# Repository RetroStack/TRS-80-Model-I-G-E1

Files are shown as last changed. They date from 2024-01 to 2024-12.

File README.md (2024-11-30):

# TRS-80 Model 1 (Rev G) Replica - E1

This project is a faithful reimplementation of the mainboard of the iconic TRS-80 Model 1 (Revision G) computer. My own revision, the E1, is designed to replicate the original system's functionality by using a PCB design 1-to-1 to the original, including components, interfaces, and even traces. The entire project is available under the MIT license.

E1 Replica

## Project Details

### Latest Files

In the "Latest" folder, you'll find the most up-to-date design files, including:

- Gerber files suitable for popular online PCB manufacturers like [PCBWay](/Latest/TRS80_Model_I_G_E1_Gerber_PCBWay.zip) and [JLCPCB](/Latest/TRS80_Model_I_G_E1_Gerber_JLCPCB.zip). Most manufacturers should be fine with either.
- A Bill of Materials (BOM) in both [CSV](/Latest/TRS80_Model_I_G_E1_BOM.csv) and [PDF](/Latest/TRS80_Model_I_G_E1_BOM.pdf) formats. (Also, see the list below.)
- Layers exported in PDF and SVG formats.
- The [full schematics](/Latest/TRS80_Model_I_G_E1_Schematics.pdf) of the E1 replica which is 1:1 to the original G board.
- A simple [Assembly Guide](/Latest/TRS80_Model_I_G_E1_AssemblyGuide.pdf) in PDF format.

### Implementation

E1 has been implemented using KiCAD 7. The KiCAD project files are included in this repository.

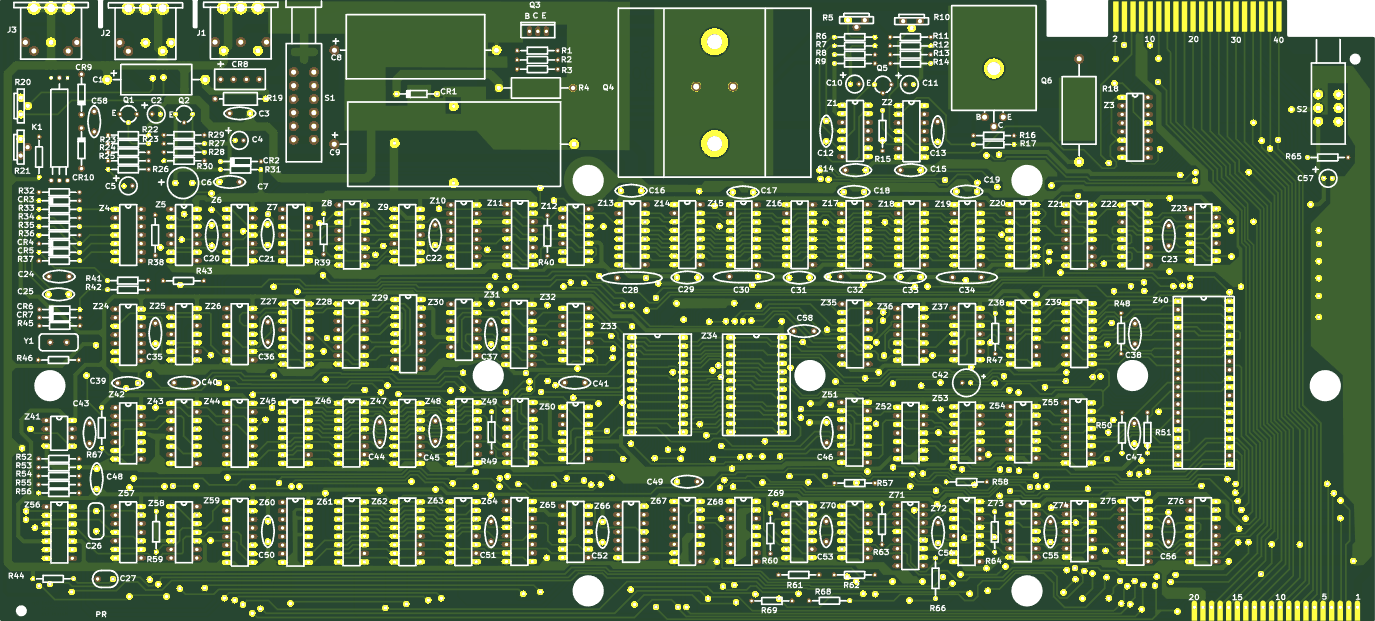
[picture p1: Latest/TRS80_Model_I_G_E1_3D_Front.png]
E1 Replica Front

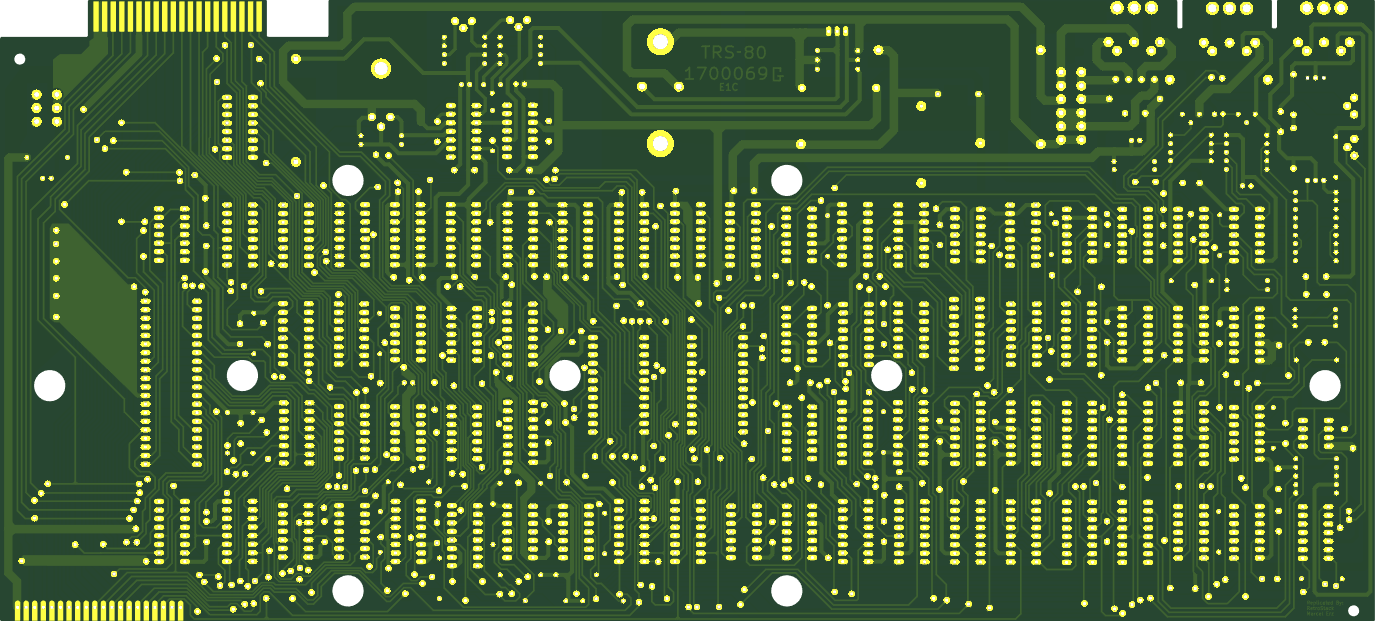
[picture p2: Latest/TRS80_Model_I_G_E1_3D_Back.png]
E1 Replica Back


### Assembly Instructions

For each step, check if there is a connection between pad 1, 8, 9, 16 on Z18 (all four corners of the dynamic RAM IC). That IC needs all 3 voltages with ground. If any of them are shorted, then you know what you did most recently. Finding the cause of the short should then be relatively easy.

1. (optional) Install sockets for all ICs. You probably want to skip Z3 and Z71, if you want to use DIP switches instead.
2. Install all diodes. These diodes are hard to read and if you accidentally mix them up, you might end up with incorrect voltages on the rails. Also, make sure to orient them correctly. There should be a black band on one side of the glass diode. Match this with the "thicker" side of the diode on the PCB. Installing first the shorter components will make sure you still can flip the board around and solder things easily.
3. Install all resistors. Resistors do not have an orientation. Skip the potentiometers for now. When installing the C*R67 (yes, there is a "C*"), this is an unmarked resistor between relay and the R21 potentiometer. This should be a 220 ohm 0.5W resistor (a bit larger than the others). There is another R67 which is next to Z42, which is a 4.7k Ohm resistor 0.25W (same size as most of the others).
4. Install all disc-like capacitors. Do not install the electrolytic capacitors yet! All other capacitors are rather small and orientation isn't important. The C58 next to the relay stays empty. Do not install it there. Instead, there is another (!!!) C58 next to the ROMs in the middle of the PCB.
5. Install all transistors, including the ones with the heatsinks. The TIP29 should go into Q3 (metal side away from board towards the Q3 label) while the TIP32C should go into Q6 (lay flat with heatsink; bend legs wit needle-nose pliers to fit). Don't forget to add thermal paste between heatsink and transistors. Make sure to add the screws and nuts and that it fits tightly as the screws themself connect traces. Not having them properly installed will result in a non-functioning system. The smaller black transistors have one flat side. These should all face towards the bottom of the board towards all the ICs (the middle leg needs to be bend slightly out to fit).
6. Install the crystal (no orientation), relay (match orientation on PCB; three legs towards the bottom), full-bridge rectifier (CR8; match "+" marking on component with PCB marking), all DIN connectors, both switches, keyboard connector (if bend, bend it upwards - towards the CPU to fit in the case), and potentiometers (only goes in one way). You can also install the DIP switches, if you go with that (numbers on the left side and "ON" label on the right).
7. Install all electrolytic capacitors. Make sure the orientation is correct! Modern capacitors mark the "-" side. On the PCB, the positive side is marked. All electrolytic capacitors on the PCB are oriented the same way EXCEPT C42 (!!!). Incorrect orientation may result in a small explosion (loud and smokey, but probably not dangerous).
8. Only install Z1 & Z2 to calibrate the power supply. Don't install any of the other ICs yet!!!
9. Get Multimeter ready in voltage mode. Connect power, turn on S1. If something starts to smell burned, turn S1 off and disconnect power.
10. Check voltage between pad 1 (-5V) and pad 16 (GND) on Z18. It should be around -5.1V to -5.2V. Since this is clamped with a zener diode, this should be pretty accurate. There is nothing that needs to be calibrated here. If the voltage goes beyond -5.3V, check R19 (may be really hot! careful!). If R19 is hot to the touch, your power supply is probably broken. (I've seen this on one power supply while another one didn't have that problem.)
11. Check voltage between pad 8 (+12V) and pad 16 (GND) on Z18. It should be around +12.0V. If it isn't, change the R10 potentiometer. If it is +/-0.5V off, then this is fine. But, try to get it as close to the desired voltage as possible.
12. (You need to calibrate +12V first before going to this next step!!!) Check voltage between pad 9 (+5V) and pad 16 (GND) on Z18. It should be around +5.0V. If it isn't, change the R5 potentiometer. If it is +/-0.5V off, then this is fine. But, also here, try to get it close to the desired voltage.
13. Re-check all the voltages after calibration, just to be sure.
14. Turn off S1 and disconnect power. Do this for each of the following steps. After each change, re-check the voltages at Z18 to find shorts quickly.
15. Start inserting the ICs. Focus on the 74LSxx ICs first. They are cheap and are easily recoverable in case there is a short somewhere and you start frying ICs. May be do 2-4 chips at a time and re-check the voltages at Z18. Do this systematically from left to right and top to bottom, so you know which you inserted most recently. If one of the voltages changes significantly at Z18 (+/- 2V and more), then you probably have a short with the most recent ICs. Do not insert the CPU, ROMs, character generator, and RAMs (static (2102) and dynamic ones (4116)) for now. They are expensive to replace if they fry.
16. Insert the 74Cxx ICs. These ICs are also cheap, but they are very sensitive. If all voltages are good, then they are good to install.
17. Connect to a monitor. Use a CRT, if possible, as video calibration is easier. LCD works too, but the reaction time is slow and requires a longer wait time after each change.
18. After turning on monitor and S1, you should see white blocks on a black background. If you don't see it, try changing R20 (vertical sync) and R21 (horizontal sync). If all fails, try to center both potentiometer. This usually results in a non-optimal picture, but a picture non-the-less. You can then calibrate.
19. (Don't forget to turn off system!) Insert the static video RAM (2102). These ICs only require +5V.
20. Now you need to configure the memory addresses and the memory configuration. With DIP switches, configure as follows:

- (memory location configuration) Z3: Switch 1 to the left, while all others are to the right. This is the configuration for 12k ROM and 16k RAM.
- (memory type configuration) Z71: Switch 1, 3, 5 to the right while all others are to the left. This is the configuration for 16k RAM modules.

21. Insert the dynamic RAM (4116). These ICs require all three voltages.
22. Insert CPU. Not much should have changed from the video calibration up until now. The next step will change that.
23. Insert character generator. Instead of white blocks, you should see (random) characters. The system doesn't clear the video memory yet since no ROM is installed.
24. Install ROM. This should be a Level II v1.3. If you don't have this, you probably need additional circuity to make these work. You can also burn the [diag ROM](https://github.com/misterblack1/trs80-diagnosticrom/blob/main/trs80m13diag.bin) on a 2k ROM to test the system. The diag ROM should work for all revisions of the TRS-80 Model 1.
25. At this point, you should see a prompt showing "Memory Size?" that keeps blinking (if it is the normal system ROM). The reason for the blinking is that the keyboard is not yet connected and the system recognizes keypresses. Install the keyboard with the IDC cable (if you installed a header).
26. Now, you should be able to use the system. Try to hold the left SHIFT key and press the right arrow key and the text size should increase, switching the video modes. (It is OK when some characters are skipped. That is normal.) The CLEAR key should reset it to the original video mode and clear the screen.
27. Try running a "Hello World!" program: 10 PRINT "Hello World!" (Return) 20 GOTO 10 (Return) RUN (Return). You can stop with the BREAK key.

### Ordering Instructions

When ordering the board from a PCB manufacturer, you can select the following to get a more faithful version of the board:

```
Dimension: 407mm x 184mm
Layers: 2
Base Material: FR-4 TG 135-140 (and up)
PCB Thickness: 1.6mm
PCB Color: Green
Silkscreen Color: White
Via Covering: Untented
Surface Finish: Lead Free HASL
Outer Copper Weight: 1oz
Gold Fingers / Card Edge: yes (chamfer: 30 degrees)
Castellated Holes: no
```

Additionally, supply the following comment for the manufacturer:

> Card edge is only on the upper right. The bottom right is just a connector and does not need to be chamfered.
>
> There are some missing pads on the top layer. That is correct. Please leave them as-is.

This addresses recurring questions from some of the interesting designs that were used on the original board which was replicated. See the ["Curiosities"](/Curiosities.md) page.

### Bill of Materials (BOM)

Below is a list of materials needed to assemble a complete system. Please note that the links and prices (scroll to the right to see them; as of January 22, 2024) will not be updated in the future and should only be used as a reference for locating the correct items.

Note: Links and alternatives are provided to assist you in finding the necessary components. I cannot guarantee the complete accuracy or reliability of all these links and alternatives. Please check it for yourself!

| Reference | Qty | Description | Source Comment | Source Cost USD | Source Total Cost USD | Source |
| --- | --- | --- | --- | --- | --- | --- |
| C1 | 1 | 220uF 16V polarized capacitor | | 1.48 | 1.48 | [Mouser](https://www.mouser.com/ProductDetail/598-227TTA050M) |
| C2, C4, C5, C10, C11, C57 | 6 | 10uF 16V polarized capacitor | | 0.29 | 1.74 | [Mouser](https://www.mouser.com/ProductDetail/598-106RMR050M) |
| C3, C7, C14, C15 | 4 | 0.01uF 24V (103) capacitor | | 0.23 | 0.92 | [Mouser](https://www.mouser.com/ProductDetail/594-D103Z25Z5VF63L6R) |
| C6 | 1 | 100uF 16V polarized capacitor | | 0.37 | 0.37 | [Mouser](https://www.mouser.com/ProductDetail/647-UVZ1J101MPD) |
| C8 | 1 | 2200uF 35V polarized capacitor | | 5.31 | 5.31 | [Mouser](https://www.mouser.com/ProductDetail/598-228TTA063M) |
| C9 | 1 | 10000uF 16V polarized capacitor | | 7.87 | 7.87 | [Mouser](https://www.mouser.com/ProductDetail/598-109TTA025M) |
| C12, C13 | 2 | 470pF (471) capacitor | | 0.23 | 0.46 | [Mouser](https://www.mouser.com/ProductDetail/594-D471K20Y5PH6UJ5R) |
| C16, C17, C18, C19, C22, C23, C28, C29, C30, C31, C32, C33, C34, C35, C36, C37, C38, C39, C40, C41, C44, C45, C46, C47, C48, C49, C50, C51, C52, C53, C54, C55, C56, C58 | 34  | 0.1uF 25V (104) capacitor | | 0.17 | 5.78 | [Mouser](https://www.mouser.com/ProductDetail/594-K104K10X7RF53L2) |
| C20 | 1 | 330pF (331) capacitor | | 0.3 | 0.3 | [Mouser](https://www.mouser.com/ProductDetail/594-F331K29Y5RP6UK5R) |
| C21 | 1 | 750pF (750) capacitor | | 0.37 | 0.37 | [Mouser](https://www.mouser.com/ProductDetail/80-C322C751K3G5TA) |
| C24, C25 | 2 | 220pF (221) capacitor | | 0.23 | 0.46 | [Mouser](https://www.mouser.com/ProductDetail/594-D221K20Y5PF63J5R) |
| C26 | 1 | 0.047uF (47nF) capacitor | | 1.9 | 1.9 | [Mouser](https://www.mouser.com/ProductDetail/594-222236755473) |
| C27 | 1 | 0.022uF (22nF) capacitor | | 1.34 | 1.34 | [Mouser](https://www.mouser.com/ProductDetail/594-2222-366-45223) |
| C42 | 1 | 22uF 16V polarized capacitor | | 0.1 | 0.1 | [Mouser](https://www.mouser.com/ProductDetail/710-860010372002) |
| C43 | 1 | 47pF (47) capacitor | | 0.4 | 0.4 | [Mouser](https://www.mouser.com/ProductDetail/594-S470K25SL0N63L6R) |
| CR1 | 1 | 1N4735 Zener diode | | 0.25 | 0.25 | [Mouser](https://www.mouser.com/ProductDetail/512-1N4735A) |
| CR2 | 1 | 1N5231 Zener diode | | 0.15 | 0.15 | [Mouser](https://www.mouser.com/ProductDetail/512-1N5231B) |
| CR3, CR4, CR5, CR6, CR7 | 5 | 1N4148 | Diode | 0.1 | 0.5 | [Mouser](https://www.mouser.com/ProductDetail/512-1N4148) |
| CR8 | 1 | MDA202 Diode bridge, +ve/AC/AC/-ve | Replacement | 0.61 | 0.61 | [Mouser](https://www.mouser.com/ProductDetail/621-KBP210G) |
| CR9, CR10 | 2 | 1N982 Schottky diode | Replacement, Lower (39V instead of 75V) | 0.26 | 0.52 | [Mouser](https://www.mouser.com/ProductDetail/78-1N4754A-TAP) |
| J1, J2, J3 | 3 | 5-pin DIN connector (5-pin DIN-5 stereo) | For metal connector only. The plastic plugs don't fit in it. | 0.386 | 1.158 | [AliExpress](https://www.aliexpress.us/item/2255801077942335.html) |
| J100 | 1 | 01x20 Generic connector, single row, 01x20 | | 0.5 | 0.5 | [Mouser](https://www.mouser.com/ProductDetail/649-1012937992002BLF) |
| K1 | 1 | Relay SPST, Normally Open | Slightly smaller than original | 14.84 | 14.84 | [DigiKey](https://www.digikey.com/en/products/detail/sensata-cynergy3/S2-05P/4425813) |
| Q1 | 1 | 2N3904 0.2A Ic, 40V Vce, Small Signal NPN Transistor, TO-92 | | 0.35 | 0.35 | [Mouser](https://www.mouser.com/ProductDetail/512-2N3904BU) |
| Q2, Q5 | 2 | 2N3906 -0.2A Ic, -40V Vce, Small Signal PNP Transistor, TO-92 | | 0.28 | 0.56 | [Mouser](https://www.mouser.com/ProductDetail/512-2N3906BU) |
| Q3 | 1 | TIP29A (BCE) NPN transistor | | 1.01 | 1.01 | [Mouser](https://www.mouser.com/ProductDetail/863-TIP29AG) |
| Q4 | 1 | 2N6594 (BEC) PNP transistor | Replacement (Other: RS2040, MJ2955G) | 4.73 | 4.73 | [Mouser](https://www.mouser.com/ProductDetail/863-MJ2955G) |
| Q6 | 1 | MJE34 (BCE) PNP transistor | Replacement | 0.67 | 0.67 | [Mouser](https://www.mouser.com/ProductDetail/511-TIP32C) |
| - | 1 | Q4 Heatsink | | 1.01 | 1.01 | [Mouser](https://www.mouser.com/ProductDetail/532-506007B00) |
| - | 1 | Q6 Heatsink | Smaller than original | 0.3 | 0.3 | [Mouser](https://www.mouser.com/ProductDetail/532-507302B00) |
| R1 | 1 | 68 Resistor 0.25W | | 0.1 | 0.1 | [Mouser](https://www.mouser.com/ProductDetail/603-CFR-25JB-52-68R) |
| R2 | 1 | 2.7k Resistor 0.25W | | 0.1 | 0.1 | [Mouser](https://www.mouser.com/ProductDetail/603-CFR-25JR-522K7) |
| R3 | 1 | 750 Resistor 0.25W | | 0.1 | 0.1 | [Mouser](https://www.mouser.com/ProductDetail/603-CFR-25JB-52-750R) |
| R4 | 1 | 0.33 Resistor 2W | | 0.45 | 0.45 | [Mouser](https://www.mouser.com/ProductDetail/603-CFR2WSJT-73-0R33) |
| R5, R10 | 2 | 1k Potentiometer | | 0.57 | 1.14 | [Mouser](https://www.mouser.com/ProductDetail/531-PT10H-1K-S) |
| R6, R7, R16, R53 | 4 | 1.2k Resistor 0.25W | | 0.1 | 0.4 | [Mouser](https://www.mouser.com/ProductDetail/603-CFR-25JB-52-1K2) |
| R8 | 1 | 100k Resistor 0.25W | | 0.1 | 0.1 | [Mouser](https://www.mouser.com/ProductDetail/603-CFR-25JB-52-100K) |
| R9, R11, R12 | 3 | 3.3k Resistor 0.25W | | 0.1 | 0.3 | [Mouser](https://www.mouser.com/ProductDetail/603-CFR-25JB-52-3K3) |
| R13 | 1 | 2.2k Resistor 0.25W | | 0.1 | 0.1 | [Mouser](https://www.mouser.com/ProductDetail/603-CFR-25JT-52-2K2) |
| R14 | 1 | 12k Resistor 0.25W | | 0.1 | 0.1 | [Mouser](https://www.mouser.com/ProductDetail/603-CFR-25JB-52-12K) |
| R15 | 1 | 1.5k Resistor 0.25W | | 0.1 | 0.1 | [Mouser](https://www.mouser.com/ProductDetail/603-CFR-25JT-52-1K5) |
| R17 | 1 | 2k Resistor 0.25W | | 0.1 | 0.1 | [Mouser](https://www.mouser.com/ProductDetail/603-CFR-25JB-52-2K) |
| R18 | 1 | 5.6 Resistor 3W | | 0.57 | 0.57 | [Mouser](https://www.mouser.com/ProductDetail/279-EP3WSS5R6J) |
| R19, C_R67 | 2 | 220 Resistor 0.5W | | 0.1 | 0.1 | [Mouser](https://www.mouser.com/ProductDetail/603-CFR-50JB-52-220R) |
| R20, R21 | 2 | 100k Potentiometer | | 0.57 | 1.14 | [Mouser](https://www.mouser.com/ProductDetail/531-PT10H-100K-S) |
| R22 | 1 | 75 Resistor 0.25W | | 0.1 | 0.1 | [Mouser](https://www.mouser.com/ProductDetail/603-CFR-25JB-52-75R) |
| R23 | 1 | 120 Resistor 0.25W | | 0.1 | 0.1 | [Mouser](https://www.mouser.com/ProductDetail/603-CFR-25JB-52-120R) |
| R24 | 1 | 680k Resistor 0.25W | | 0.1 | 0.1 | [Mouser](https://www.mouser.com/ProductDetail/603-CFR-25JB-52-680K) |
| R25 | 1 | 1.6M Resistor 0.25W | | 0.1 | 0.1 | [Mouser](https://www.mouser.com/ProductDetail/603-CFR-25JB-52-1M6) |
| R26, R42 | 2 | 1M Resistor 0.25W | | 0.1 | 0.2 | [Mouser](https://www.mouser.com/ProductDetail/603-CFR-25JT-52-1M) |
| R27, R64 | 2 | 330 Resistor 0.25W | | 0.1 | 0.2 | [Mouser](https://www.mouser.com/ProductDetail/603-CFR-25JB-52-330R) |
| R28 | 1 | 270 Resistor 0.25W | | 0.1 | 0.1 | [Mouser](https://www.mouser.com/ProductDetail/603-CFR-25JB-52-270R) |
| R29 | 1 | 1.8k Resistor 0.25W | | 0.1 | 0.1 | [Mouser](https://www.mouser.com/ProductDetail/603-CFR-25JB-52-1K8) |
| R30 | 1 | 47 Resistor 0.25W | | 0.1 | 0.1 | [Mouser](https://www.mouser.com/ProductDetail/603-CFR-25JB-52-47R) |
| R31 | 1 | 10 Resistor 0.25W | | 0.1 | 0.1 | [Mouser](https://www.mouser.com/ProductDetail/603-CFR-25JT-52-10R) |
| R32, R43, R44, R47, R65 | 5 | 10k Resistor 0.25W | | 0.1 | 0.5 | [Mouser](https://www.mouser.com/ProductDetail/603-CFR-25JB-52-10K) |
| R33, R36 | 2 | 360k Resistor 0.25W | | 0.1 | 0.2 | [Mouser](https://www.mouser.com/ProductDetail/603-CFR-25JB-52-360K) |
| R34, R35, R38, R41, R45 | 5 | 470k Resistor 0.25W | | 0.1 | 0.5 | [Mouser](https://www.mouser.com/ProductDetail/603-CFR-25JB-52-470K) |
| R37 | 1 | 560k Resistor 0.25W | | 0.1 | 0.1 | [Mouser](https://www.mouser.com/ProductDetail/603-CFR-25JB-52-560K) |
| R39, R40, R48, R49, R50, R51, R57, R58, R59, R60, R61, R62, R63, R66, R67, R68, R69 | 17  | 4.7k Resistor 0.25W | | 0.1 | 1.7 | [Mouser](https://www.mouser.com/ProductDetail/603-CFR-25JB-52-4K7) |
| R46, R52 | 2 | 910 Resistor 0.25W | | 0.1 | 0.2 | [Mouser](https://www.mouser.com/ProductDetail/603-CFR-25JB-52-910R) |
| R54, R55 | 2 | 7.5k Resistor 0.25W | | 0.1 | 0.2 | [Mouser](https://www.mouser.com/ProductDetail/603-CFR-25JB-52-7K5) |
| R56 | 1 | 220k Resistor 0.25W | | 0.1 | 0.1 | [Mouser](https://www.mouser.com/ProductDetail/603-CFR-25JB-52-220K) |
| S1 | 1 | Power 4PST | No Cap | 4.34 | 4.34 | [DigiKey](https://www.digikey.com/en/products/detail/c-k/F4UEE/417520) |
| S2 | 1 | Reset DPST | Red Cap | 1.815 | 1.815 | [AliExpress](https://www.aliexpress.us/item/3256804467086494.html) |
| Y1 | 1 | 10.6445 MHz Two pin crystal | Only 10.6MHz | 0.73 | 0.73 | [Mouser](https://www.mouser.com/ProductDetail/449-LFXTAL028537BULK) |
| Z1, Z2 | 2 | LM723C Linear Regulator (adjustable) | | 1.04 | 2.08 | [Mouser](https://www.mouser.com/ProductDetail/595-UA723CN) |
| Z3, Z71 | 2 | 8-Bit DIP Switch | Replacement | 2.07 | 4.14 | [Mouser](https://www.mouser.com/ProductDetail/710-418117270908) |
| Z4 | 1 | LM3900 Quad operational amplifier | | 0.6 | 0.6 | [Mouser](https://www.mouser.com/ProductDetail/595-LM3900NE4) |
| Z5 | 1 | 74C00 quad 2-input NAND gate | 74HC00 works in a pinch, but suboptimal video. | ~2.50 | ~2.50 | eBay/Jameco |
| Z6, Z57 | 2 | 74C04 Hex Inverter | 74HC00 works in a pinch, but suboptimal video. | 2.49 | 4.98 | [Jameco](https://www.jameco.com/webapp/wcs/stores/servlet/ProductDisplay?productId=44231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) |
| Z7, Z69, Z70 | 3 | 74LS74 Dual D Flip-flop, Set & Reset | | 0.49 | 1.47 | [Mouser](https://www.mouser.com/ProductDetail/595-SN74LS74AN) |
| Z8 | 1 | 74LS153 Dual Multiplexer 4 to 1 | | 1.13 | 1.13 | [Mouser](https://www.mouser.com/ProductDetail/595-SN74LS153N) |
| Z9, Z42, Z52 | 3 | 74LS04 Hex Inverter | | 0.67 | 2.01 | [Mouser](https://www.mouser.com/ProductDetail/595-SN74LS04N) |
| Z10, Z11 | 2 | 74LS166 Shift Register 8-bit, parallel load | | 1.24 | 2.48 | [Mouser](https://www.mouser.com/ProductDetail/595-SN74LS166AN) |
| Z12, Z32, Z50, Z65 | 4 | 74LS93 Divide by 2 & 8 counter | | 3.04 | 12.16 | [Mouser](https://www.mouser.com/ProductDetail/595-SN74LS93N) |
| Z13, Z14, Z15, Z16, Z17, Z18, Z19, Z20 | 8 | 4116 16kBit x 1 Bit Dynamic RAM | | 3.95 | 31.6 | [Jameco](https://www.jameco.com/z/4116-15-Major-Brands-IC-4116-15-DRAM-16-384-Bit-16Kx1-150ns-5V_41339.html) |
| Z21 | 1 | 74LS156 Dual 2 to 4 lines Decoder/Demultiplexer, Open Collector | | 0.75 | 0.75 | [Mouser](https://www.mouser.com/ProductDetail/595-SN74LS156N) |
| Z22, Z38, Z39, Z44, Z55, Z60, Z67, Z68, Z72, Z75, Z76 | 11  | 74LS367 Hex buffer 3-State outputs | | 1.44 | 15.84 | [Mouser](https://www.mouser.com/ProductDetail/595-SN74LS367AN) |
| Z23, Z25, Z36, Z73 | 4 | 74LS32 Quad 2-input OR | | 0.56 | 2.24 | [Mouser](https://www.mouser.com/ProductDetail/595-SN74LS32N) |
| Z24, Z53 | 2 | 74LS132 Quad 2-input NAND Schmitt trigger | | 1.03 | 2.06 | [Mouser](https://www.mouser.com/ProductDetail/595-SN74LS132N) |
| Z26 | 1 | 74LS20 Dual 4-input NAND | | 1.28 | 1.28 | [Mouser](https://www.mouser.com/ProductDetail/595-SN74LS20N) |
| Z27, Z59 | 2 | 74LS175 4-bit D Flip-Flop, reset | | 1.02 | 2.04 | [Mouser](https://www.mouser.com/ProductDetail/595-SN74LS175N) |
| Z28 | 1 | 74LS174 Hex D-type Flip-Flop, reset | | 1.12 | 1.12 | [Mouser](https://www.mouser.com/ProductDetail/595-SN74LS174N) |
| Z29 | 1 | MCM6670 128 x 7 x 5 Character Generator | Adapter needed | | 0 | [GitHub](https://github.com/RetroStack/MCM776x_CharGen_Adapter) |
| Z30, Z37 | 2 | 74LS02 quad 2-input NOR gate | | 0.55 | 1.1 | [Mouser](https://www.mouser.com/ProductDetail/595-SN74LS02N) |
| Z31, Z35, Z43, Z49, Z51, Z64 | 6 | 74LS157 Quad 2 to 1 line Multiplexer | | 0.88 | 5.28 | [Mouser](https://www.mouser.com/ProductDetail/595-SN74LS157N) |
| Z33 | 1 | 2364 (20-pin Low) 2364 64kBit (8kb x 8) PROM | Adapter needed | | 0 | - |
| Z34 | 1 | 2332 (20- & 21-pin Low) 2332 32kBit (4kb x 8) PROM | Adapter needed | | 0 | - |
| Z40 | 1 | Z80 CPU | | 9.62 | 9.62 | [Mouser](https://www.mouser.com/ProductDetail/692-Z84C0010PEG) |
| Z41 | 1 | 75452 Dual-Peripheral Drivers for High-Current, High-Speed Switching | | 0.9 | 0.9 | [Mouser](https://www.mouser.com/ProductDetail/595-SN75452BP) |
| Z45, Z46, Z47, Z48, Z61, Z62, Z63 | 7 | 2102 1K Static RAM (SRAM) | 7th IC needed for lowercase mod | 2.95 | 20.65 | [Jameco](https://www.jameco.com/z/MM2102AN-4-National-Semiconductor-IC-MM2102AN-4-NMOS-SRAM-1024-Bit-1024x1-250ns-DIP-16_2287991.html) |
| Z54 | 1 | 74LS30 8-input NAND | | 1.18 | 1.18 | [Mouser](https://www.mouser.com/ProductDetail/595-SN74LS30N) |
| Z56, Z58 | 2 | 74LS92 Divide by 12 counter | | 3.27 | 6.54 | [Mouser](https://www.mouser.com/ProductDetail/595-SN74LS92N) |
| Z66 | 1 | 74LS11 Triple 3-input AND | | 0.91 | 0.91 | [Mouser](https://www.mouser.com/ProductDetail/595-SN74LS11N) |
| Z74 | 1 | 74LS00 quad 2-input NAND gate | | 0.57 | 0.57 | [Mouser](https://www.mouser.com/ProductDetail/595-SN74LS00N) |
| | 1 | DIP-8 Socket | Optional | 0.49 | 0.49 | [Jameco](https://www.jameco.com/z/6100-8-R-Jameco-ValuePro-IC-Socket-8-Pin-Machine-Tooled-Low-Profile-0-3-Inch-Wide_51626.html) |
| | 30  | DIP-14 Socket | Optional | 0.75 | 22.5 | [Jameco](https://www.jameco.com/z/14MTLP-Jameco-ValuePro-Socket-IC-14-Pin-Machine-Tooled-Low-Profile-0-3-Inch-Wide_37197.html) |
| | 39  | DIP-16 Socket | Optional | 0.85 | 33.15 | [Jameco](https://www.jameco.com/z/16MTLP-Jameco-ValuePro-Socket-IC-16-Pin-Machine-Tooled-Low-Profile-0-3-Inch-Wide_37402.html) |
| | 1 | DIP-18 Socket | Optional | 0.99 | 0.99 | [Jameco](https://www.jameco.com/z/18MTLP-Jameco-ValuePro-18-Pin-Machine-Tooled-Low-Profile-IC-Socket-0-3-Inch-Wide_65585.html) |
| | 2 | DIP-24 Socket | Optional | 1.49 | 2.98 | [Jameco](https://www.jameco.com/z/24MTLP-6-Jameco-ValuePro-24-Pin-Machine-Tooled-Low-Profile-IC-Socket-0-6-Inch-Wide_39351.html) |
| | 1 | DIP-40 Socket | Optional | 1.69 | 1.69 | [Jameco](https://www.jameco.com/z/40MTLP-Jameco-ValuePro-40-Pin-Machine-Tooled-Low-Profile-IC-Socket-0-6-Inch-Wide_41136.html) |

### RetroStack Libraries

To work with this KiCAD project, you'll need the RetroStack libraries for KiCAD. Please [follow this link](https://www.github.com/RetroStack/KiCAD-Libraries) to access and install these libraries.

## Main TRS-80 Model 1 Repository

For additional resources related to the TRS-80 Model 1, be sure to check out the [central page for the TRS-80 Model 1](https://www.github.com/RetroStack/TRS-80-Model-I) on [RetroStack](https://www.github.com/RetroStack).

## Support this Project

RetroStack is passionate about exploring and preserving the legacy of older computer systems. My work involves creating detailed documentation and videos to share the knowledge. I am also dedicated to reviving these classic systems by reimplementing them and offering replacement parts at no cost. If you're keen on supporting this unique project, I invite you to visit my [Patreon page](https://www.patreon.com/RetroStack). Your support would be immensely valuable and greatly appreciated!

## License

This project is licensed under the MIT License - see the [LICENSE](LICENSE) file for details.

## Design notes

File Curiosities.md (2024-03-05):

# TRS-80 Model 1 (Rev G) - Curiosities

The original board had multiple errors and strange implementations, often caused by the limited capabilities of the manufacturing process, but also to save money. The following sections discuss some of the stranger features on the original PCB board, which were replicated when possible.

## Additional Capacitor

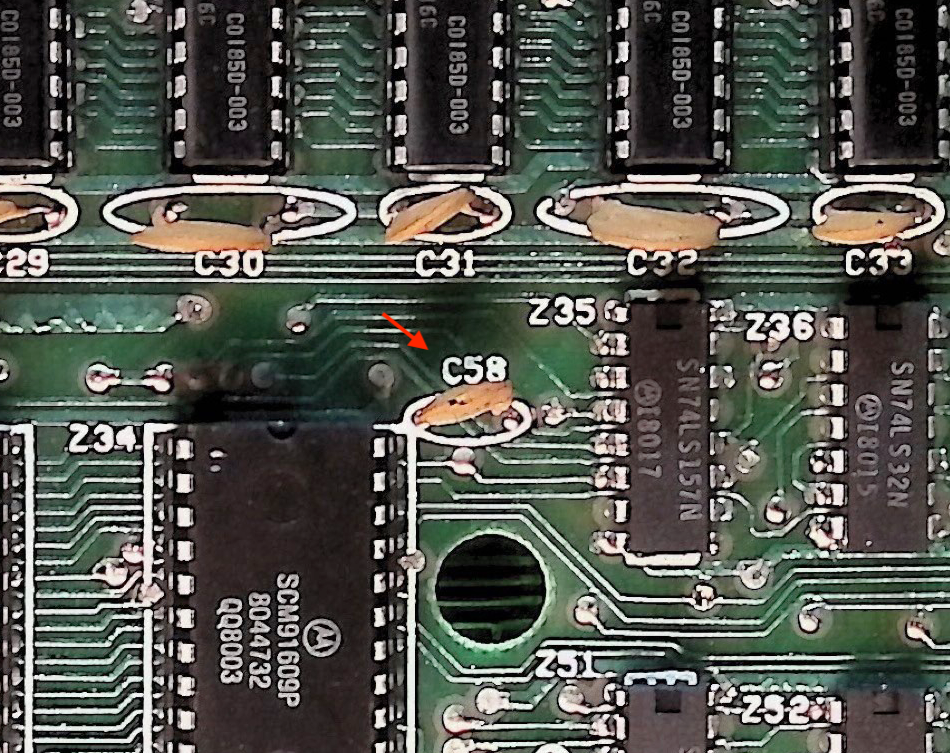
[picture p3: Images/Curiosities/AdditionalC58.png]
Additional Capacitor


Capacitor C58, located next to the ROMs, was never documented in the technical reference manual. My guess is that it was added later.

## Missing Capacitor

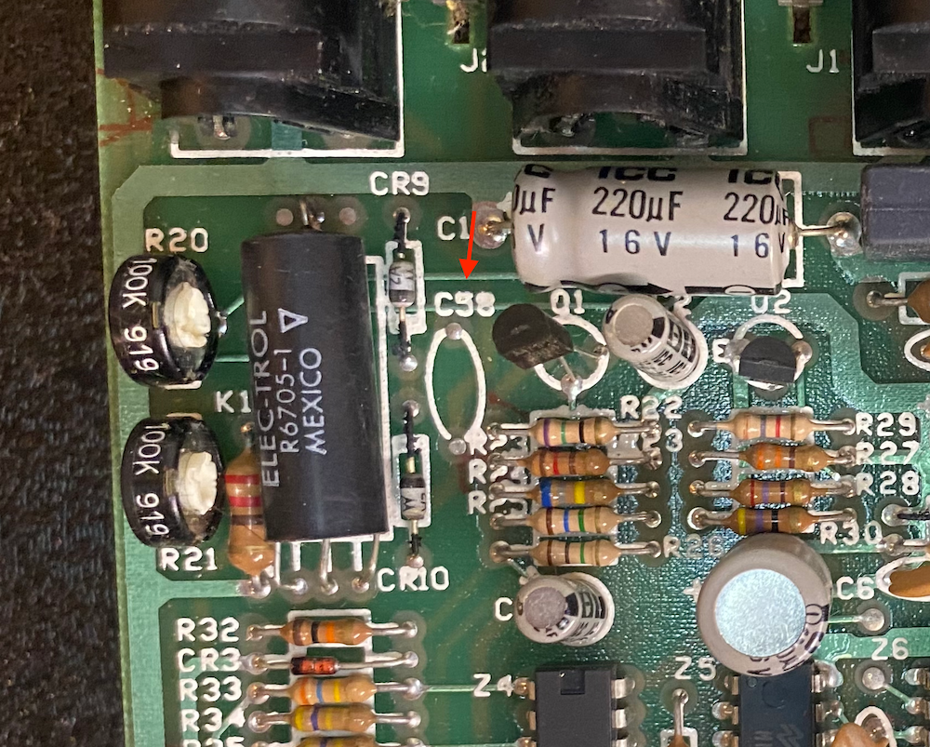
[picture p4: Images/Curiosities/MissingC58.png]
Missing Capacitor

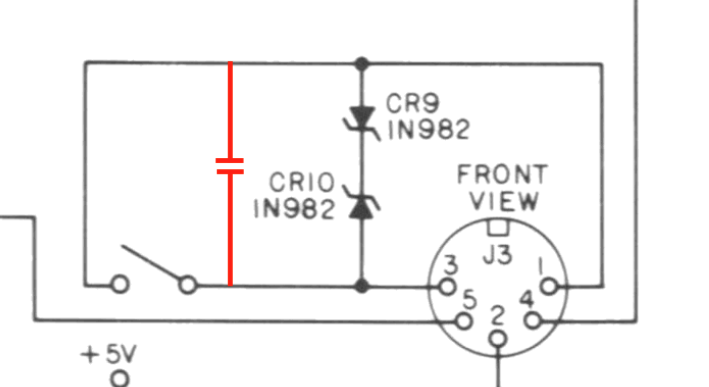
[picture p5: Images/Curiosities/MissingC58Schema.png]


There is, however, a capacitor missing on the board. This capacitor is also called C58 (yes, there are two of them) and is located right next to the relay. It is missing on all the boards I've seen, but I have added it to the schematics and included a note that it is missing on the PCB. This capacitor is actually part of the Cassette Remote control circuit and seems out of place there.

## Wrong Resistor

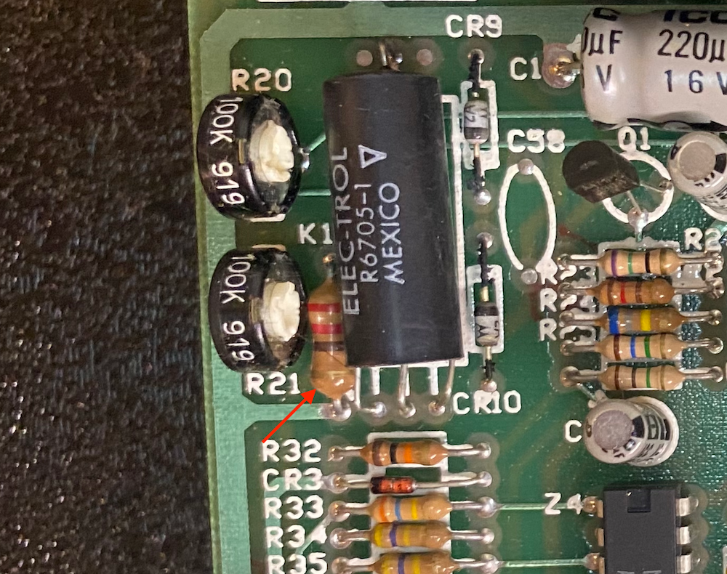
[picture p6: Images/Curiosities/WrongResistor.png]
Wrong Resistor

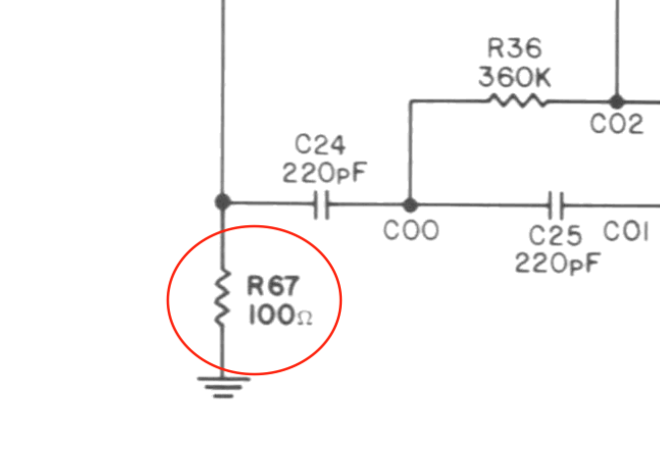
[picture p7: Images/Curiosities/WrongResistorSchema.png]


Next to the two potentiometers for the H- and V-Sync, there is supposed to be a 100 Ohm 0.25 Watt resistor, according to the technical documentation. However, on all the boards I have seen, there is actually a 220 Ohm 0.5 Watt resistor instead.

## Undocumented 8k RAM support

The board actually supports two different kinds of 8k ICs for the dynamic RAM. This is not documented in the technical reference manual or the user documentation. See Page 7 of the [new schematics](/Latest/TRS80_Model_I_G_E1_Schematics.pdf).

## Missing Pads (On the Top)

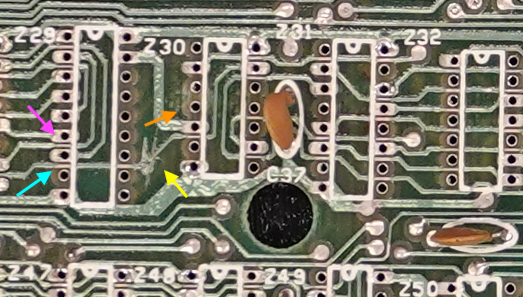
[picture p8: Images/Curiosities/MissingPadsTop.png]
Missing Pads on Original

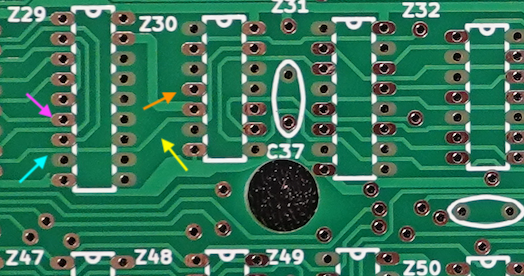
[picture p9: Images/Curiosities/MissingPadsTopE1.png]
Missing Pads on Replica


I’ve replicated the "missing pads" on the top of the board as they were on the original board. The pads are only connected at the bottom, so it's fine for them to be missing on the top.

But why was it done this way? At the time, the solder masks weren’t as precise and couldn't adequately cover the traces between pads (see purple/magenta and blue arrow). Bridging those pads and traces during soldering was (and still is) a common issue on these older boards (especially the traces or purple/magenta arrow). That isn’t the case with modern boards, but I still replicated this for the pads only (not the traces in between) to stay closer to the original without the risk of accidental bridging. I guess it's a good compromise.

Completely unconnected pins usually lacked pads on the top as well, but KiCAD doesn’t have an option for that, unfortunately. So, I kept them as they are (see orange arrow), meaning they have pads on both the top and bottom.

The yellow arrow is unrelated to this topic, but you can see the cut trace of the original board which is needed for the lower-case mod.

## Missing Pads (On the Bottom)

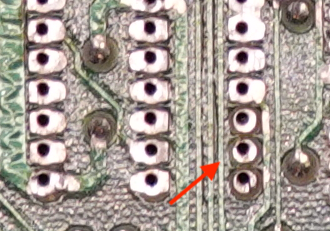
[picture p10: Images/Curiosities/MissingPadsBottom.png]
Missing Pads on Original

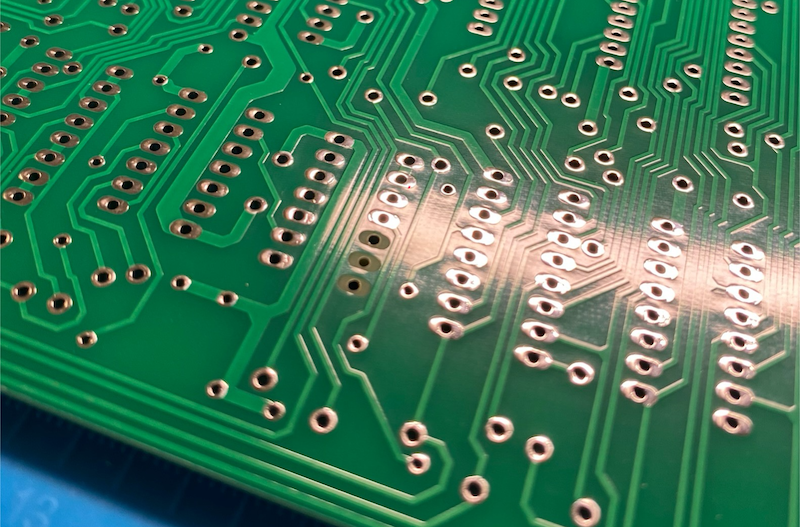
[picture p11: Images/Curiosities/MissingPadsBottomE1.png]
Missing Pads on Replica


I replicated three missing pads on the bottom of the board at Z69. While accurate to the original, it was a pain to solder the sockets to the pads while they rested on top of the board. I don’t use wave soldering as they did in the original, so that was just annoying. In the newest version of the board, I placed these pads back to make them easily solderable.

## Unused Vias

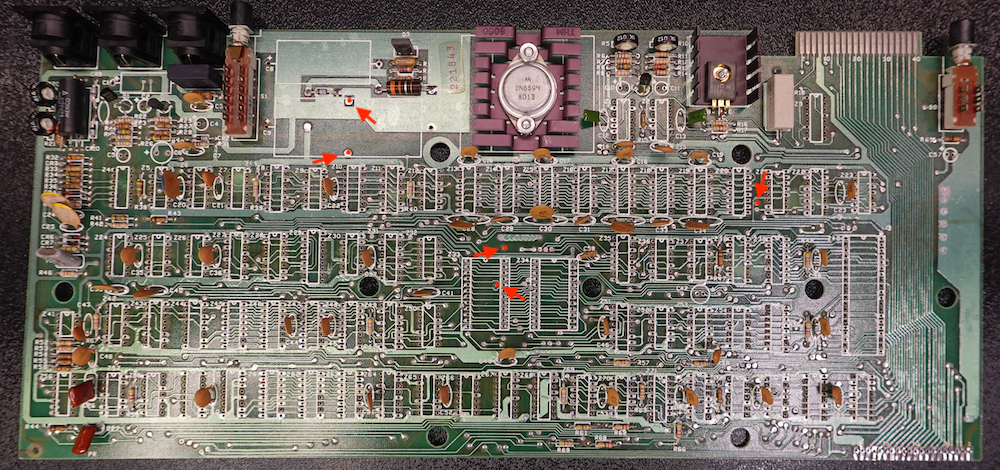
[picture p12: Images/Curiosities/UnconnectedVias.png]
Unconnected Vias


There are a bunch of unused vias on the board. I am not entirely sure why that is.

## Small Holes

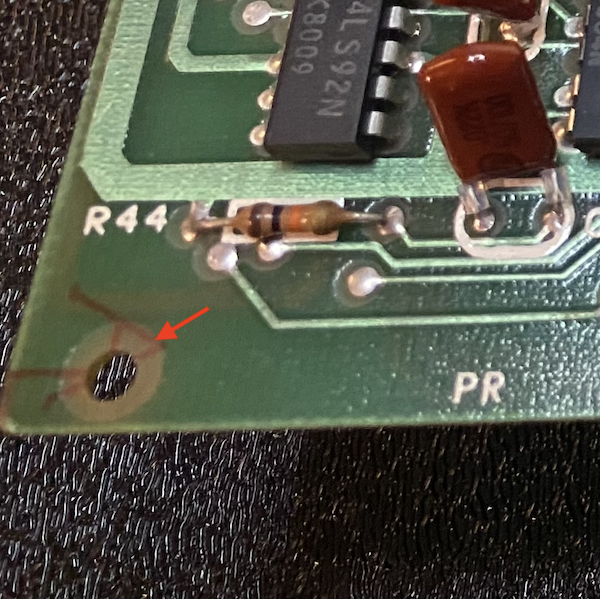
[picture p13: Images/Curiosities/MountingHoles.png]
Mounting Holes


At the edges of the board, you can see two rather small holes. These were used during the manufacturing process to keep the board in a known position, enabling the machines to create and assemble the board.

## Bumpy Traces and Zones

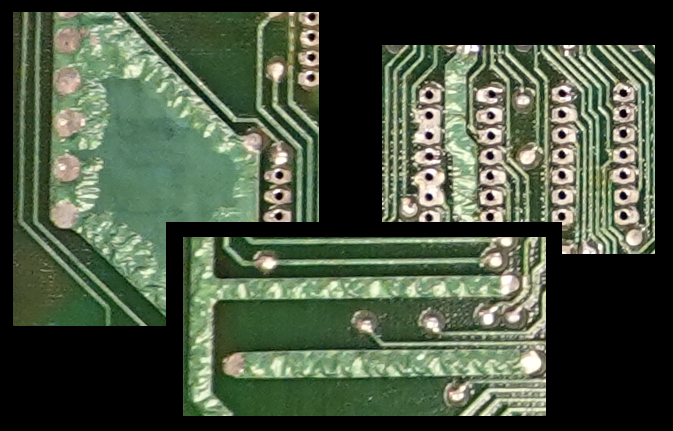
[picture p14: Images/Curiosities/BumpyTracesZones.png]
Bumpy Traces and Zones


If you ever wonder what these "bumpy" traces and fill zones are, they are not dissolving or anything of that nature. This is how they are supposed to be. The boards were assembled in this way. The traces and zones were tinned, then solder mask was applied, covering nearly everything. When the board was wave soldered with the components in place, these tinned traces melted again due to the heat and solidified shortly after. The tension of the solder mask kept them in somewhat random shapes and caused these bumps. You can actually see this if you put your soldering iron to a pad close to these bumps; you will see that the tin beneath the solder mask liquifies and can even be sucked out by a desoldering iron or pump.

Since the method of tinning has changed (using HASL nowadays) and I don't wave solder, this isn't happening anymore, and it is difficult and probably costly to replicate.

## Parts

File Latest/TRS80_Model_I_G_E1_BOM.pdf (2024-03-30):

### TRS80_Model_I_G_E1_BOM

SOURCE PCB REFERENCE | QTY | VALUE | COMPONENT NAME | COMPONENT DESCRIPTION | COMMENT
C1 | 1 | 220uF 16V | C_Polarized | Polarized capacitor
C2, C4, C5, C10, C11, C57 | 6 | 10uF 16V | C_Polarized | Polarized capacitor | C57 is located at the reset switch
C6 | 1 | 100uF 16V | C_Polarized | Polarized capacitor
C8 | 1 | 2200uF 35V | C_Polarized | Polarized capacitor
C9 | 1 | 10000uF 16V | C_Polarized | Polarized capacitor
C42 | 1 | 22uF 16V | C_Polarized | Polarized capacitor
C12, C13 | 2 | 470pF | C (471) | Unpolarized capacitor
C3, C7, C14, C15 | 4 | 0.01uF 24V | C (103) | Unpolarized capacitor
C16, C17, C18, C19, C22, C23, C28, C29, C30, C31, C32, C33, C34, C35, C36, C37, C38, C39, C40, C41, C44, C45, C46, C47, C48, C49, C50, C51, C52, C53, C54, C55, C56, C58 | 34 | 0.1uF 25V | C (104) | Unpolarized capacitor | C58 is located to the right of ROM B C58 next to the relay stays empty (!!!)
C20 | 1 | 330pF | C (331) | Unpolarized capacitor
C21 | 1 | 750pF | C (750) | Unpolarized capacitor
C24, C25 | 2 | 220pF | C (221) | Unpolarized capacitor
C43 | 1 | 47pF | C (47) | Unpolarized capacitor | C43 is located to the right of Z41
C26 | 1 | 0.047uF | C (47nF) | Unpolarized capacitor
C27 | 1 | 0.022uF | C (22nF) | Unpolarized capacitor
CR1 | 1 | 1N4735 | D_Zener | Zener diode
CR2 | 1 | 1N5231 | D_Zener | Zener diode
CR3, CR4, CR5, CR6, CR7 | 5 | 1N4148 | D | Diode
CR9, CR10 | 2 | 1N982 | D_Schottky | Schottky diode | Replacement can be lower than 75V
CR8 | 1 | MDA202 | D_Bridge_+AA- | Diode bridge, +ve/AC/AC/-ve | Replacement KBP210
J1, J2, J3 | 3 | Front View | DIN-5_180degree | 5-pin DIN connector (5-pin DIN-5 stereo)
J100 | 1 | Connector | Conn_01x20 | Generic connector, single row, 01x20
K1 | 1 | Relay_SPST-NO | TRS80_Model_I_Relay_NO | Relay SPST, Normally Open, EN50005 | Slightly smaller than original
Q1 | 1 | 2N3904 | 2N3904 | 0.2A Ic, 40V Vce, Small Signal NPN Transistor, TO-92
Q2, Q5 | 2 | 2N3906 | 2N3906 | -0.2A Ic, -40V Vce, Small Signal PNP Transistor, TO-92
Q3 | 1 | TIP29A | Q_NPN_BCE | NPN transistor, base/collector/emitter
Q4 | 1 | 2N6594 | Q_PNP_BEC | PNP transistor, base/emitter/collector | Replacement RS2040, MJ2955G
Q6 | 1 | MJE34 | Q_PNP_BCE | PNP transistor, base/collector/emitter | Replacement TIP32C
- | 1 | | | Q4 Heatsink
- | 1 | | | Q6 Heatsink | Smaller than original
R1 | 1 | 68 | | Resistor 0.25W (blue, grey, black, gold)
R2 | 1 | 2.7k | | Resistor 0.25W (red, violet, red, gold)
R3 | 1 | 750 | | Resistor 0.25W (violet, green, brown, gold)
R4 | 1 | 0.33 | | Resistor 2W (orange, orange, silver, gold)
R6, R7, R16, R53 | 4 | 1.2k | | Resistor 0.25W (brown, red, red, gold)
R8 | 1 | 100k | | Resistor 0.25W (brown, black, yellow, gold)
R9, R11, R12 | 3 | 3.3k | | Resistor 0.25W (orange, orange, red, gold)
R13 | 1 | 2.2k | | Resistor 0.25W (red, red, red, gold)
R14 | 1 | 12k | | Resistor 0.25W (brown, red, orange, gold)
R15 | 1 | 1.5k | | Resistor 0.25W (brown, green, red, gold)
R17 | 1 | 2k | | Resistor 0.25W (red, black, red, gold)
R18 | 1 | 5.6 | | Resistor 3W (green, blue, gold, gold)
R19, C_R67 | 2 | 220 | | Resistor 0.5W (red, red, brown, gold) | C_R67 is located to the left of K1
R22 | 1 | 75 | | Resistor 0.25W (violet, green, black, gold)
R23 | 1 | 120 | | Resistor 0.25W (brown, red, brown, gold)
R24 | 1 | 680k | | Resistor 0.25W (blue, grey, yellow, gold)
R25 | 1 | 1.6M | | Resistor 0.25W (brown, blue, green, gold)
R26, R42 | 2 | 1M | | Resistor 0.25W (brown, black, green, gold)
R27, R64 | 2 | 330 | | Resistor 0.25W (orange, orange, brown, gold)
R28 | 1 | 270 | | Resistor 0.25W (red, violet, brown, gold)
R29 | 1 | 1.8k | | Resistor 0.25W (brown, grey, red, gold)
R30 | 1 | 47 | | Resistor 0.25W (yellow, violet, black, gold)
R31 | 1 | 10 | | Resistor 0.25W (brown, black, black, gold)
R32, R43, R44, R47, R65 | 5 | 10k | | Resistor 0.25W (brown, black, orange, gold) | R44 is located in the bottom left corner R65 is located at the reset switch
R33, R36 | 2 | 360k | | Resistor 0.25W (orange, blue, yellow, gold)

1

R34, R35, R38, R41, R45 | 5 | 470k | | Resistor 0.25W (yellow, violet, yellow, gold)
R37 | 1 | 560k | | Resistor 0.25W (green, blue, yellow, gold)
R39, R40, R48, R49, R50, R51, R57, R58, R59, R60, R61, R62, R63, R66, R67, R68, R69 | 17 | 4.7k | | Resistor 0.25W (yellow, violet, red, gold) | R67 is located to the left of Z42
R46, R52 | 2 | 910 | | Resistor 0.25W (white, brown, brown, gold)
R54, R55 | 2 | 7.5k | | Resistor 0.25W (violet, blue, red, gold)
R56 | 1 | 220k | | Resistor 0.25W (red, red, yellow, gold)
R5, R10 | 2 | 1k | R_Potentiometer | Potentiometer
R20, R21 | 2 | 100k | R_Potentiometer | Potentiometer
S1 | 1 | Power | SW_4PST
S2 | 1 | Reset | SW_DPST
Y1 | 1 | 10.6445 MHz | Crystal | Two pin crystal | 10.6MHz replacement
Z1, Z2 | 2 | LM723C | LM723C_1 | Linear Regulator (adjustable)
Z3, Z71 | 2 | Jumper | TRS80ModelIX71 | 8-Bit DIP Switch | Replacement
Z4 | 1 | LM3900 | LM3900 | Quad operational amplifier
Z5 | 1 | 74C00 | 74LS00 | quad 2-input NAND gate
Z6, Z57 | 2 | 74C04 | 74LS04 | Hex Inverter
Z7, Z69, Z70 | 3 | 74LS74 | 74LS74 | Dual D Flip-flop, Set & Reset
Z8 | 1 | 74LS153 | 74LS153 | Dual Multiplexer 4 to 1
Z9, Z42, Z52 | 3 | 74LS04 | 74LS04 | Hex Inverter
Z10, Z11 | 2 | 74LS166 | 74LS166 | Shift Register 8-bit, parallel load
Z12, Z32, Z50, Z65 | 4 | 74LS93 | 74LS93 | Divide by 2 & 8 counter
Z13, Z14, Z15, Z16, Z17, Z18, Z19, Z20 | 8 | MK4116 | 4116 | 16kBit x 1 Bit Dynamic RAM
Z21 | 1 | 74LS156 | 74LS156 | Dual 2 to 4 lines Decoder/Demultiplexer, Open Collector
Z22, Z38, Z39, Z44, Z55, Z60, Z67, Z68, Z72, Z75, Z76 | 11 | 74LS367 | 74LS367_Split | Hex buffer 3-State outputs
Z23, Z25, Z36, Z73 | 4 | 74LS32 | 74LS32 | Quad 2-input OR
Z24, Z53 | 2 | 74LS132 | 74LS132 | Quad 2-input NAND Schmitt trigger
Z26 | 1 | 74LS20 | 74LS20 | Dual 4-input NAND
Z27, Z59 | 2 | 74LS175 | 74LS175 | 4-bit D Flip-Flop, reset
Z28 | 1 | 74LS174 | 74LS174 | Hex D-type Flip-Flop, reset
Z29 | 1 | MCM6670 | MCM6670P | 128 x 7 x 5 Character Generator | Adapter needed
Z30, Z37 | 2 | 74LS02 | 74LS02 | quad 2-input NOR gate
Z31, Z35, Z43, Z49, Z51, Z64 | 6 | 74LS157 | 74LS157 | Quad 2 to 1 line Multiplexer
Z33 | 1 | 2364_20L | 2364_20L | 2364 64kBit (8kb x 8) PROM | Adapter needed
Z34 | 1 | 2332_20L_21L | 2332_20L_21L | 2332 32kBit (4kb x 8) PROM | Adapter needed
Z40 | 1 | Z80CPU | Z80 | Z80 CPU
Z41 | 1 | 75452 | 75452 | Dual-Peripheral Drivers for High-Current, High-Speed Switching
Z45, Z46, Z47, Z48, Z61, Z62, Z63 | 7 | 2102 | 2102_1 | 1K Static RAM (SRAM) | Add another one for lower-case mod
Z54 | 1 | 74LS30 | 74LS30 | 8-input NAND
Z56, Z58 | 2 | 74LS92 | 74LS92 | Divide by 12 counter
Z66 | 1 | 74LS11 | 74LS11 | Triple 3-input AND
Z74 | 1 | 74LS00 | 74LS00 | quad 2-input NAND gate
Machined DIP Socket 8 pin | 1 | DIP-8 | DIP-8 | DIP-8 Socket | Optional
Machined DIP Socket 14 pin | 30 | DIP-14 | DIP-14 | DIP-14 Socket | Optional
Machined DIP Socket 16 pin | 39 | DIP-16 | DIP-16 | DIP-16 Socket | Optional
Machined DIP Socket 18 pin | 1 | DIP-18 | DIP-18 | DIP-18 Socket | Optional
Machined DIP Socket 24 pin | 2 | DIP-24 | DIP-24 | DIP-24 Socket | Optional
Machined DIP Socket 40 pin | 1 | DIP-40 | DIP-40 | DIP-40 Socket | Optional

2

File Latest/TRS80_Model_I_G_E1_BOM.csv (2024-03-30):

SOURCE PCB REFERENCE | QTY | VALUE | COMPONENT NAME | COMPONENT DESCRIPTION | COMMENT | EACH | TOTAL | SOURCE | SOURCE LINK
C1 | 1 | 220uF 16V | C_Polarized | Polarized capacitor |  | $1.48 | $1.48 | Mouser | https://www.mouser.com/ProductDetail/598-227TTA050M
C2, C4, C5, C10, C11, C57 | 6 | 10uF 16V | C_Polarized | Polarized capacitor | C57 is located at the reset switch | $0.29 | $1.74 | Mouser | https://www.mouser.com/ProductDetail/598-106RMR050M
C6 | 1 | 100uF 16V | C_Polarized | Polarized capacitor |  | $0.37 | $0.37 | Mouser | https://www.mouser.com/ProductDetail/647-UVZ1J101MPD
C8 | 1 | 2200uF 35V | C_Polarized | Polarized capacitor |  | $5.31 | $5.31 | Mouser | https://www.mouser.com/ProductDetail/598-228TTA063M
C9 | 1 | 10000uF 16V | C_Polarized | Polarized capacitor |  | $7.87 | $7.87 | Mouser | https://www.mouser.com/ProductDetail/598-109TTA025M
C42 | 1 | 22uF 16V | C_Polarized | Polarized capacitor |  | $0.10 | $0.10 | Mouser | https://www.mouser.com/ProductDetail/710-860010372002
C12, C13 | 2 | 470pF | C (471) | Unpolarized capacitor |  | $0.23 | $0.46 | Mouser | https://www.mouser.com/ProductDetail/594-D471K20Y5PH6UJ5R
C3, C7, C14, C15 | 4 | 0.01uF 24V | C (103) | Unpolarized capacitor |  | $0.23 | $0.92 | Mouser | https://www.mouser.com/ProductDetail/594-D103Z25Z5VF63L6R
C16, C17, C18, C19, C22, C23, C28, C29, C30, C31, C32, C33, C34, C35, C36, C37, C38, C39, C40, C41, C44, C45, C46, C47, C48, C49, C50, C51, C52, C53, C54, C55, C56, C58 | 34 | 0.1uF 25V | C (104) | Unpolarized capacitor | C58 is located to the right of ROM B C58 next to the relay stays empty (!!!) | $0.17 | $5.78 | Mouser | https://www.mouser.com/ProductDetail/594-K104K10X7RF53L2
C20 | 1 | 330pF | C (331) | Unpolarized capacitor |  | $0.30 | $0.30 | Mouser | https://www.mouser.com/ProductDetail/594-F331K29Y5RP6UK5R
C21 | 1 | 750pF | C (750) | Unpolarized capacitor |  | $0.37 | $0.37 | Mouser | https://www.mouser.com/ProductDetail/80-C322C751K3G5TA
C24, C25 | 2 | 220pF | C (221) | Unpolarized capacitor |  | $0.23 | $0.46 | Mouser | https://www.mouser.com/ProductDetail/594-D221K20Y5PF63J5R
C43 | 1 | 47pF | C (47) | Unpolarized capacitor | C43 is located to the right of Z41 | $0.40 | $0.40 | Mouser | https://www.mouser.com/ProductDetail/594-S470K25SL0N63L6R
C26 | 1 | 0.047uF | C (47nF) | Unpolarized capacitor |  | $1.90 | $1.90 | Mouser | https://www.mouser.com/ProductDetail/594-222236755473
C27 | 1 | 0.022uF | C (22nF) | Unpolarized capacitor |  | $1.34 | $1.34 | Mouser | https://www.mouser.com/ProductDetail/594-2222-366-45223
CR1 | 1 | 1N4735 | D_Zener | Zener diode |  | $0.25 | $0.25 | Mouser | https://www.mouser.com/ProductDetail/512-1N4735A
CR2 | 1 | 1N5231 | D_Zener | Zener diode |  | $0.15 | $0.15 | Mouser | https://www.mouser.com/ProductDetail/512-1N5231B
CR3, CR4, CR5, CR6, CR7 | 5 | 1N4148 | D | Diode |  | $0.10 | $0.50 | Mouser | https://www.mouser.com/ProductDetail/512-1N4148
CR9, CR10 | 2 | 1N982 | D_Schottky | Schottky diode | Replacement can be lower than 75V | $0.26 | $0.52 | Mouser | https://www.mouser.com/ProductDetail/78-1N4754A-TAP
CR8 | 1 | MDA202 | D_Bridge_+AA- | Diode bridge, +ve/AC/AC/-ve | Replacement KBP210 | $0.61 | $0.61 | Mouser | https://www.mouser.com/ProductDetail/621-KBP210G
J1, J2, J3 | 3 | Front View | DIN-5_180degree | 5-pin DIN connector (5-pin DIN-5 stereo) |  | $0.39 | $1.16 | AliExpress | https://www.aliexpress.us/item/2255801077942335.html
J100 | 1 | Connector | Conn_01x20 | Generic connector, single row, 01x20 |  | $0.50 | $0.50 | Mouser | https://www.mouser.com/ProductDetail/649-1012937992002BLF
K1 | 1 | Relay_SPST-NO | TRS80_Model_I_Relay_NO | Relay SPST, Normally Open, EN50005 | Slightly smaller than original | $14.84 | $14.84 | DigiKey | https://www.digikey.com/en/products/detail/sensata-cynergy3/S2-05P/4425813
Q1 | 1 | 2N3904 | 2N3904 | 0.2A Ic, 40V Vce, Small Signal NPN Transistor, TO-92 |  | $0.35 | $0.35 | Mouser | https://www.mouser.com/ProductDetail/512-2N3904BU
Q2, Q5 | 2 | 2N3906 | 2N3906 | -0.2A Ic, -40V Vce, Small Signal PNP Transistor, TO-92 |  | $0.28 | $0.56 | Mouser | https://www.mouser.com/ProductDetail/512-2N3906BU
Q3 | 1 | TIP29A | Q_NPN_BCE | NPN transistor, base/collector/emitter |  | $1.01 | $1.01 | Mouser | https://www.mouser.com/ProductDetail/863-TIP29AG
Q4 | 1 | 2N6594 | Q_PNP_BEC | PNP transistor, base/emitter/collector | Replacement RS2040, MJ2955G | $4.75 | $4.75 | Mouser | https://www.mouser.com/ProductDetail/863-MJ2955G
Q6 | 1 | MJE34 | Q_PNP_BCE | PNP transistor, base/collector/emitter | Replacement TIP32C | $0.67 | $0.67 | Mouser | https://www.mouser.com/ProductDetail/511-TIP32C
- | 1 |  |  | Q4 Heatsink |  | $1.01 | $1.01 | Mouser | https://www.mouser.com/ProductDetail/532-506007B00
- | 1 |  |  | Q6 Heatsink | Smaller than original | $0.30 | $0.30 | Mouser | https://www.mouser.com/ProductDetail/532-507302B00
R1 | 1 | 68 |  | Resistor 0.25W (blue, grey, black, gold) |  | $0.10 | $0.10 | Mouser | https://www.mouser.com/ProductDetail/603-CFR-25JB-52-68R
R2 | 1 | 2.7k |  | Resistor 0.25W (red, violet, red, gold) |  | $0.10 | $0.10 | Mouser | https://www.mouser.com/ProductDetail/603-CFR-25JR-522K7
R3 | 1 | 750 |  | Resistor 0.25W (violet, green, brown, gold) |  | $0.10 | $0.10 | Mouser | https://www.mouser.com/ProductDetail/603-CFR-25JB-52-750R
R4 | 1 | 0.33 |  | Resistor 2W (orange, orange, silver, gold) |  | $0.45 | $0.45 | Mouser | https://www.mouser.com/ProductDetail/603-CFR2WSJT-73-0R33
R6, R7, R16, R53 | 4 | 1.2k |  | Resistor 0.25W (brown, red, red, gold) |  | $0.10 | $0.40 | Mouser | https://www.mouser.com/ProductDetail/603-CFR-25JB-52-1K2
R8 | 1 | 100k |  | Resistor 0.25W (brown, black, yellow, gold) |  | $0.10 | $0.10 | Mouser | https://www.mouser.com/ProductDetail/603-CFR-25JB-52-100K
R9, R11, R12 | 3 | 3.3k |  | Resistor 0.25W (orange, orange, red, gold) |  | $0.10 | $0.30 | Mouser | https://www.mouser.com/ProductDetail/603-CFR-25JB-52-3K3
R13 | 1 | 2.2k |  | Resistor 0.25W (red, red, red, gold) |  | $0.10 | $0.10 | Mouser | https://www.mouser.com/ProductDetail/603-CFR-25JT-52-2K2
R14 | 1 | 12k |  | Resistor 0.25W (brown, red, orange, gold) |  | $0.10 | $0.10 | Mouser | https://www.mouser.com/ProductDetail/603-CFR-25JB-52-12K
R15 | 1 | 1.5k |  | Resistor 0.25W (brown, green, red, gold) |  | $0.10 | $0.10 | Mouser | https://www.mouser.com/ProductDetail/603-CFR-25JT-52-1K5
R17 | 1 | 2k |  | Resistor 0.25W (red, black, red, gold) |  | $0.10 | $0.10 | Mouser | https://www.mouser.com/ProductDetail/603-CFR-25JB-52-2K
R18 | 1 | 5.6 |  | Resistor 3W (green, blue, gold, gold) |  | $0.57 | $0.57 | Mouser | https://www.mouser.com/ProductDetail/279-EP3WSS5R6J
R19, C_R67 | 2 | 220 |  | Resistor 0.5W (red, red, brown, gold) | C_R67 is located to the left of K1 | $0.10 | $0.20 | Mouser | https://www.mouser.com/ProductDetail/603-CFR-50JB-52-220R
R22 | 1 | 75 |  | Resistor 0.25W (violet, green, black, gold) |  | $0.10 | $0.10 | Mouser | https://www.mouser.com/ProductDetail/603-CFR-25JB-52-75R
R23 | 1 | 120 |  | Resistor 0.25W (brown, red, brown, gold) |  | $0.10 | $0.10 | Mouser | https://www.mouser.com/ProductDetail/603-CFR-25JB-52-120R
R24 | 1 | 680k |  | Resistor 0.25W (blue, grey, yellow, gold) |  | $0.10 | $0.10 | Mouser | https://www.mouser.com/ProductDetail/603-CFR-25JB-52-680K
R25 | 1 | 1.6M |  | Resistor 0.25W (brown, blue, green, gold) |  | $0.10 | $0.10 | Mouser | https://www.mouser.com/ProductDetail/603-CFR-25JB-52-1M6
R26, R42 | 2 | 1M |  | Resistor 0.25W (brown, black, green, gold) |  | $0.10 | $0.20 | Mouser | https://www.mouser.com/ProductDetail/603-CFR-25JT-52-1M
R27, R64 | 2 | 330 |  | Resistor 0.25W (orange, orange, brown, gold) |  | $0.10 | $0.20 | Mouser | https://www.mouser.com/ProductDetail/603-CFR-25JB-52-330R
R28 | 1 | 270 |  | Resistor 0.25W (red, violet, brown, gold) |  | $0.10 | $0.10 | Mouser | https://www.mouser.com/ProductDetail/603-CFR-25JB-52-270R
R29 | 1 | 1.8k |  | Resistor 0.25W (brown, grey, red, gold) |  | $0.10 | $0.10 | Mouser | https://www.mouser.com/ProductDetail/603-CFR-25JB-52-1K8
R30 | 1 | 47 |  | Resistor 0.25W (yellow, violet, black, gold) |  | $0.10 | $0.10 | Mouser | https://www.mouser.com/ProductDetail/603-CFR-25JB-52-47R
R31 | 1 | 10 |  | Resistor 0.25W (brown, black, black, gold) |  | $0.10 | $0.10 | Mouser | https://www.mouser.com/ProductDetail/603-CFR-25JT-52-10R
R32, R43, R44, R47, R65 | 5 | 10k |  | Resistor 0.25W (brown, black, orange, gold) | R44 is located in the bottom left corner R65 is located at the reset switch | $0.10 | $0.50 | Mouser | https://www.mouser.com/ProductDetail/603-CFR-25JB-52-10K
R33, R36 | 2 | 360k |  | Resistor 0.25W (orange, blue, yellow, gold) |  | $0.10 | $0.20 | Mouser | https://www.mouser.com/ProductDetail/603-CFR-25JB-52-360K
R34, R35, R38, R41, R45 | 5 | 470k |  | Resistor 0.25W (yellow, violet, yellow, gold) |  | $0.10 | $0.50 | Mouser | https://www.mouser.com/ProductDetail/603-CFR-25JB-52-470K
R37 | 1 | 560k |  | Resistor 0.25W (green, blue, yellow, gold) |  | $0.10 | $0.10 | Mouser | https://www.mouser.com/ProductDetail/603-CFR-25JB-52-560K
R39, R40, R48, R49, R50, R51, R57, R58, R59, R60, R61, R62, R63, R66, R67, R68, R69 | 17 | 4.7k |  | Resistor 0.25W (yellow, violet, red, gold) | R67 is located to the left of Z42 | $0.10 | $1.70 | Mouser | https://www.mouser.com/ProductDetail/603-CFR-25JB-52-4K7
R46, R52 | 2 | 910 |  | Resistor 0.25W (white, brown, brown, gold) |  | $0.10 | $0.20 | Mouser | https://www.mouser.com/ProductDetail/603-CFR-25JB-52-910R
R54, R55 | 2 | 7.5k |  | Resistor 0.25W (violet, blue, red, gold) |  | $0.10 | $0.20 | Mouser | https://www.mouser.com/ProductDetail/603-CFR-25JB-52-7K5
R56 | 1 | 220k |  | Resistor 0.25W (red, red, yellow, gold) |  | $0.10 | $0.10 | Mouser | https://www.mouser.com/ProductDetail/603-CFR-25JB-52-220K
R5, R10 | 2 | 1k | R_Potentiometer | Potentiometer |  | $0.57 | $1.14 | Mouser | https://www.mouser.com/ProductDetail/531-PT10H-1K-S
R20, R21 | 2 | 100k | R_Potentiometer | Potentiometer |  | $0.57 | $1.14 | Mouser | https://www.mouser.com/ProductDetail/531-PT10H-100K-S
S1 | 1 | Power | SW_4PST |  |  | $4.34 | $4.34 | DigiKey | https://www.digikey.com/en/products/detail/c-k/F4UEE/417520
S2 | 1 | Reset | SW_DPST |  |  | $1.82 | $1.82 | AliExpress | https://www.aliexpress.us/item/3256804467086494.html
Y1 | 1 | 10.6445 MHz | Crystal | Two pin crystal | 10.6MHz replacement | $0.73 | $0.73 | Mouser | https://www.mouser.com/ProductDetail/449-LFXTAL028537BULK
Z1, Z2 | 2 | LM723C | LM723C_1 | Linear Regulator (adjustable) |  | $1.04 | $2.08 | Mouser | https://www.mouser.com/ProductDetail/595-UA723CN
Z3, Z71 | 2 | Jumper | TRS80ModelIX71 | 8-Bit DIP Switch | Replacement | $2.07 | $4.14 | Mouser | https://www.mouser.com/ProductDetail/710-418117270908
Z4 | 1 | LM3900 | LM3900 | Quad operational amplifier |  | $0.60 | $0.60 | Mouser | https://www.mouser.com/ProductDetail/595-LM3900NE4
Z5 | 1 | 74C00 | 74LS00 | quad 2-input NAND gate |  | $0.62 | $0.62 | Mouser | https://www.mouser.com/ProductDetail/595-CD74HC00E
Z6, Z57 | 2 | 74C04 | 74LS04 | Hex Inverter |  | $0.47 | $0.94 | Mouser | https://www.mouser.com/ProductDetail/595-SN74HC04AN
Z7, Z69, Z70 | 3 | 74LS74 | 74LS74 | Dual D Flip-flop, Set & Reset |  | $0.49 | $1.47 | Mouser | https://www.mouser.com/ProductDetail/595-SN74LS74AN
Z8 | 1 | 74LS153 | 74LS153 | Dual Multiplexer 4 to 1 |  | $1.13 | $1.13 | Mouser | https://www.mouser.com/ProductDetail/595-SN74LS153N
Z9, Z42, Z52 | 3 | 74LS04 | 74LS04 | Hex Inverter |  | $0.67 | $2.01 | Mouser | https://www.mouser.com/ProductDetail/595-SN74LS04N
Z10, Z11 | 2 | 74LS166 | 74LS166 | Shift Register 8-bit, parallel load |  | $1.24 | $2.48 | Mouser | https://www.mouser.com/ProductDetail/595-SN74LS166AN
Z12, Z32, Z50, Z65 | 4 | 74LS93 | 74LS93 | Divide by 2 & 8 counter |  | $3.04 | $12.16 | Mouser | https://www.mouser.com/ProductDetail/595-SN74LS93N
Z13, Z14, Z15, Z16, Z17, Z18, Z19, Z20 | 8 | MK4116 | 4116 | 16kBit x 1 Bit Dynamic RAM |  | $3.95 | $31.60 | Jameco | https://www.jameco.com/z/4116-15-Major-Brands-IC-4116-15-DRAM-16-384-Bit-16Kx1-150ns-5V_41339.html
Z21 | 1 | 74LS156 | 74LS156 | Dual 2 to 4 lines Decoder/Demultiplexer, Open Collector |  | $0.75 | $0.75 | Mouser | https://www.mouser.com/ProductDetail/595-SN74LS156N
Z22, Z38, Z39, Z44, Z55, Z60, Z67, Z68, Z72, Z75, Z76 | 11 | 74LS367 | 74LS367_Split | Hex buffer 3-State outputs |  | $1.44 | $15.84 | Mouser | https://www.mouser.com/ProductDetail/595-SN74LS367AN
Z23, Z25, Z36, Z73 | 4 | 74LS32 | 74LS32 | Quad 2-input OR |  | $0.56 | $2.24 | Mouser | https://www.mouser.com/ProductDetail/595-SN74LS32N
Z24, Z53 | 2 | 74LS132 | 74LS132 | Quad 2-input NAND Schmitt trigger |  | $1.03 | $2.06 | Mouser | https://www.mouser.com/ProductDetail/595-SN74LS132N
Z26 | 1 | 74LS20 | 74LS20 | Dual 4-input NAND |  | $1.28 | $1.28 | Mouser | https://www.mouser.com/ProductDetail/595-SN74LS20N
Z27, Z59 | 2 | 74LS175 | 74LS175 | 4-bit D Flip-Flop, reset |  | $1.02 | $2.04 | Mouser | https://www.mouser.com/ProductDetail/595-SN74LS175N
Z28 | 1 | 74LS174 | 74LS174 | Hex D-type Flip-Flop, reset |  | $1.12 | $1.12 | Mouser | https://www.mouser.com/ProductDetail/595-SN74LS174N
Z29 | 1 | MCM6670 | MCM6670P | 128 x 7 x 5 Character Generator | Adapter needed |  |  | GitHub | https://github.com/RetroStack/MCM776x_CharGen_Adapter
Z30, Z37 | 2 | 74LS02 | 74LS02 | quad 2-input NOR gate |  | $0.55 | $1.10 | Mouser | https://www.mouser.com/ProductDetail/595-SN74LS02N
Z31, Z35, Z43, Z49, Z51, Z64 | 6 | 74LS157 | 74LS157 | Quad 2 to 1 line Multiplexer |  | $0.88 | $5.28 | Mouser | https://www.mouser.com/ProductDetail/595-SN74LS157N
Z33 | 1 | 2364_20L | 2364_20L | 2364 64kBit (8kb x 8) PROM | Adapter needed |  |  | - | -
Z34 | 1 | 2332_20L_21L | 2332_20L_21L | 2332 32kBit (4kb x 8) PROM | Adapter needed |  |  | - | -
Z40 | 1 | Z80CPU | Z80 | Z80 CPU |  | $9.62 | $9.62 | Mouser | https://www.mouser.com/ProductDetail/692-Z84C0010PEG
Z41 | 1 | 75452 | 75452 | Dual-Peripheral Drivers for High-Current, High-Speed Switching |  | $0.90 | $0.90 | Mouser | https://www.mouser.com/ProductDetail/595-SN75452BP
Z45, Z46, Z47, Z48, Z61, Z62, Z63 | 7 | 2102 | 2102_1 | 1K Static RAM (SRAM) | Add another one for lower-case mod | $2.95 | $20.65 | Jameco | https://www.jameco.com/z/MM2102AN-4-National-Semiconductor-IC-MM2102AN-4-NMOS-SRAM-1024-Bit-1024x1-250ns-DIP-16_2287991.html
Z54 | 1 | 74LS30 | 74LS30 | 8-input NAND |  | $1.18 | $1.18 | Mouser | https://www.mouser.com/ProductDetail/595-SN74LS30N
Z56, Z58 | 2 | 74LS92 | 74LS92 | Divide by 12 counter |  | $3.27 | $6.54 | Mouser | https://www.mouser.com/ProductDetail/595-SN74LS92N
Z66 | 1 | 74LS11 | 74LS11 | Triple 3-input AND |  | $0.91 | $0.91 | Mouser | https://www.mouser.com/ProductDetail/595-SN74LS11N
Z74 | 1 | 74LS00 | 74LS00 | quad 2-input NAND gate |  | $0.57 | $0.57 | Mouser | https://www.mouser.com/ProductDetail/595-SN74LS00N
Machined DIP Socket 8 pin | 1 | DIP-8 | DIP-8 | DIP-8 Socket | Optional | $0.49 | $0.49 | Jameco | https://www.jameco.com/z/6100-8-R-Jameco-ValuePro-IC-Socket-8-Pin-Machine-Tooled-Low-Profile-0-3-Inch-Wide_51626.html
Machined DIP Socket 14 pin | 30 | DIP-14 | DIP-14 | DIP-14 Socket | Optional | $0.75 | $22.50 | Jameco | https://www.jameco.com/z/14MTLP-Jameco-ValuePro-Socket-IC-14-Pin-Machine-Tooled-Low-Profile-0-3-Inch-Wide_37197.html
Machined DIP Socket 16 pin | 39 | DIP-16 | DIP-16 | DIP-16 Socket | Optional | $0.85 | $33.15 | Jameco | https://www.jameco.com/z/16MTLP-Jameco-ValuePro-Socket-IC-16-Pin-Machine-Tooled-Low-Profile-0-3-Inch-Wide_37402.html
Machined DIP Socket 18 pin | 1 | DIP-18 | DIP-18 | DIP-18 Socket | Optional | $0.99 | $0.99 | Jameco | https://www.jameco.com/z/18MTLP-Jameco-ValuePro-18-Pin-Machine-Tooled-Low-Profile-IC-Socket-0-3-Inch-Wide_65585.html
Machined DIP Socket 24 pin | 2 | DIP-24 | DIP-24 | DIP-24 Socket | Optional | $1.49 | $2.98 | Jameco | https://www.jameco.com/z/24MTLP-6-Jameco-ValuePro-24-Pin-Machine-Tooled-Low-Profile-IC-Socket-0-6-Inch-Wide_39351.html
Machined DIP Socket 40 pin | 1 | DIP-40 | DIP-40 | DIP-40 Socket | Optional | $1.69 | $1.69 | Jameco | https://www.jameco.com/z/40MTLP-Jameco-ValuePro-40-Pin-Machine-Tooled-Low-Profile-IC-Socket-0-6-Inch-Wide_41136.html

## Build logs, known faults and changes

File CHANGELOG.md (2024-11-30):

# TRS-80 Model 1 (Rev G) Replica - E1 - Changelog

## Versioning

I've devised a versioning system for my replica projects. This system provides clarity about each of my version's significance. My version identifier consistently follows the original revision details, allowing for a clear distinction between the original manufacturer's revision and my own.

Here's the format for the versioning:

- The initial character is always an "E," representing my last name. This choice ensures that others can adopt the same versioning style if needed.
- The following character is a number, with "1" signifying a 1-1 re-implementation of the original. Numbers beyond "1" denote various board variations, such as new designs features, more modern components, or different interface ports.
- The final character represents my actual revision of that board. Using a character for this purpose distinguishes it from the re-implementation type mentioned above, and it allows for up to 26 revisions to refine the project.

## 12th Dec 2023 - E1A Prototype

Completed test. Fully functional.

## 28th Dec 2023 - E1B

- A few traces were modified to more closely resemble the original.

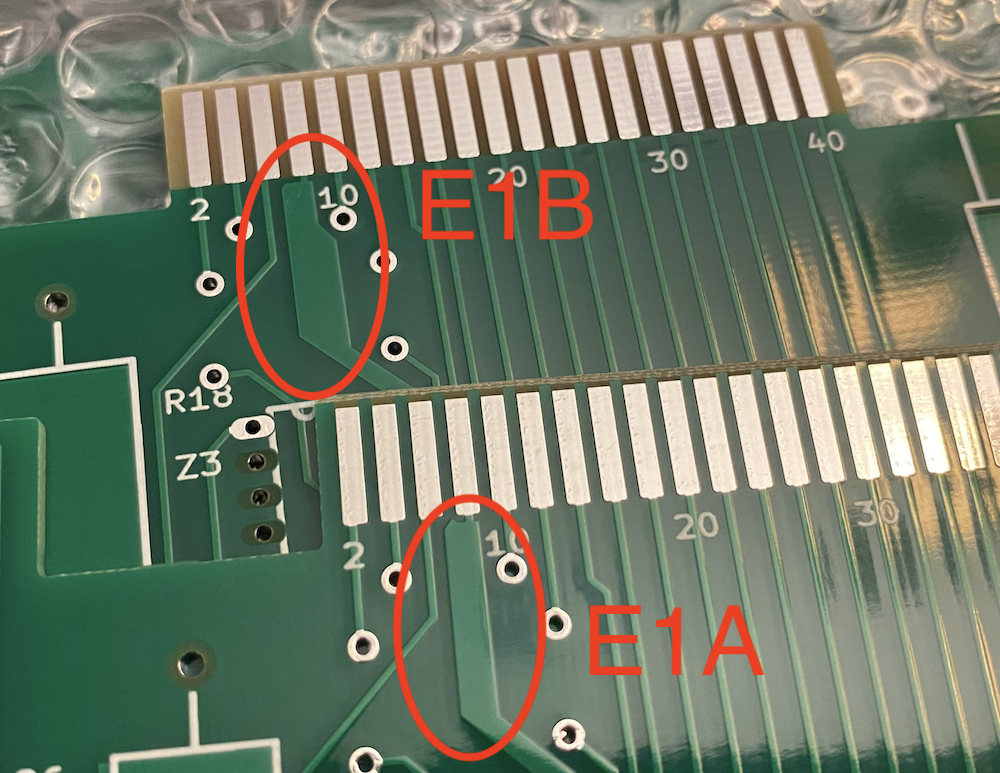
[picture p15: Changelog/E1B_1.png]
Optimized trace shape at edge-connector

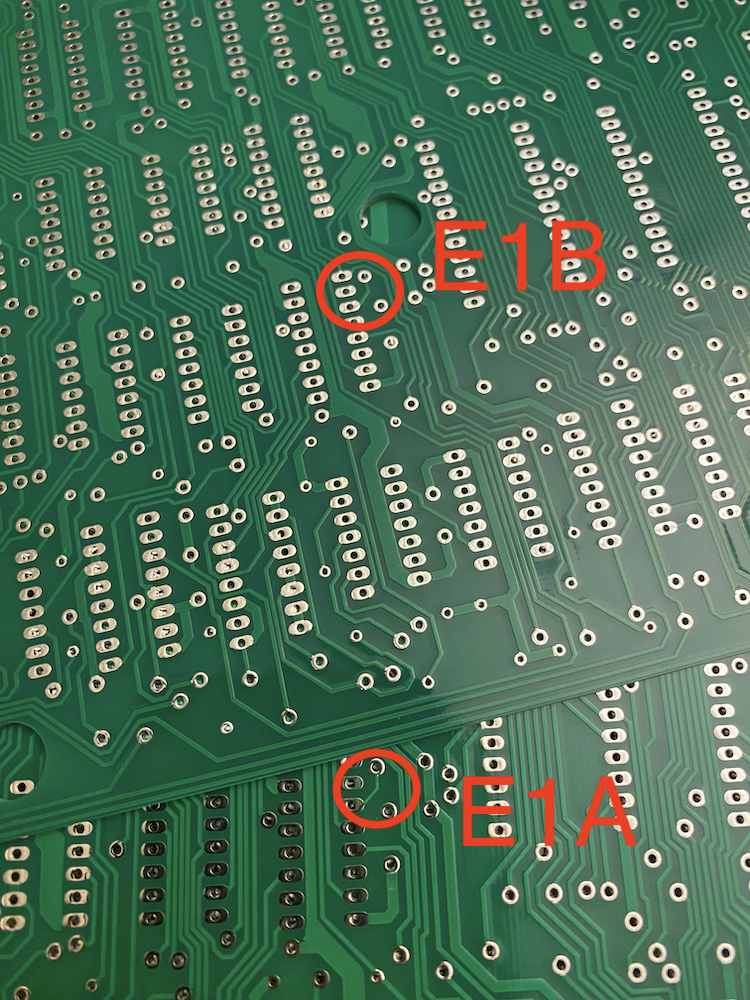
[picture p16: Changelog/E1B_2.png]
Increase trace size frm 0.3mm to 0.5mm


- Missing pads from the bottom of the PCB, also found on the original, were put-back to simplify the soldering of components.

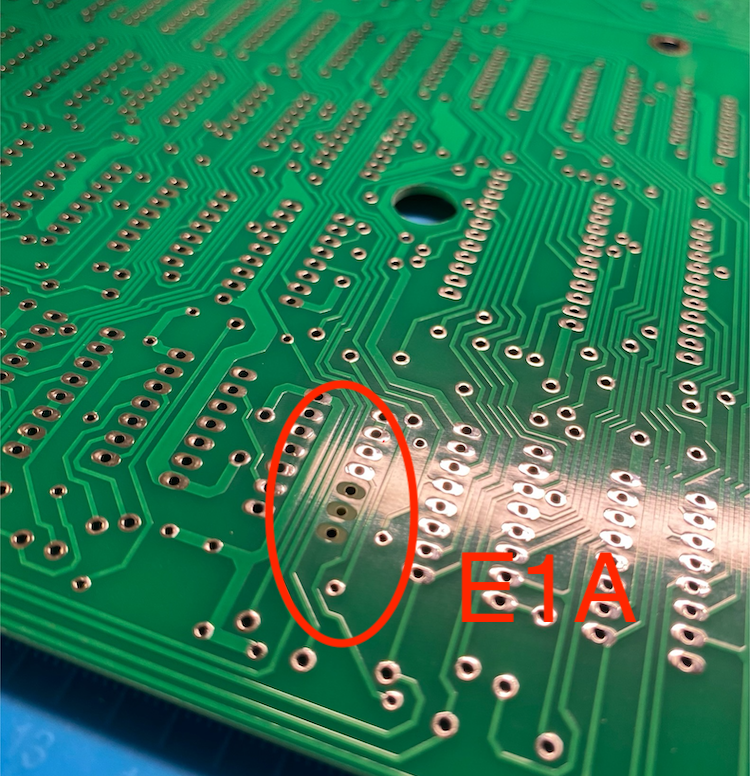
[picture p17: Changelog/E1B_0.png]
Missing pads on bottom of E1A


- The holes for several through-hole components (diodes) were enlarged. Previously, these holes were a bit tight.

## 20th Feb 2024 - E1B (no version change; only local files)

- New file "Labels" in SVG format was added to help identify components.
- Various updates to the BOM by Jay Newirth.

## 3rd March 2024 - E1B (no version change; only local files)

- Assembly Guide as PDF (suggested by Jay Newirth)

## 14th March 2024 - E1B (no version change; only local files)

- Updated BOM to remove 2N6287 as alternative. Has worked, but transistor introduces a lot of noise in 5V rail, causing a shaky video output.

## 30th March 2024 - E1B (no version change; only local files)

- Updated BOM to add MJ2955G as alternative for Q4, including source of Mouser.

## 30th November 2024 - E1C

- Updating one trace from 0.25mm to 0.5mm as original
- Aligned both ROM sockets (were slightly misaligned)
- Added grounding to front pins on DIN-5 connectors; missed it on first iteration
- Disconnected copper field from Q6 collector; I thought the original was connected, but it is unconnected
- Changed RetroStack note; "Replicated by" instead of "Created by"

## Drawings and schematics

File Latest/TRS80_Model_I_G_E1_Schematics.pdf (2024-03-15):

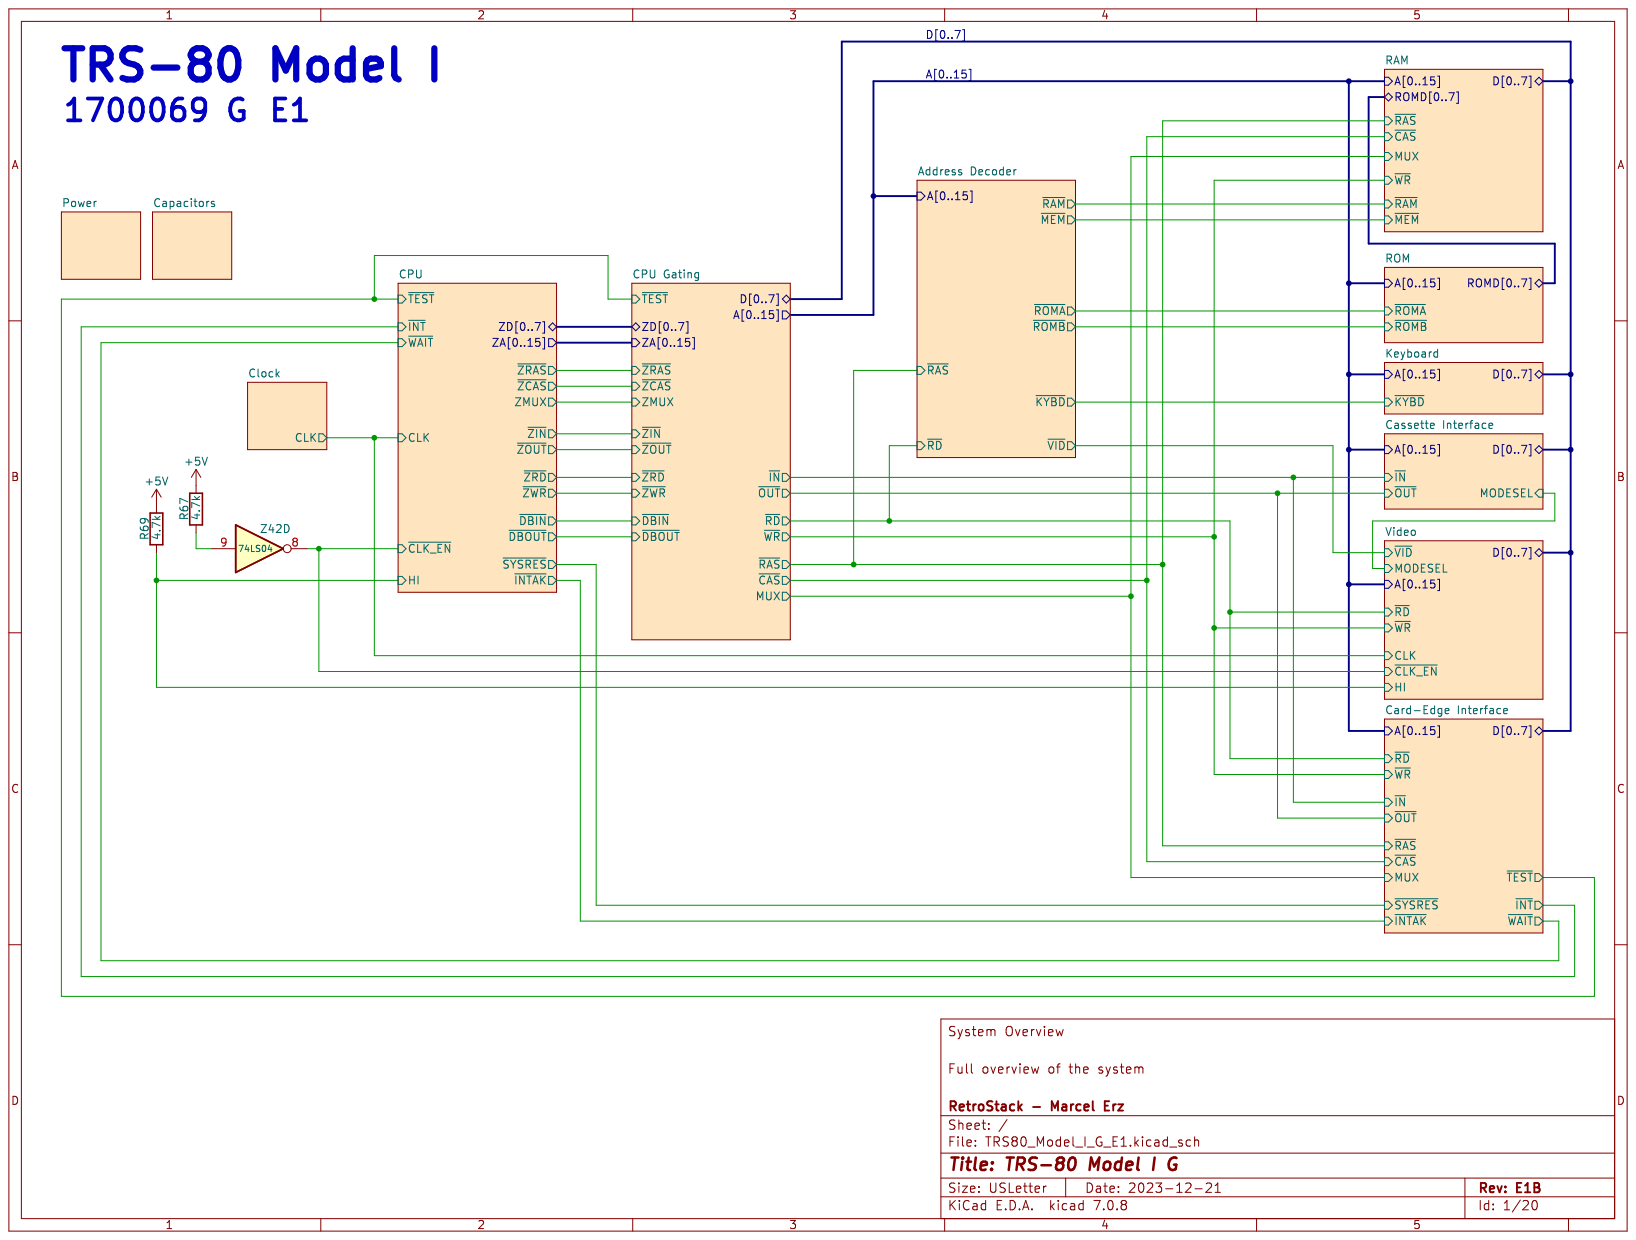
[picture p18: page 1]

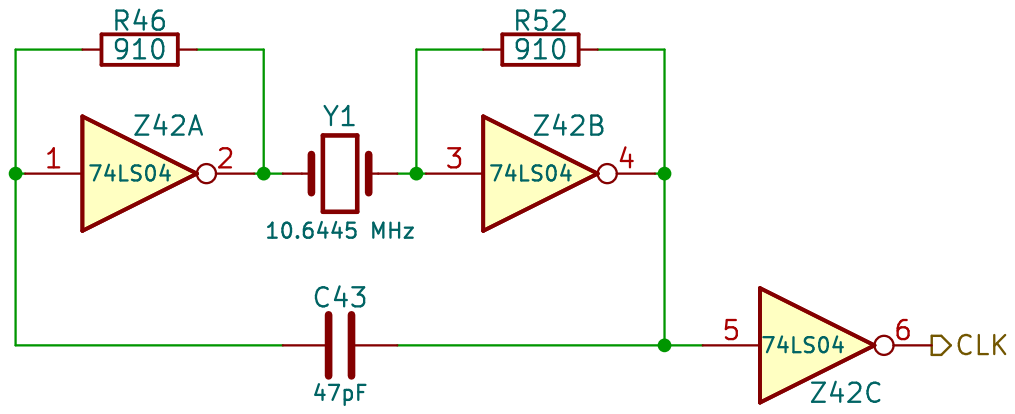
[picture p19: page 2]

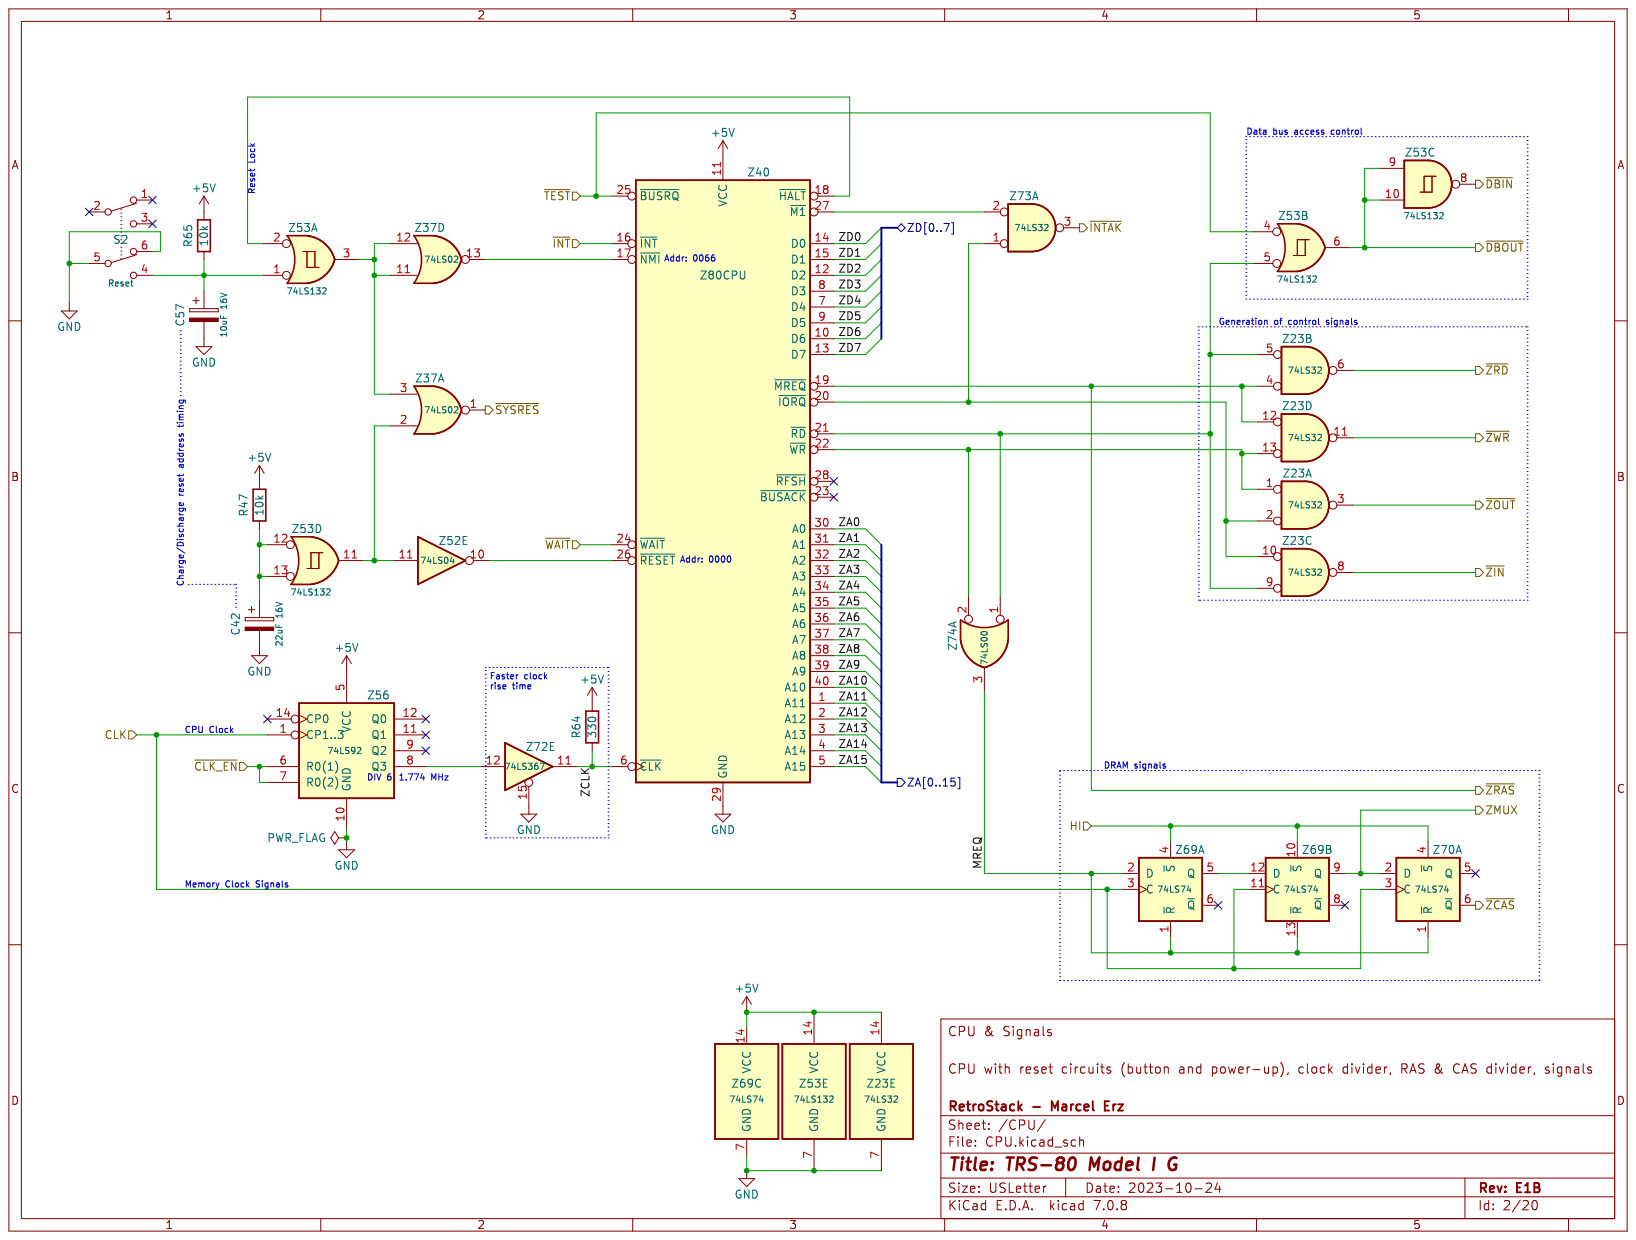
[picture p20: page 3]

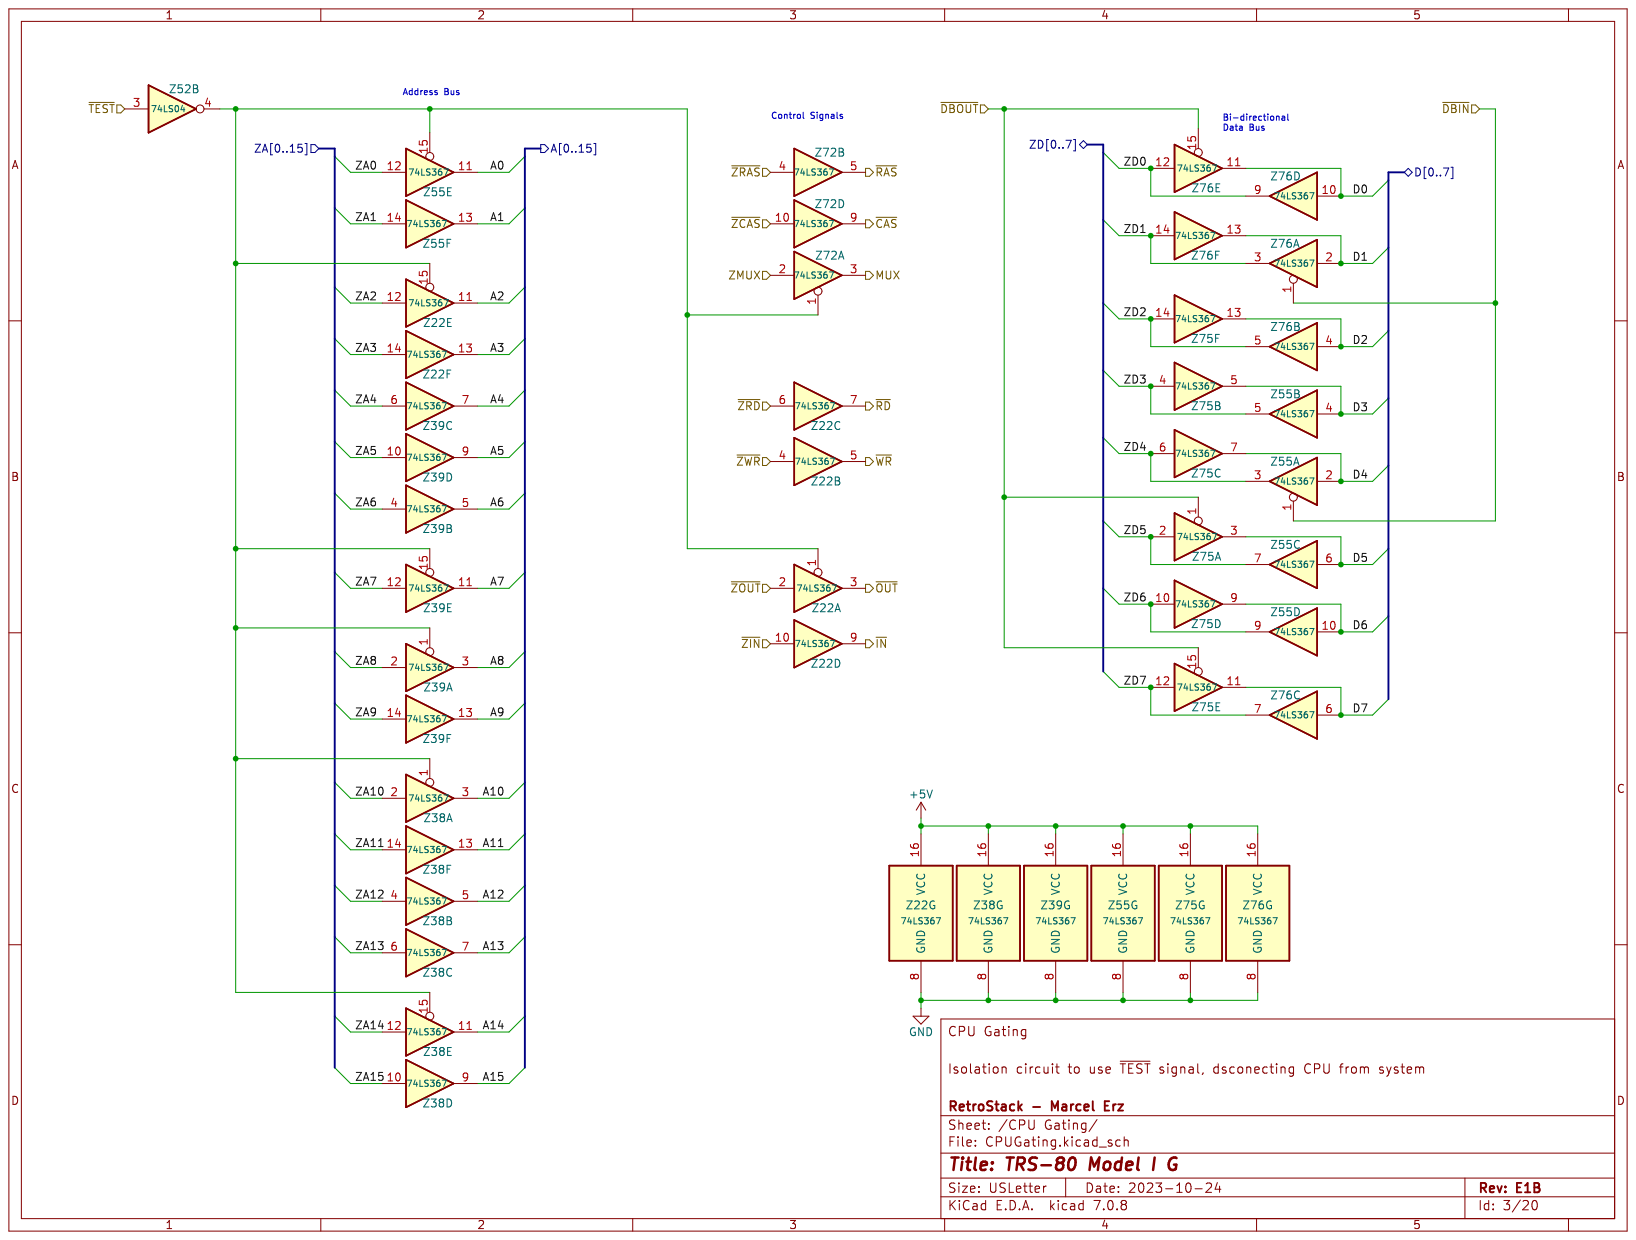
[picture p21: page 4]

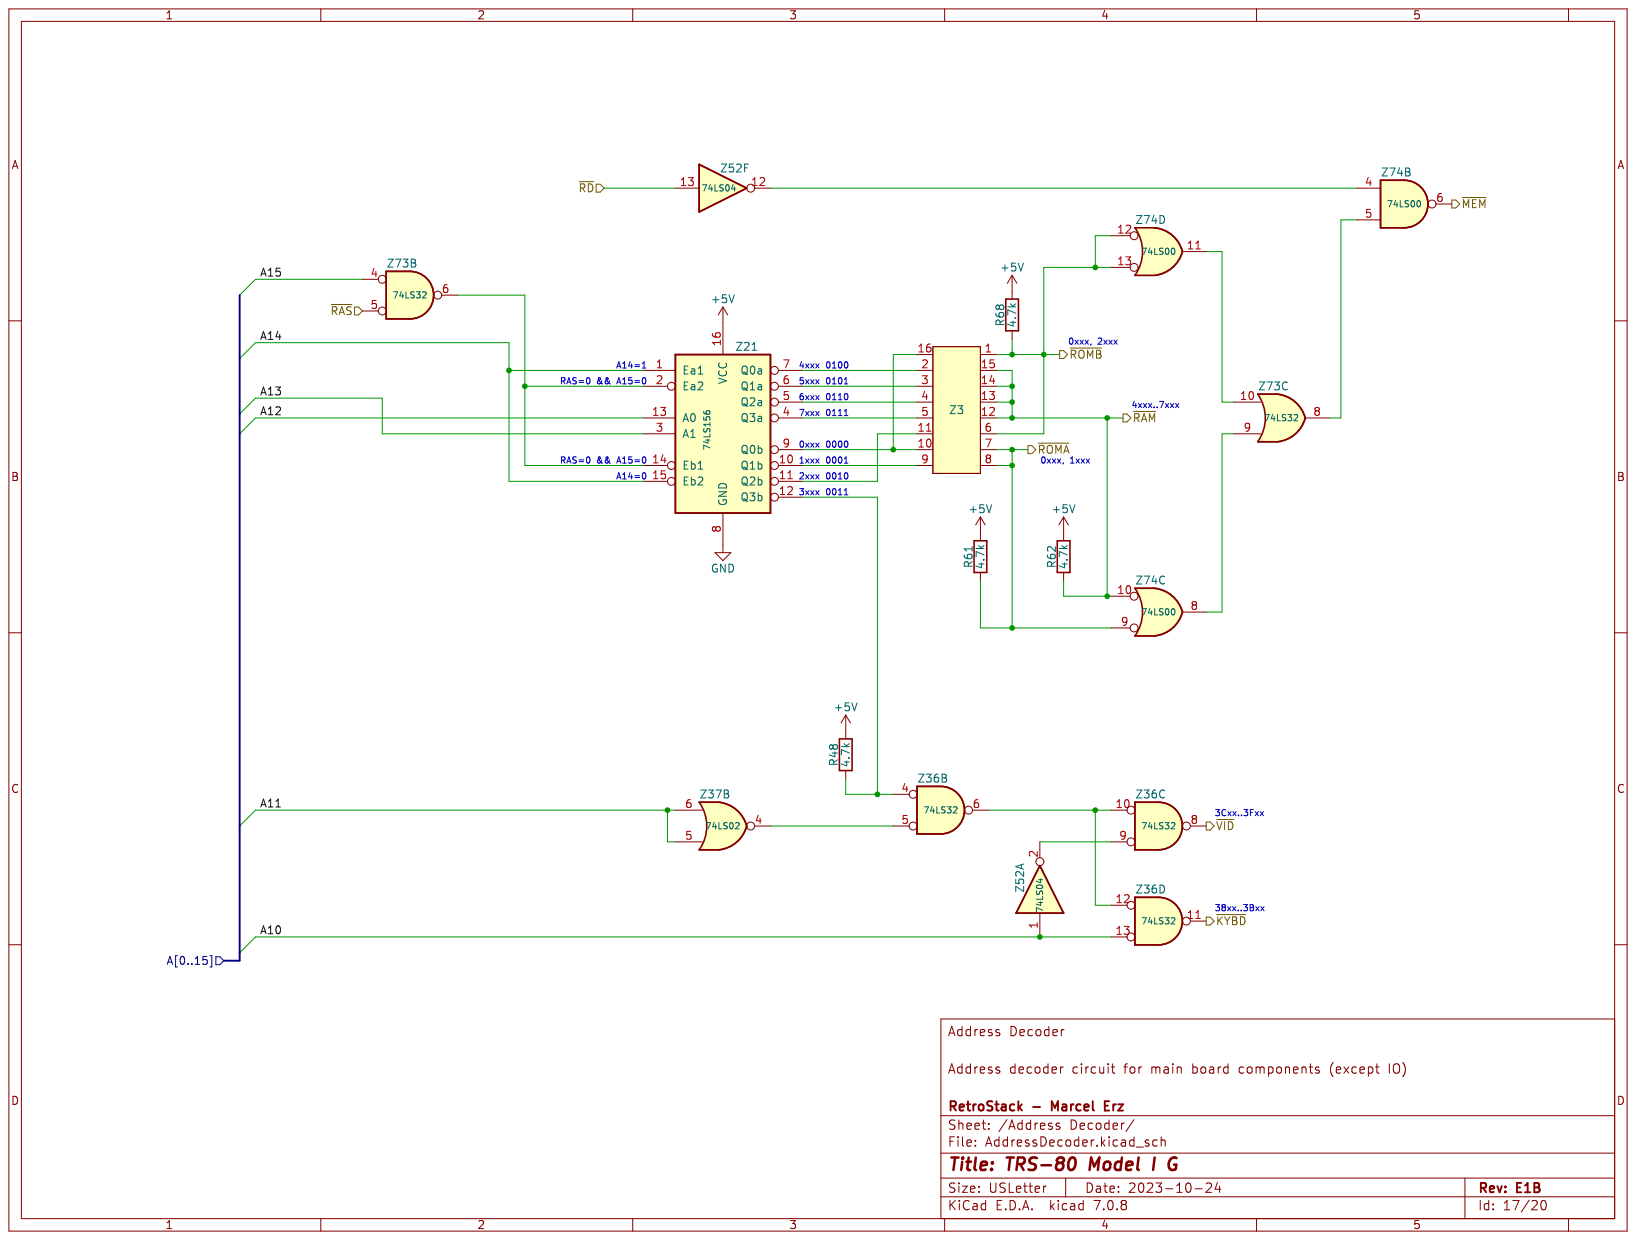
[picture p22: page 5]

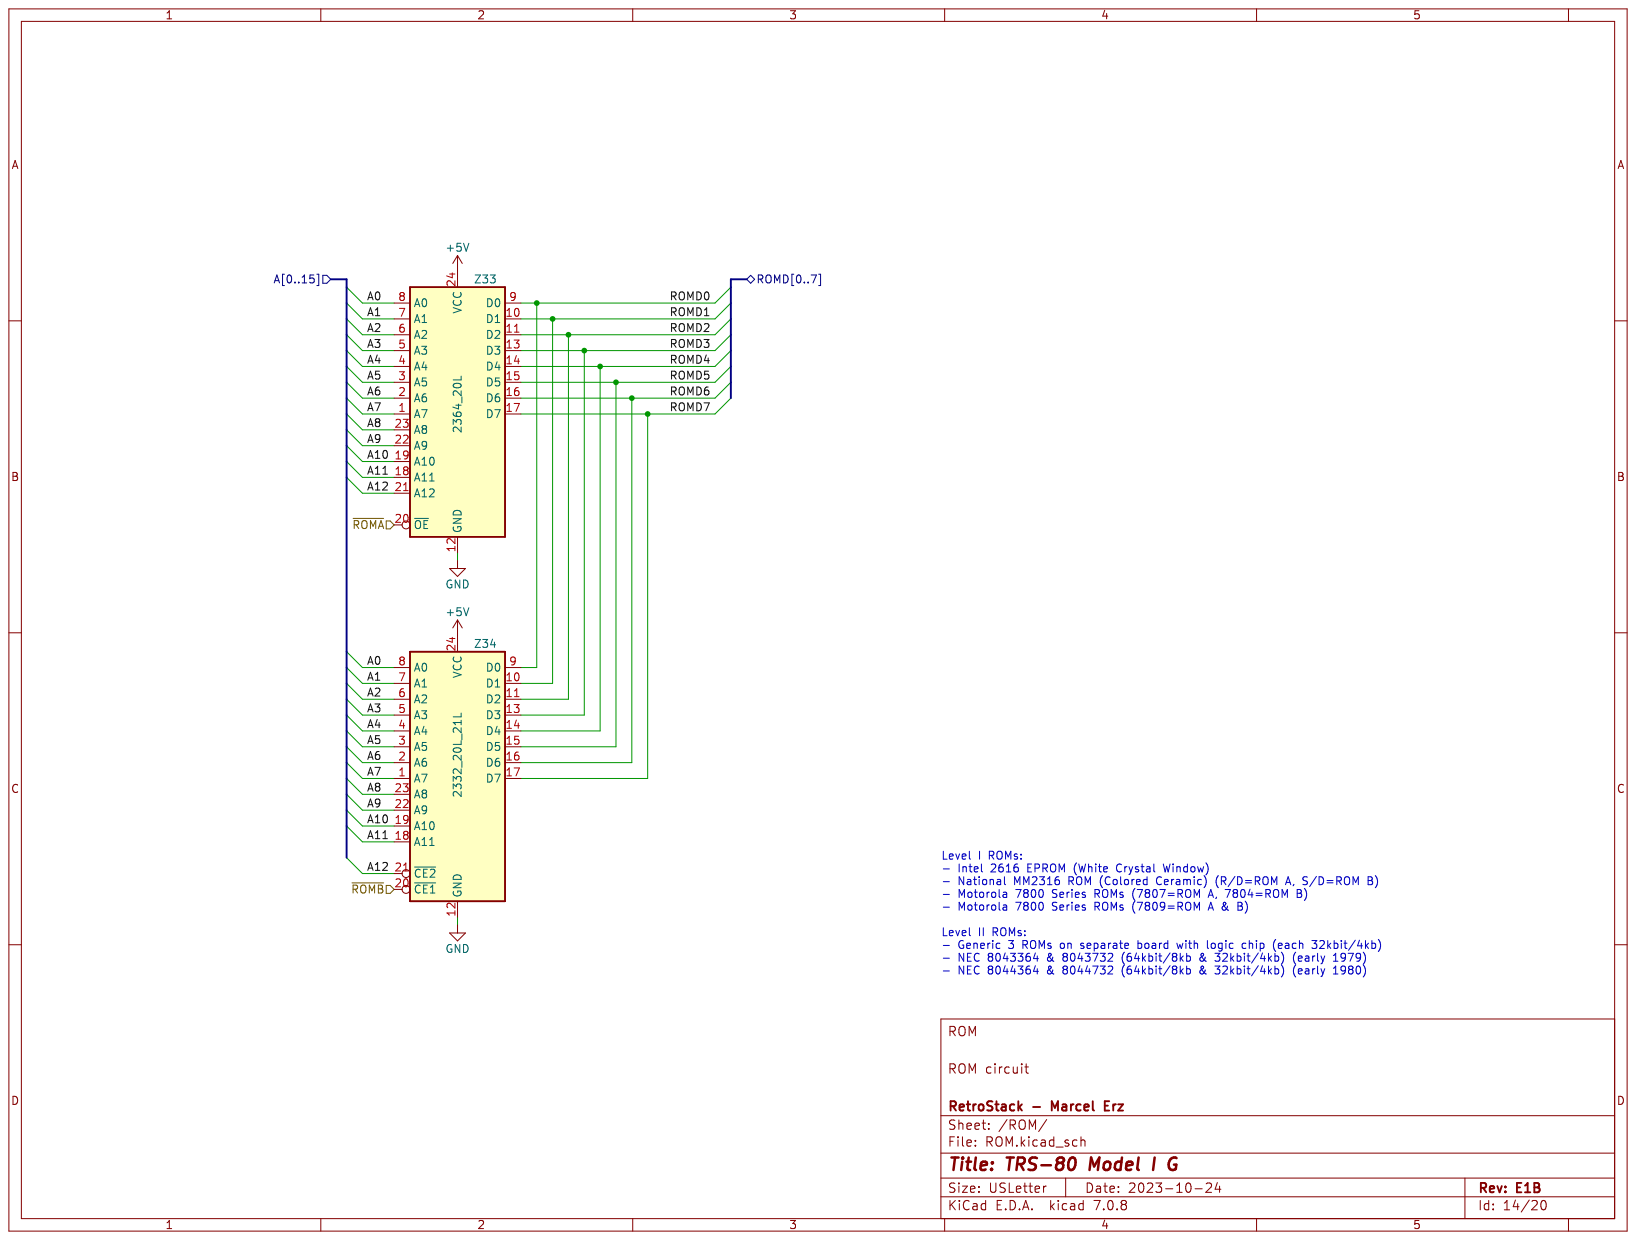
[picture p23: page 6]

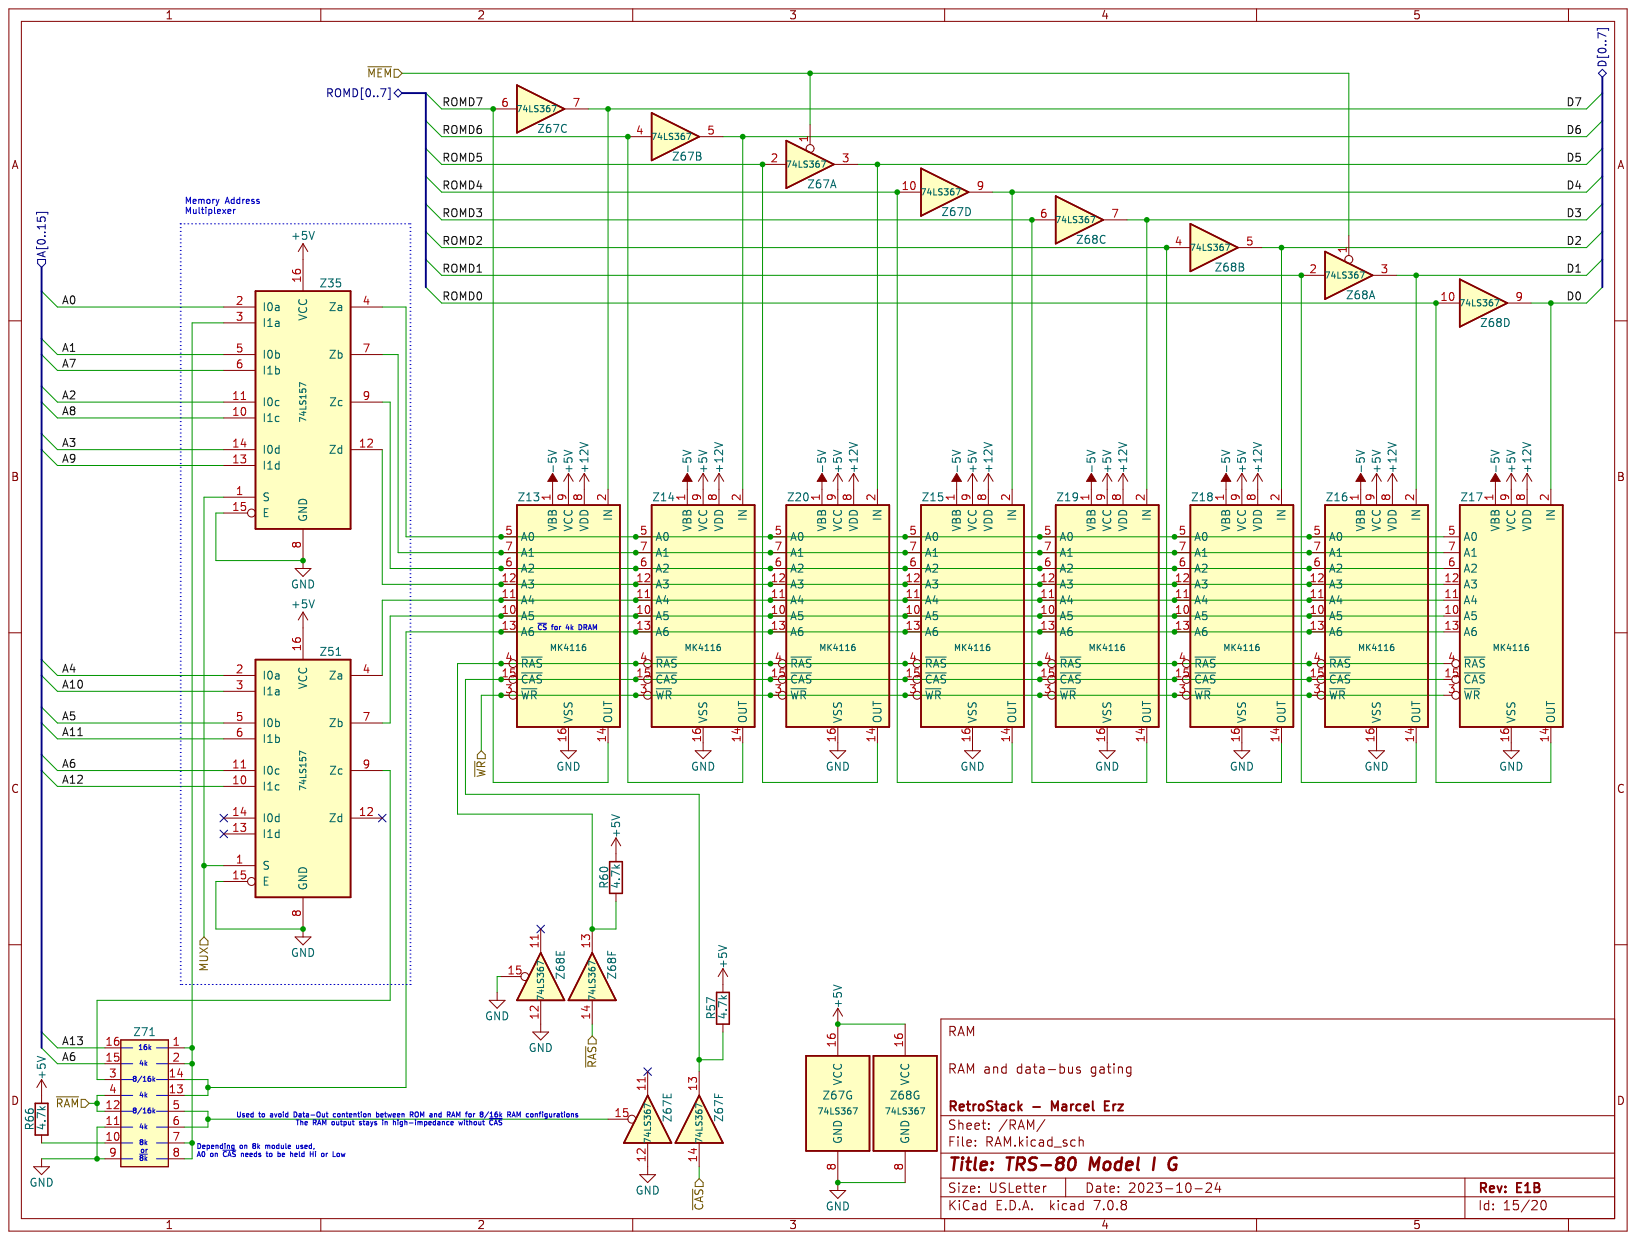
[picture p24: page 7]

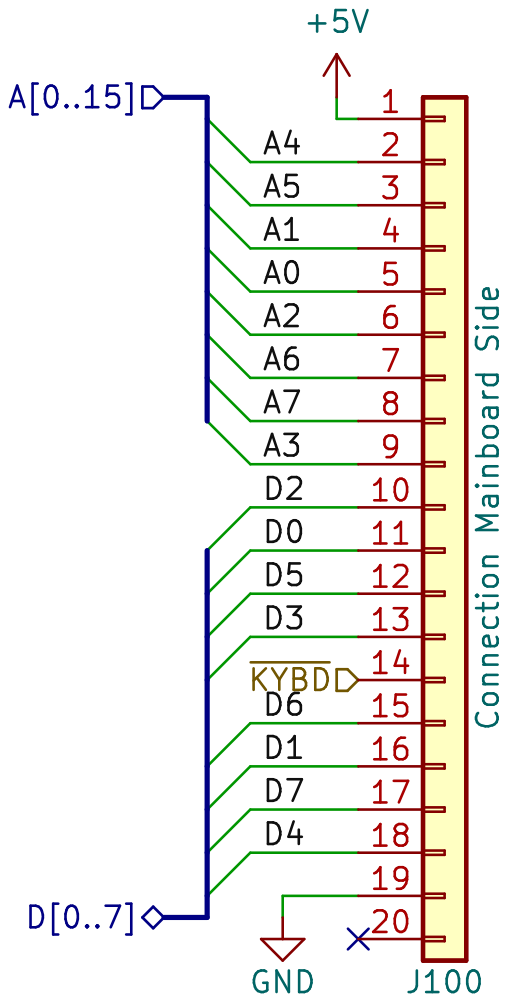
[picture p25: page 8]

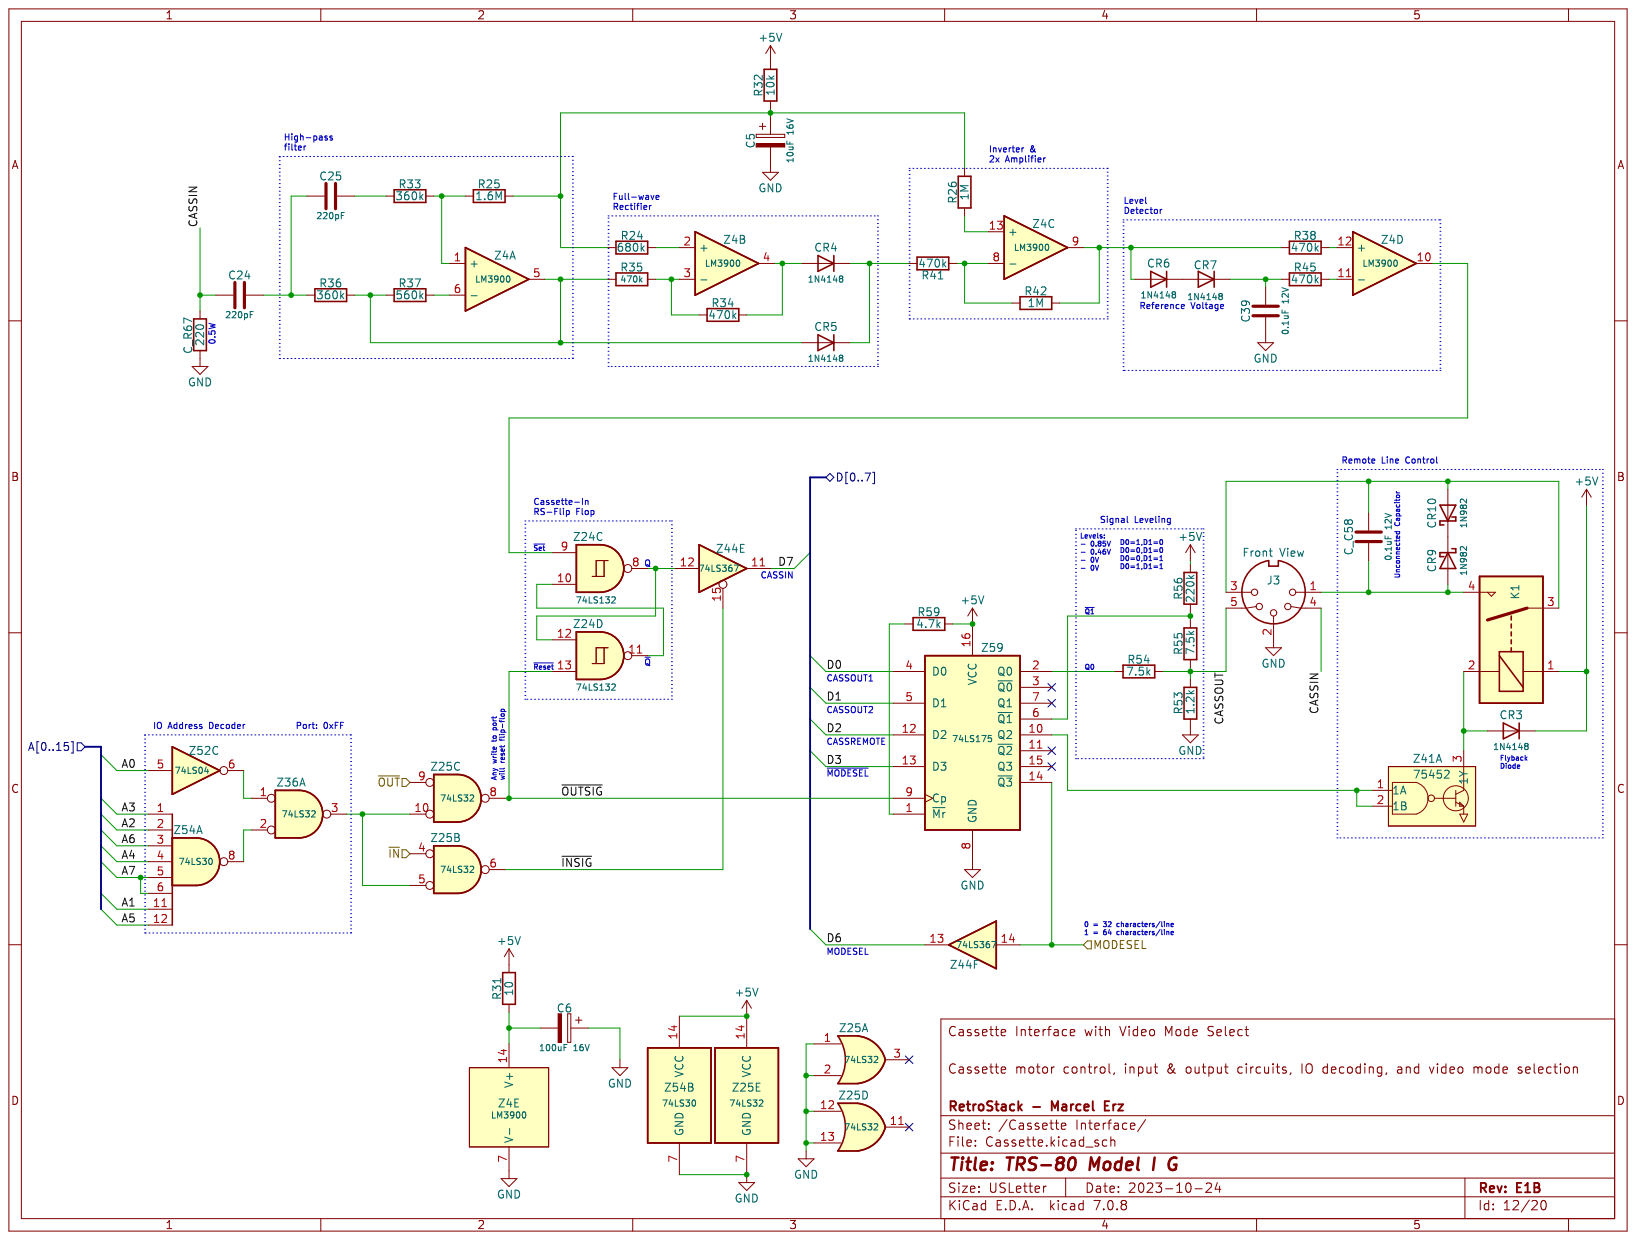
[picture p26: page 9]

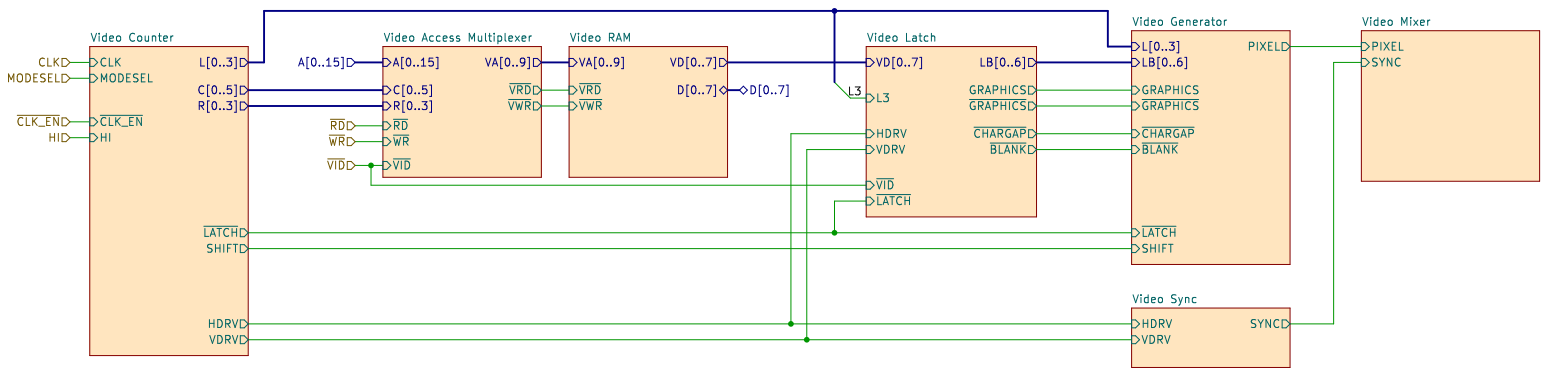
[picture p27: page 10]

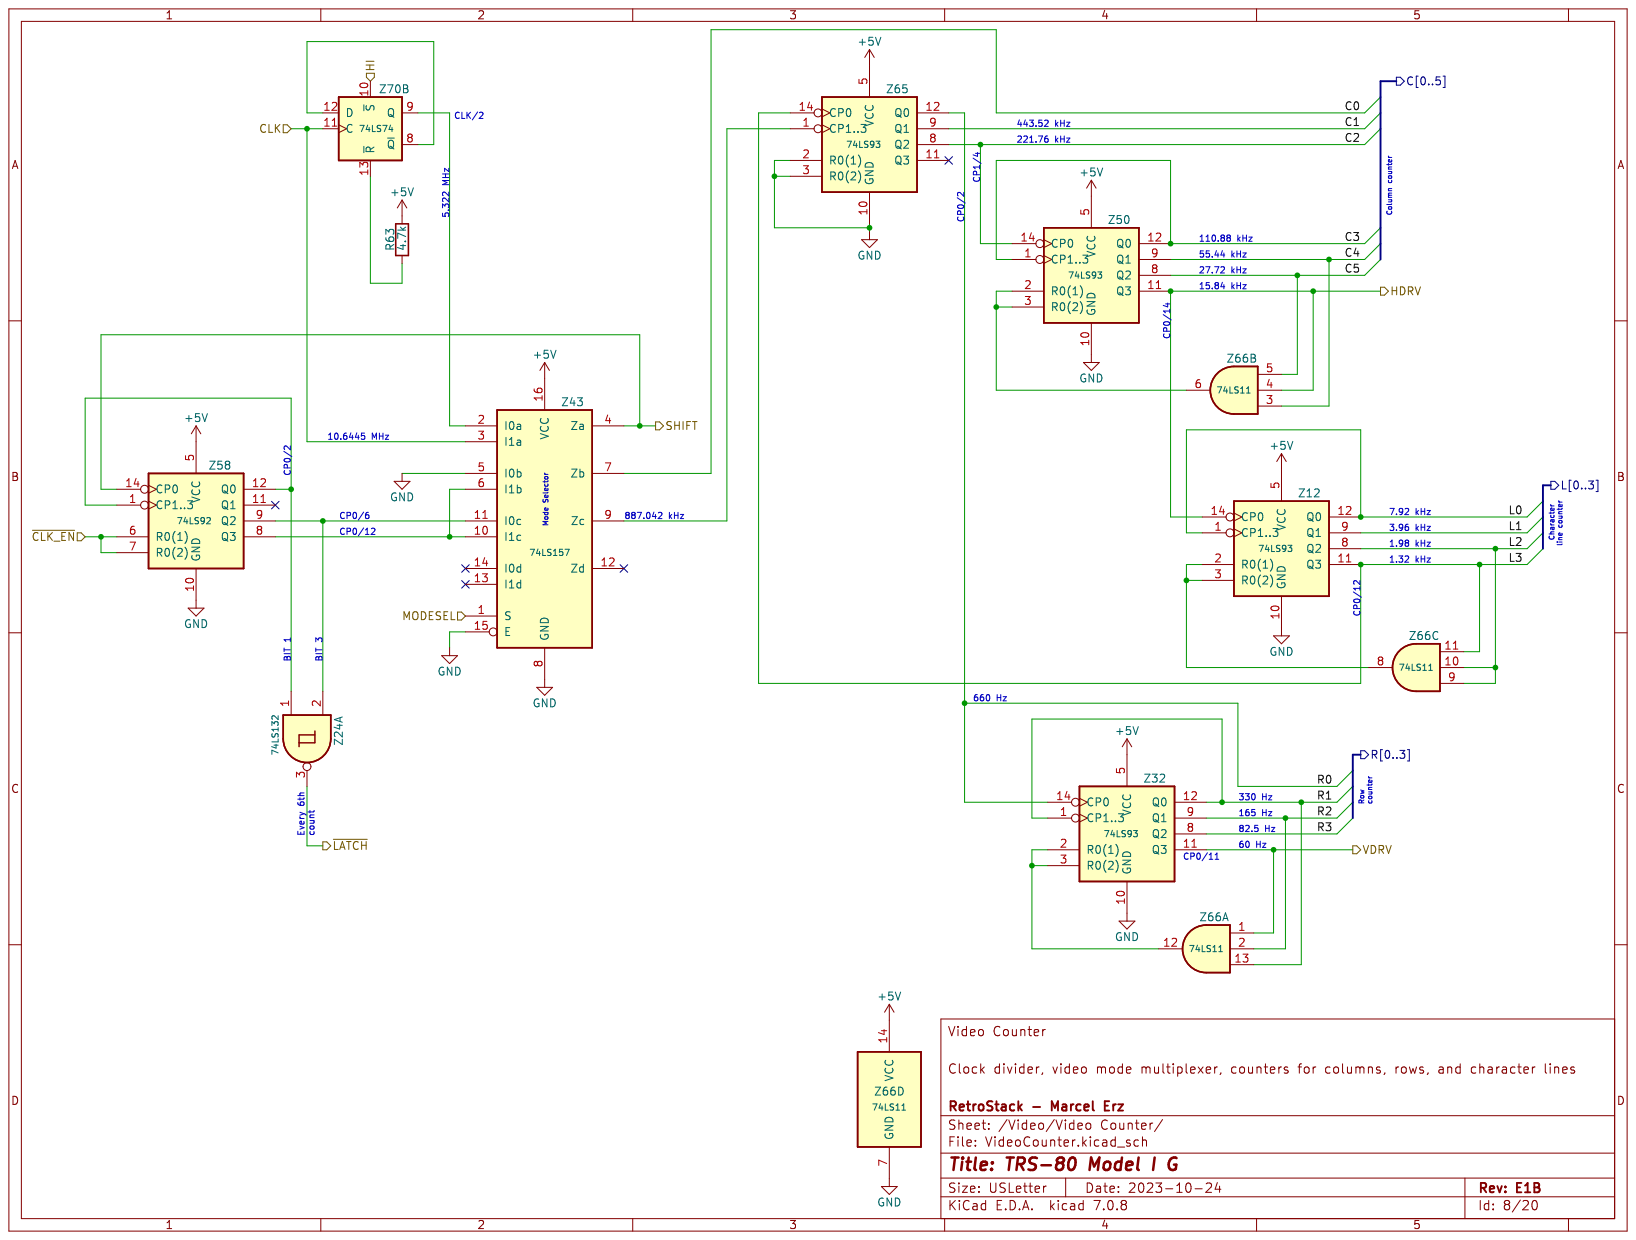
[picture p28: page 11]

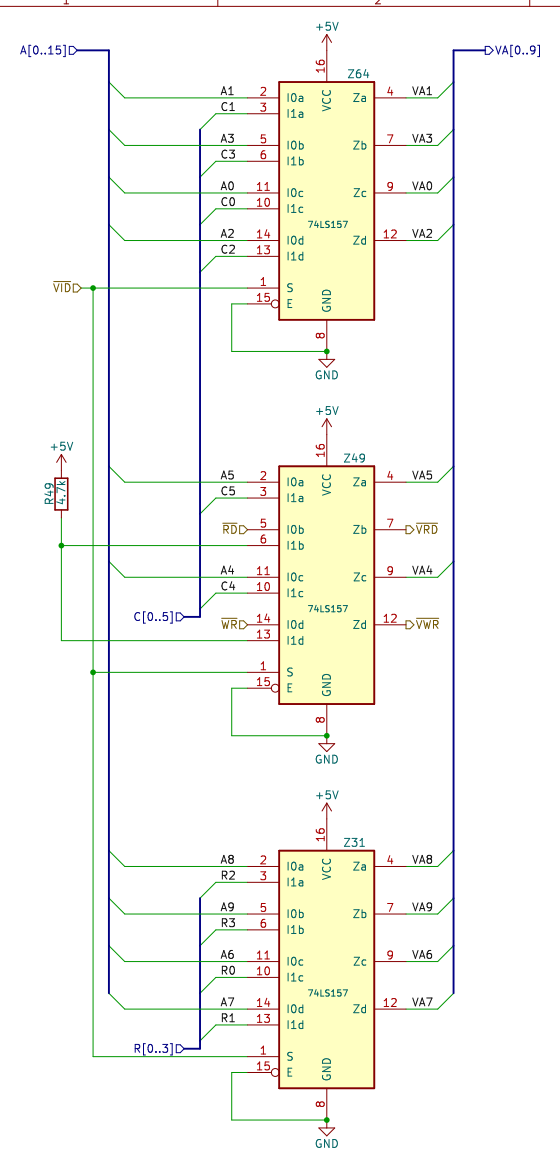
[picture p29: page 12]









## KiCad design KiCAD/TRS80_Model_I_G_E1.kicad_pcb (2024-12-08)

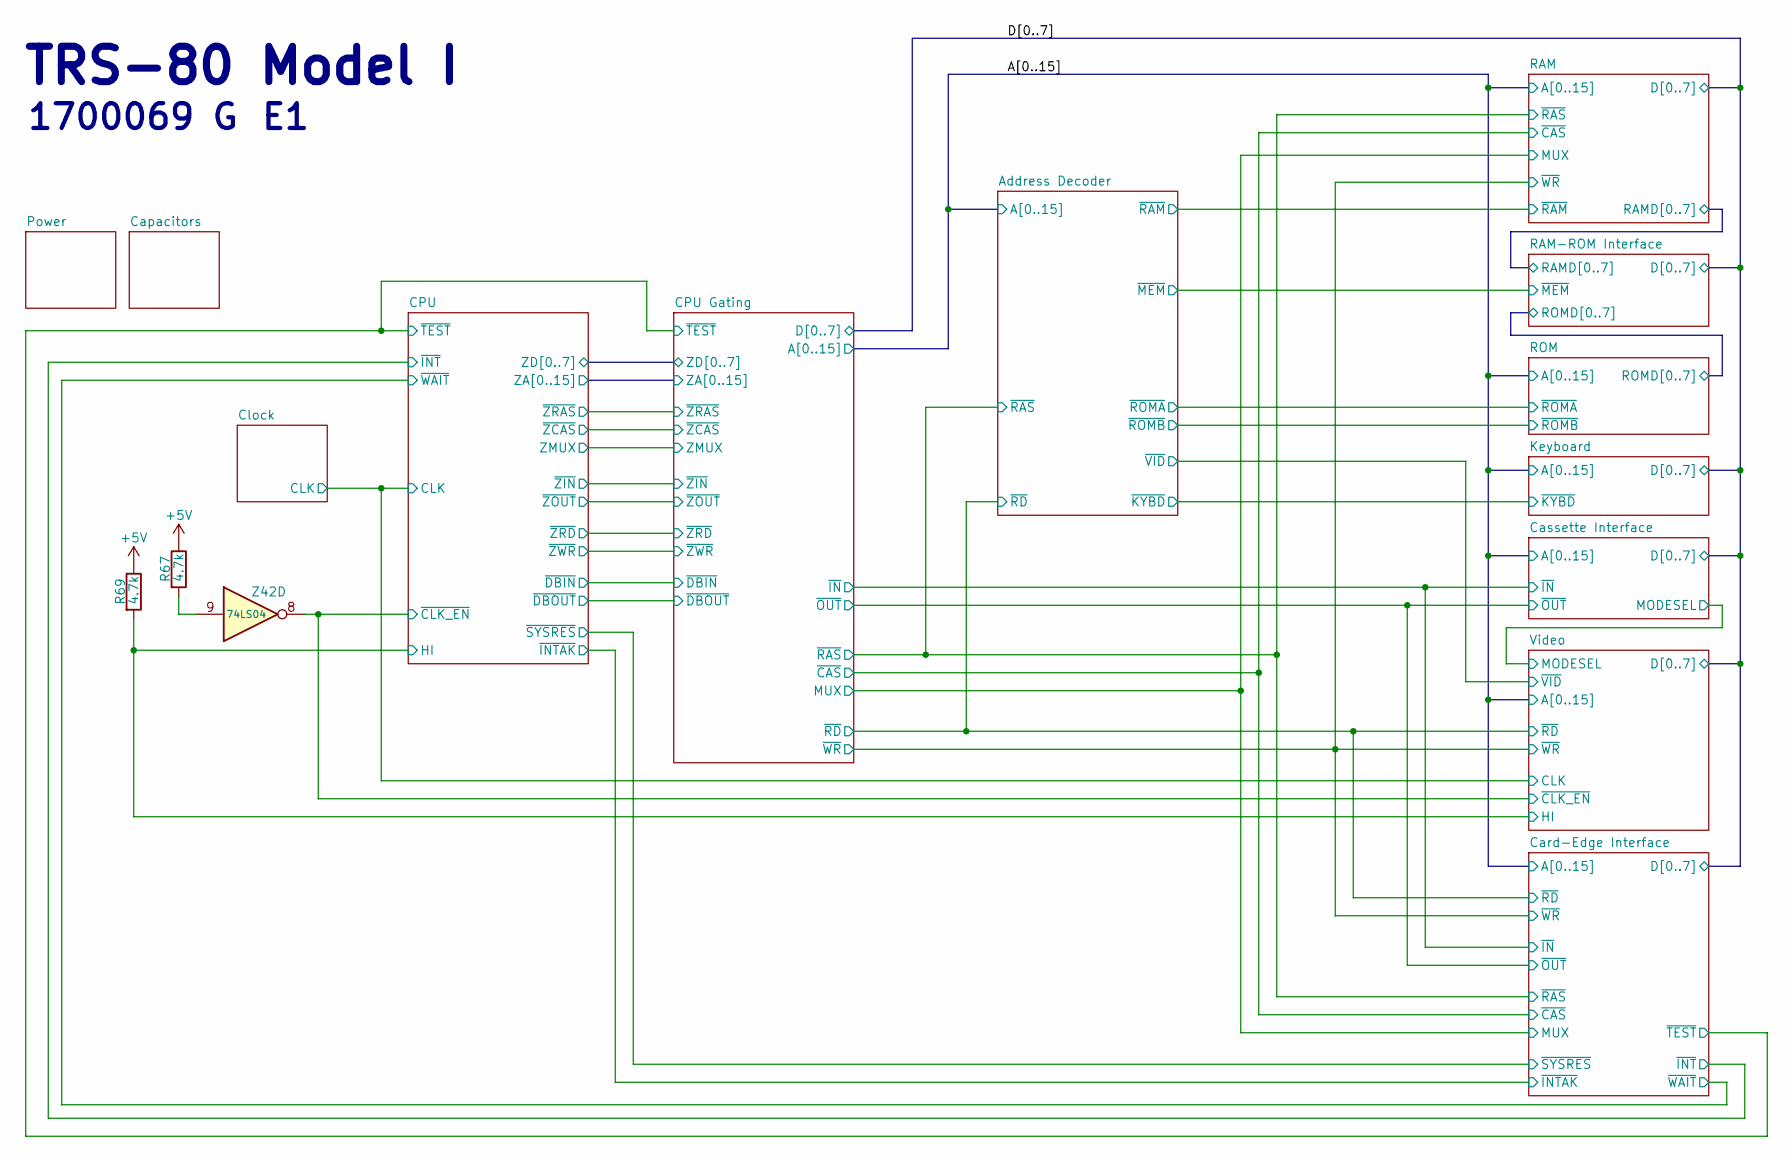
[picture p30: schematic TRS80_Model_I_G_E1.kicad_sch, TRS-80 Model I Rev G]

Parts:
R67, R69: 4.7k; TRS80_Model_I_R_0.25W
Z42: 74LS04; TRS80_Model_I_DIP14

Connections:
+5V: R67.1, R69.1; also elsewhere on the board
/CPU/HI: R69.2; also elsewhere on the board
unnamed: R67.2, Z42.9

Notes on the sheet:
TRS-80 Model I
1700069 G

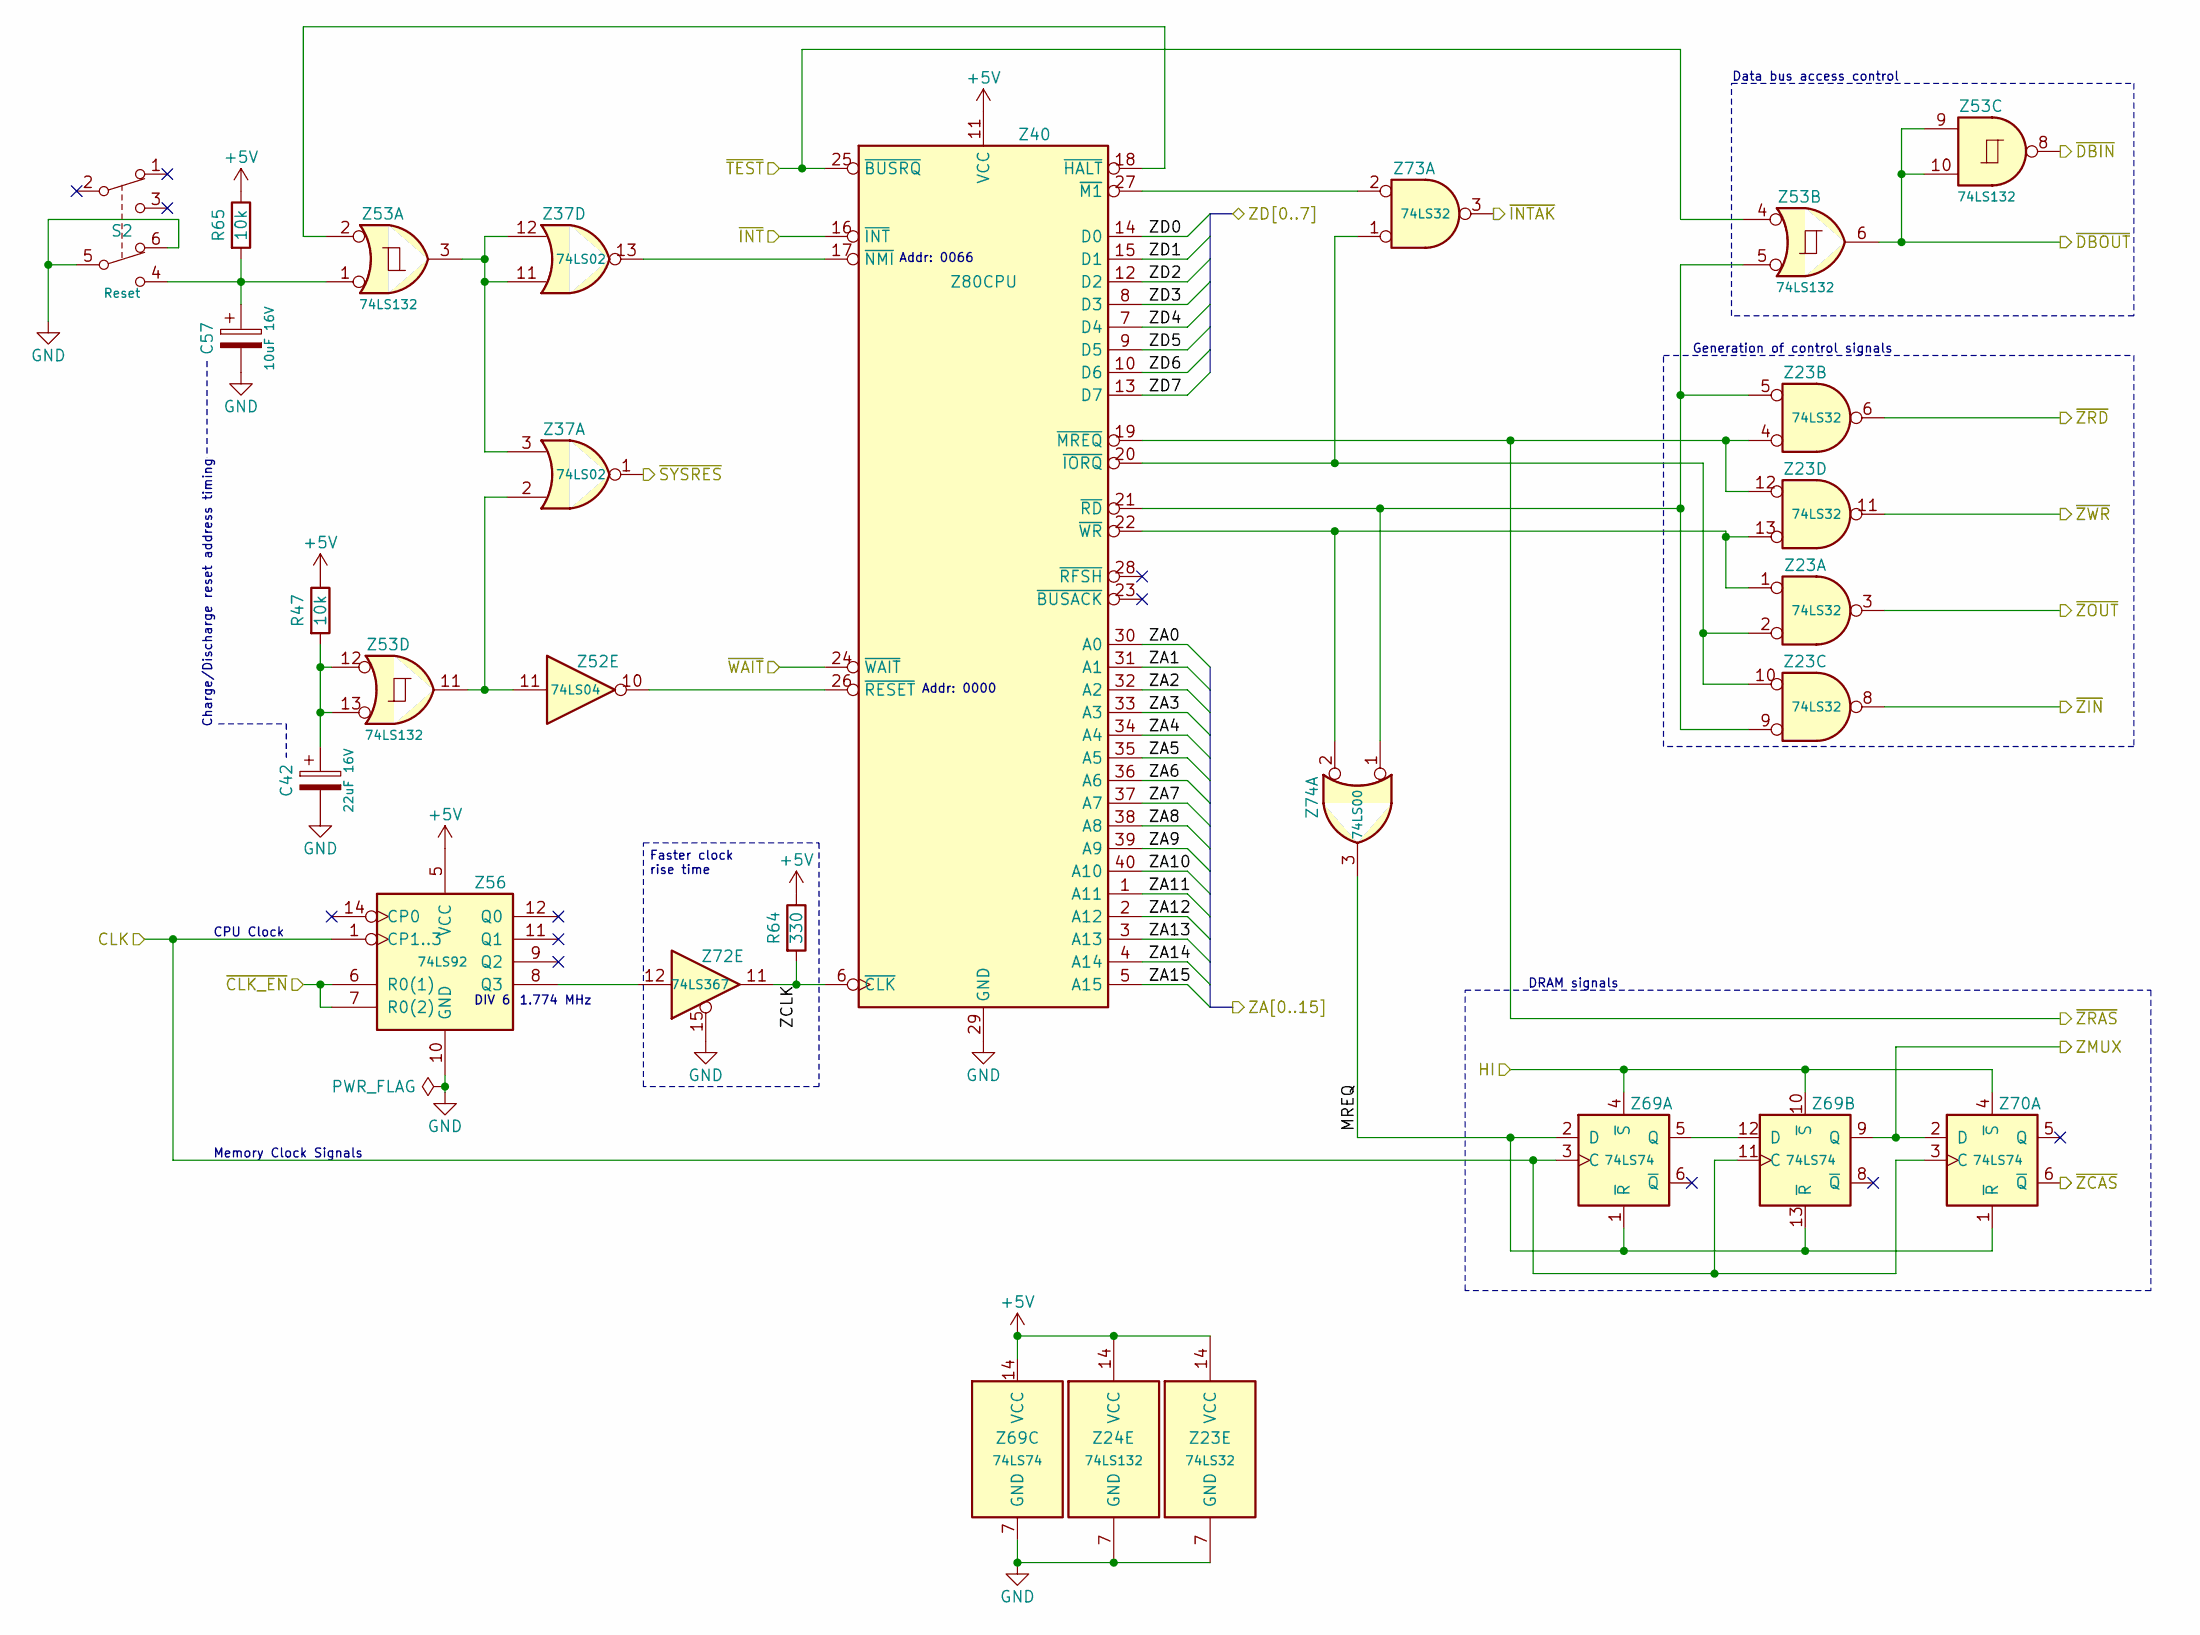
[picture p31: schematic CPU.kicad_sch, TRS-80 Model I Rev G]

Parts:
C42: 22uF 16V; TRS80_Model_I_C_Pol_Radial_6.3D_2.5P
C57: 10uF 16V; TRS80_Model_I_C_Pol_Radial_5D_2.5P
R47, R65: 10k; TRS80_Model_I_R_0.25W
R64: 330; TRS80_Model_I_R_0.25W
S2: Reset; TRS80_Model_I_Sw_Small
Z23, Z73: 74LS32; TRS80_Model_I_DIP14
Z24, Z53: 74LS132; TRS80_Model_I_DIP14
Z37: 74LS02; TRS80_Model_I_DIP14
Z40: Z80CPU; TRS80_Model_I_DIP40
Z52: 74LS04; TRS80_Model_I_DIP14
Z56: 74LS92; TRS80_Model_I_DIP14
Z69, Z70: 74LS74; TRS80_Model_I_DIP14
Z72: 74LS367; TRS80_Model_I_DIP16
Z74: 74LS00; TRS80_Model_I_DIP14

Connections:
+5V: R47.1, R64.1, R65.1, Z23.14 (VCC), Z24.14 (VCC), Z40.11 (VCC), Z53.14 (VCC), Z56.5 (VCC), Z69.14 (VCC); also elsewhere on the board
/CPU Gating/ZA0: Z40.30 (A0); also elsewhere on the board
/CPU Gating/ZA1: Z40.31 (A1); also elsewhere on the board
/CPU Gating/ZA2: Z40.32 (A2); also elsewhere on the board
/CPU Gating/ZA3: Z40.33 (A3); also elsewhere on the board
/CPU Gating/ZA4: Z40.34 (A4); also elsewhere on the board
/CPU Gating/ZA5: Z40.35 (A5); also elsewhere on the board
/CPU Gating/ZA6: Z40.36 (A6); also elsewhere on the board
/CPU Gating/ZA7: Z40.37 (A7); also elsewhere on the board
/CPU Gating/ZA8: Z40.38 (A8); also elsewhere on the board
/CPU Gating/ZA9: Z40.39 (A9); also elsewhere on the board
/CPU Gating/ZA10: Z40.40 (A10); also elsewhere on the board
/CPU Gating/ZA11: Z40.1 (A11); also elsewhere on the board
/CPU Gating/ZA12: Z40.2 (A12); also elsewhere on the board
/CPU Gating/ZA13: Z40.3 (A13); also elsewhere on the board
/CPU Gating/ZA14: Z40.4 (A14); also elsewhere on the board
/CPU Gating/ZA15: Z40.5 (A15); also elsewhere on the board
/CPU Gating/ZD0: Z40.14 (D0); also elsewhere on the board
/CPU Gating/ZD1: Z40.15 (D1); also elsewhere on the board
/CPU Gating/ZD2: Z40.12 (D2); also elsewhere on the board
/CPU Gating/ZD3: Z40.8 (D3); also elsewhere on the board
/CPU Gating/ZD4: Z40.7 (D4); also elsewhere on the board
/CPU Gating/ZD5: Z40.9 (D5); also elsewhere on the board
/CPU Gating/ZD6: Z40.10 (D6); also elsewhere on the board
/CPU Gating/ZD7: Z40.13 (D7); also elsewhere on the board
/CPU Gating/ZMUX: Z69.9 (Q), Z70.2 (D); also elsewhere on the board
/CPU Gating/~DBIN: Z53.8; also elsewhere on the board
/CPU Gating/~DBOUT: Z53.6, Z53.9, Z53.10; also elsewhere on the board
/CPU Gating/~TEST: Z40.25 (~BUSRQ), Z53.4; also elsewhere on the board
/CPU Gating/~ZCAS: Z70.6 (~Q); also elsewhere on the board
/CPU Gating/~ZIN: Z23.8; also elsewhere on the board
/CPU Gating/~ZOUT: Z23.3; also elsewhere on the board
/CPU Gating/~ZRAS: Z23.4, Z23.12, Z40.19 (~MREQ); also elsewhere on the board
/CPU Gating/~ZRD: Z23.6; also elsewhere on the board
/CPU Gating/~ZWR: Z23.11; also elsewhere on the board
/CPU/CLK: Z56.1 (CP1..3), Z69.3 (C), Z69.11 (C), Z70.3 (C); also elsewhere on the board
/CPU/HI: Z69.4 (~S), Z69.10 (~S), Z70.4 (~S); also elsewhere on the board
/CPU/MREQ: Z69.1 (~R), Z69.2 (D), Z69.13 (~R), Z70.1 (~R), Z74.3
/CPU/ZCLK: R64.2, Z40.6 (~CLK), Z72.11
/CPU/~INTAK: Z73.3; also elsewhere on the board
/CPU/~INT: Z40.16 (~INT); also elsewhere on the board
/CPU/~SYSRES: Z37.1; also elsewhere on the board
/CPU/~WAIT: Z40.24 (~WAIT); also elsewhere on the board
unnamed: C42.1, R47.2, Z53.12, Z53.13
unnamed: C57.1, R65.2, S2.4, Z53.1
unnamed: Z37.2, Z52.11, Z53.11
unnamed: Z37.3, Z37.11, Z37.12, Z53.3
unnamed: Z40.18 (~HALT), Z53.2
unnamed: Z23.2, Z23.10, Z40.20 (~IORQ), Z73.1
unnamed: Z40.27 (~M1), Z73.2
unnamed: Z37.13, Z40.17 (~NMI)
unnamed: Z23.5, Z23.9, Z40.21 (~RD), Z53.5, Z74.1
unnamed: Z40.26 (~RESET), Z52.10
unnamed: Z23.1, Z23.13, Z40.22 (~WR), Z74.2
unnamed: Z56.8 (Q3), Z72.12
unnamed: Z69.5 (Q), Z69.12 (D)

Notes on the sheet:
Data bus access control
DIV 6
Generation of control signals
DRAM signals
1.774 MHz
Faster clock rise time
Memory Clock Signals
CPU Clock
Addr: 0000
Charge/Discharge reset address timing
Addr: 0066

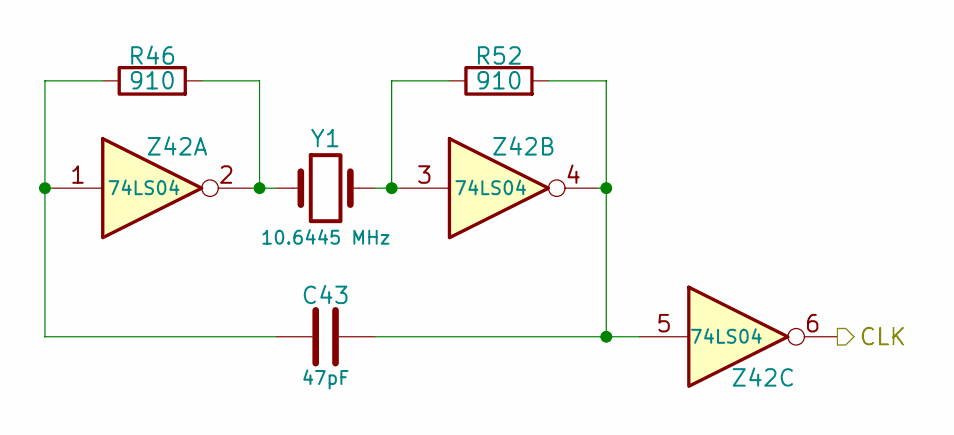
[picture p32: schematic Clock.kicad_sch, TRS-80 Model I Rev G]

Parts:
C43: 47pF; TRS80_Model_I_C_Disc_9.5L_4W_6P_Small
R46, R52: 910; TRS80_Model_I_R_0.25W
Y1: 10.6445 MHz; TRS80_Model_I_Crystal
Z42: 74LS04; TRS80_Model_I_DIP14

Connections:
/CPU/CLK: Z42.6; also elsewhere on the board
unnamed: C43.1, R46.1, Z42.1
unnamed: C43.2, R52.2, Z42.4, Z42.5
unnamed: R46.2, Y1.1, Z42.2
unnamed: R52.1, Y1.2, Z42.3

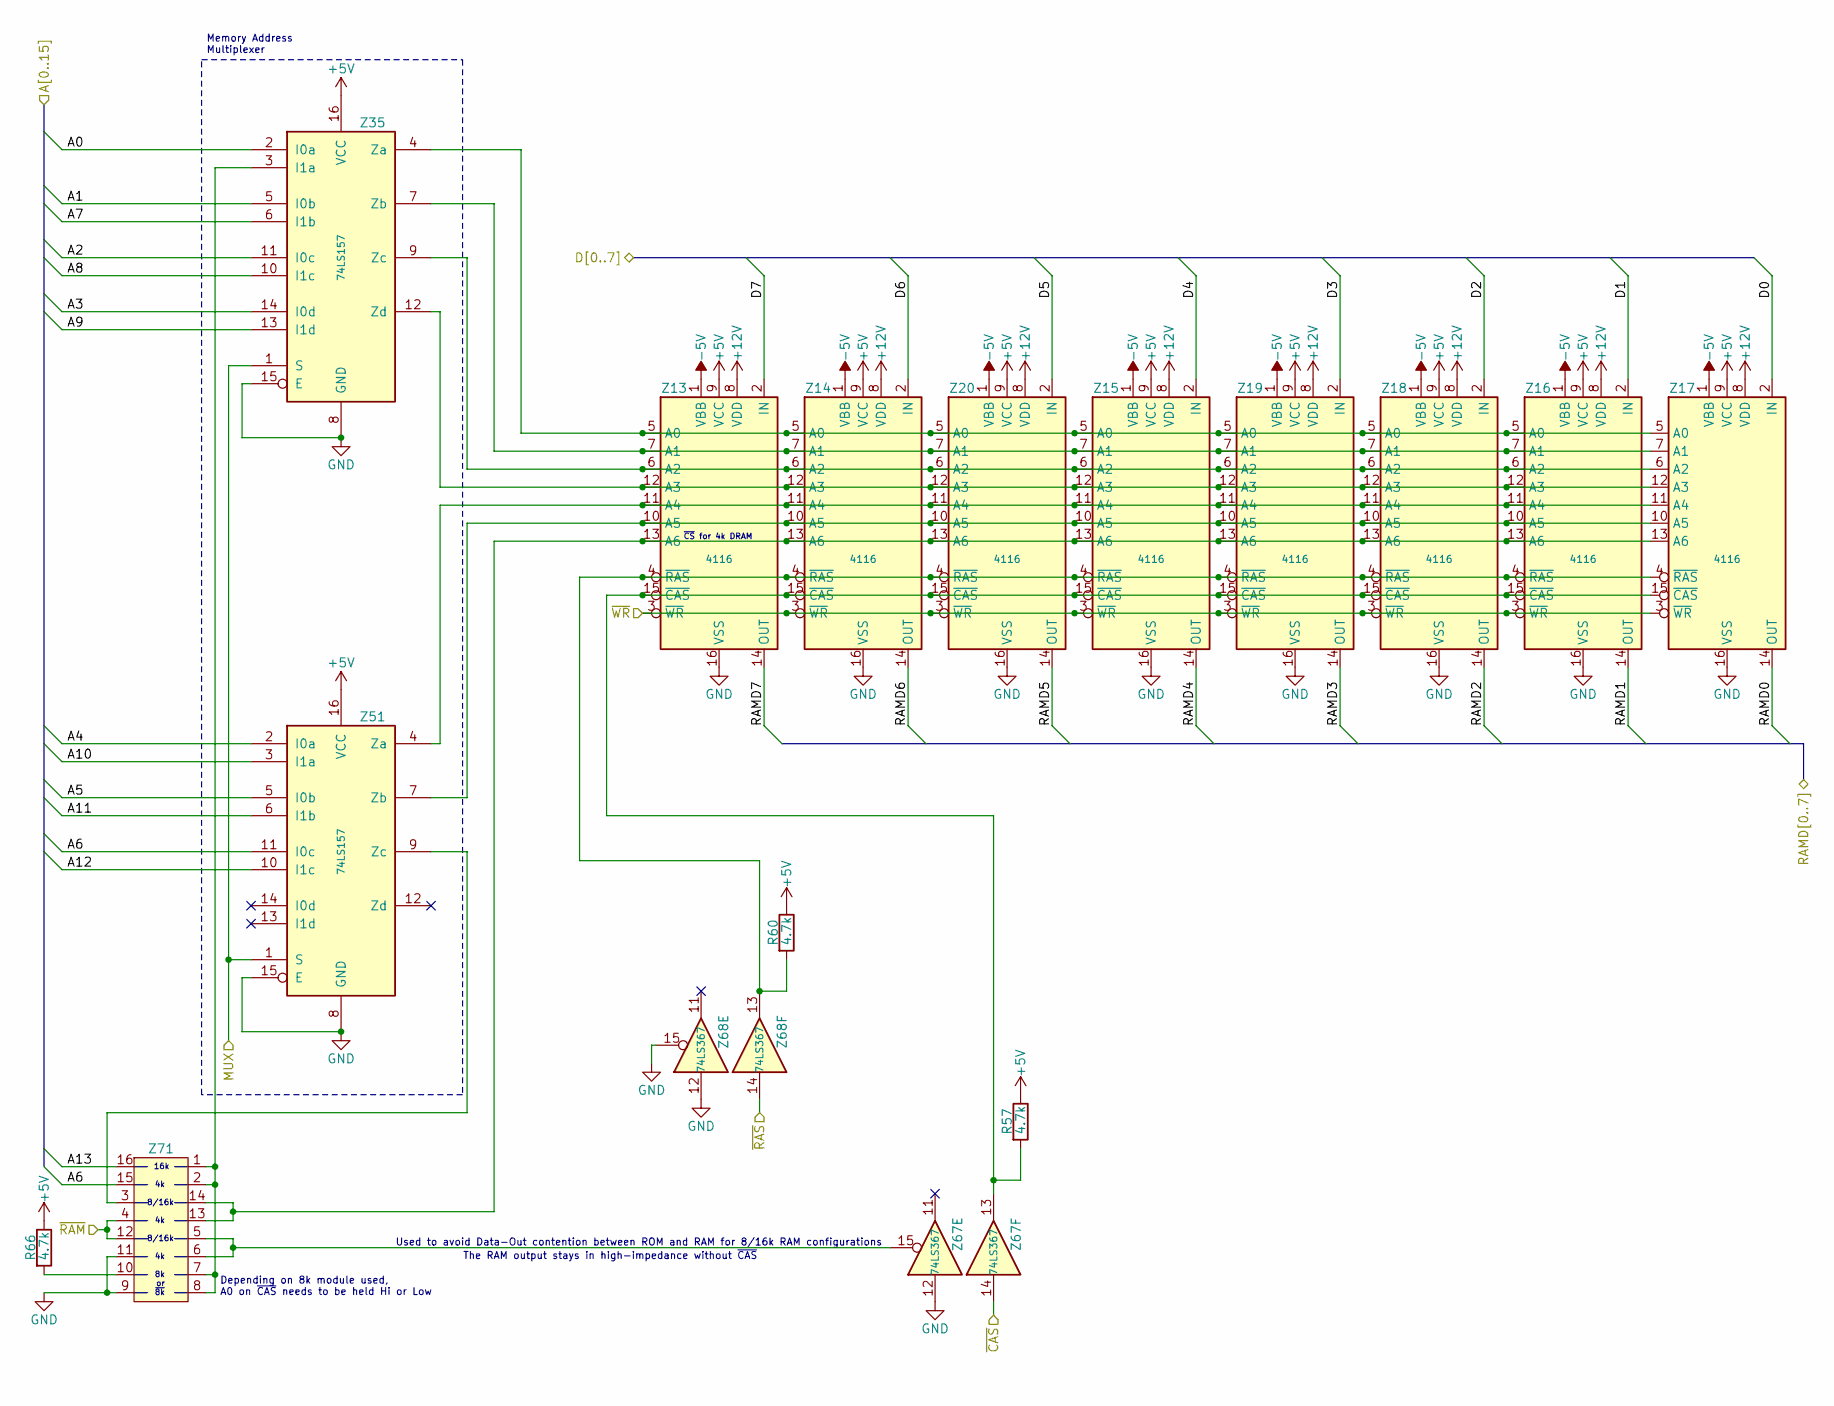
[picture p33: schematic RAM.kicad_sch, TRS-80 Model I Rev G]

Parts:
R57, R60, R66: 4.7k; TRS80_Model_I_R_0.25W
Z13, Z14, Z15, Z16, Z17, Z18, Z19, Z20: 4116; DIP-16_W7.62mm
Z35, Z51: 74LS157; TRS80_Model_I_DIP16
Z67, Z68: 74LS367; TRS80_Model_I_DIP16
Z71: DIP-16_W7.62mm

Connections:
+5V: R57.1, R60.1, R66.1, Z13.9 (VCC), Z14.9 (VCC), Z15.9 (VCC), Z16.9 (VCC), Z17.9 (VCC), Z18.9 (VCC), Z19.9 (VCC), Z20.9 (VCC), Z35.16 (VCC), Z51.16 (VCC); also elsewhere on the board
+12V: Z13.8 (VDD), Z14.8 (VDD), Z15.8 (VDD), Z16.8 (VDD), Z17.8 (VDD), Z18.8 (VDD), Z19.8 (VDD), Z20.8 (VDD); also elsewhere on the board
-5V: Z13.1 (VBB), Z14.1 (VBB), Z15.1 (VBB), Z16.1 (VBB), Z17.1 (VBB), Z18.1 (VBB), Z19.1 (VBB), Z20.1 (VBB); also elsewhere on the board
/A0: Z35.2 (I0a); also elsewhere on the board
/A1: Z35.5 (I0b); also elsewhere on the board
/A2: Z35.11 (I0c); also elsewhere on the board
/A3: Z35.14 (I0d); also elsewhere on the board
/A4: Z51.2 (I0a); also elsewhere on the board
/A5: Z51.5 (I0b); also elsewhere on the board
/A6: Z51.11 (I0c), Z71.15; also elsewhere on the board
/A7: Z35.6 (I1b); also elsewhere on the board
/A8: Z35.10 (I1c); also elsewhere on the board
/A9: Z35.13 (I1d); also elsewhere on the board
/A10: Z51.3 (I1a); also elsewhere on the board
/A11: Z51.6 (I1b); also elsewhere on the board
/A12: Z51.10 (I1c); also elsewhere on the board
/A13: Z71.16; also elsewhere on the board
/Address Decoder/~RAM: Z71.4, Z71.12; also elsewhere on the board
/Address Decoder/~RAS: Z68.14; also elsewhere on the board
/CPU Gating/MUX: Z35.1 (S), Z51.1 (S); also elsewhere on the board
/CPU Gating/~CAS: Z67.14; also elsewhere on the board
/CPU Gating/~WR: Z13.3 (~WR), Z14.3 (~WR), Z15.3 (~WR), Z16.3 (~WR), Z17.3 (~WR), Z18.3 (~WR), Z19.3 (~WR), Z20.3 (~WR); also elsewhere on the board
/D0: Z17.2 (IN); also elsewhere on the board
/D1: Z16.2 (IN); also elsewhere on the board
/D3: Z19.2 (IN); also elsewhere on the board
/D4: Z15.2 (IN); also elsewhere on the board
/D5: Z20.2 (IN); also elsewhere on the board
/D7: Z13.2 (IN); also elsewhere on the board
/RAM-ROM Interface/ROMD0: Z17.14 (OUT); also elsewhere on the board
/RAM-ROM Interface/ROMD1: Z16.14 (OUT); also elsewhere on the board
/RAM-ROM Interface/ROMD2: Z18.14 (OUT); also elsewhere on the board
/RAM-ROM Interface/ROMD3: Z19.14 (OUT); also elsewhere on the board
/RAM-ROM Interface/ROMD4: Z15.14 (OUT); also elsewhere on the board
/RAM-ROM Interface/ROMD5: Z20.14 (OUT); also elsewhere on the board
/RAM-ROM Interface/ROMD6: Z14.14 (OUT); also elsewhere on the board
/RAM-ROM Interface/ROMD7: Z13.14 (OUT); also elsewhere on the board
unnamed: R66.2, Z71.10
unnamed: Z13.5 (A0), Z14.5 (A0), Z15.5 (A0), Z16.5 (A0), Z17.5 (A0), Z18.5 (A0), Z19.5 (A0), Z20.5 (A0), Z35.4 (Za)
unnamed: Z13.7 (A1), Z14.7 (A1), Z15.7 (A1), Z16.7 (A1), Z17.7 (A1), Z18.7 (A1), Z19.7 (A1), Z20.7 (A1), Z35.7 (Zb)
unnamed: Z13.6 (A2), Z14.6 (A2), Z15.6 (A2), Z16.6 (A2), Z17.6 (A2), Z18.6 (A2), Z19.6 (A2), Z20.6 (A2), Z35.9 (Zc)
unnamed: Z13.12 (A3), Z14.12 (A3), Z15.12 (A3), Z16.12 (A3), Z17.12 (A3), Z18.12 (A3), Z19.12 (A3), Z20.12 (A3), Z35.12 (Zd)
unnamed: Z13.11 (A4), Z14.11 (A4), Z15.11 (A4), Z16.11 (A4), Z17.11 (A4), Z18.11 (A4), Z19.11 (A4), Z20.11 (A4), Z51.4 (Za)
unnamed: Z13.10 (A5), Z14.10 (A5), Z15.10 (A5), Z16.10 (A5), Z17.10 (A5), Z18.10 (A5), Z19.10 (A5), Z20.10 (A5), Z51.7 (Zb)
unnamed: Z13.13 (A6), Z14.13 (A6), Z15.13 (A6), Z16.13 (A6), Z17.13 (A6), Z18.13 (A6), Z19.13 (A6), Z20.13 (A6), Z71.13, Z71.14
unnamed: R57.2, Z13.15 (~CAS), Z14.15 (~CAS), Z15.15 (~CAS), Z16.15 (~CAS), Z17.15 (~CAS), Z18.15 (~CAS), Z19.15 (~CAS), Z20.15 (~CAS), Z67.13
unnamed: R60.2, Z13.4 (~RAS), Z14.4 (~RAS), Z15.4 (~RAS), Z16.4 (~RAS), Z17.4 (~RAS), Z18.4 (~RAS), Z19.4 (~RAS), Z20.4 (~RAS), Z68.13
unnamed: Z35.3 (I1a), Z71.1, Z71.2, Z71.7, Z71.8
unnamed: Z51.9 (Zc), Z71.3
unnamed: Z67.15, Z71.5, Z71.6

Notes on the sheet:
Memory Address Multiplexer
~{8k}
The RAM output stays in high-impedance without ~{CAS}
8/16k
Used to avoid Data-Out contention between ROM and RAM for 8/16k RAM configurations
~{CS} for 4k DRAM
Depending on 8k module used, A0 on ~{CAS} needs to be held Hi or Low
16k

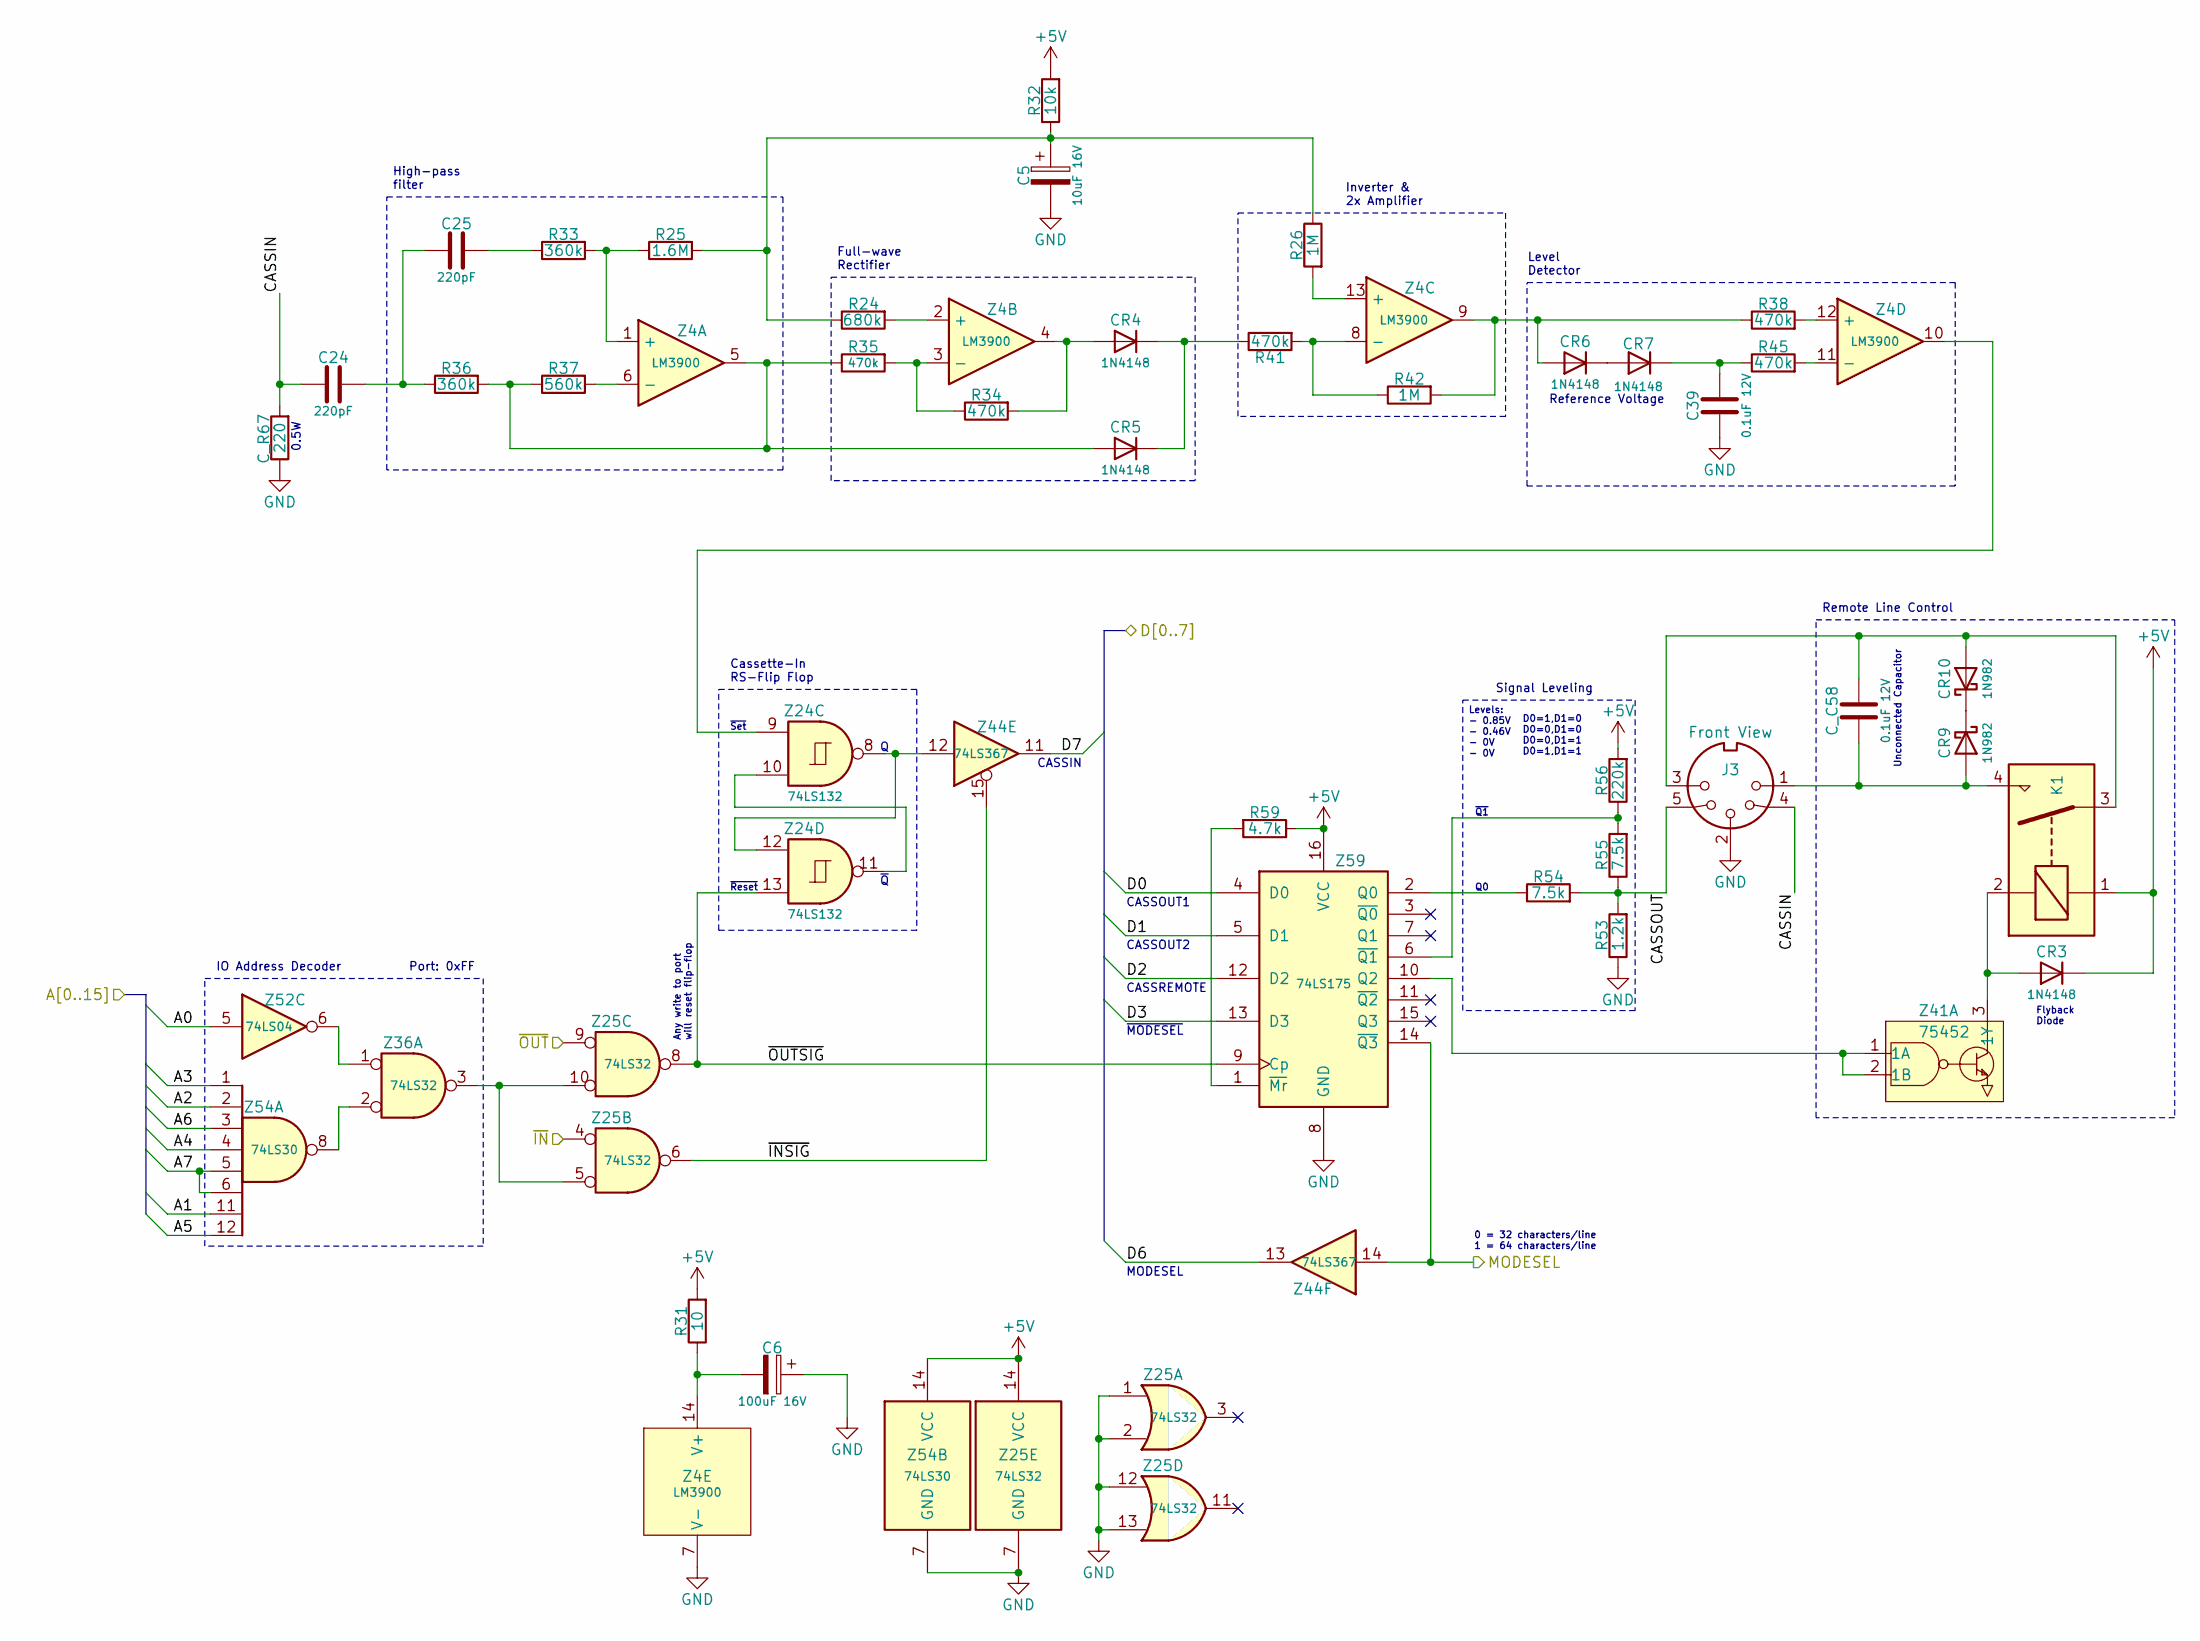
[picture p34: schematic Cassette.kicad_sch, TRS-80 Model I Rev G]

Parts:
C5: 10uF 16V; TRS80_Model_I_C_Pol_Radial_5D_2.5P
C6: 100uF 16V; TRS80_Model_I_C_Pol_Radial_10D_5P
C24, C25: 220pF; TRS80_Model_I_C_Disc_9.5L_4W_6P_Small
C39: 0.1uF 12V; TRS80_Model_I_C_Disc_9.5L_4W_6P_Small
CR3, CR4, CR5, CR6, CR7: 1N4148; TRS80_Model_I_D
CR9, CR10: 1N982; TRS80_Model_I_D
C_C58: 0.1uF 12V; TRS80_Model_I_C_Disc_9.5L_4W_6P_Small
C_R67: 220; TRS80_Model_I_R_0.25W
J3: Front View; TRS80_Model_I_DIN5
K1: Relay_SPST-NO; TRS80_Model_I_Relay
R24: 680k; TRS80_Model_I_R_0.25W
R25: 1.6M; TRS80_Model_I_R_0.25W
R26, R42: 1M; TRS80_Model_I_R_0.25W
R31: 10; TRS80_Model_I_R_0.25W
R32: 10k; TRS80_Model_I_R_0.25W
R33, R36: 360k; TRS80_Model_I_R_0.25W
R34, R35, R38, R41, R45: 470k; TRS80_Model_I_R_0.25W
R37: 560k; TRS80_Model_I_R_0.25W
R53: 1.2k; TRS80_Model_I_R_0.25W
R54, R55: 7.5k; TRS80_Model_I_R_0.25W
R56: 220k; TRS80_Model_I_R_0.25W
R59: 4.7k; TRS80_Model_I_R_0.25W
Z4: LM3900; TRS80_Model_I_DIP14
Z24: 74LS132; TRS80_Model_I_DIP14
Z25, Z36: 74LS32; TRS80_Model_I_DIP14
Z41: 75452; TRS80_Model_I_DIP8
Z44: 74LS367; TRS80_Model_I_DIP16
Z52: 74LS04; TRS80_Model_I_DIP14
Z54: 74LS30; TRS80_Model_I_DIP14
Z59: 74LS175; TRS80_Model_I_DIP16

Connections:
+5V: CR3.1 (K), K1.1, R31.2, R32.2, R56.2, R59.1, Z25.14 (VCC), Z54.14 (VCC), Z59.16 (VCC); also elsewhere on the board
/A0: Z52.5; also elsewhere on the board
/A1: Z54.11; also elsewhere on the board
/A2: Z54.2; also elsewhere on the board
/A3: Z54.1; also elsewhere on the board
/A4: Z54.4; also elsewhere on the board
/A5: Z54.12; also elsewhere on the board
/A6: Z54.3; also elsewhere on the board
/A7: Z54.5, Z54.6; also elsewhere on the board
/CPU Gating/~IN: Z25.4; also elsewhere on the board
/CPU Gating/~OUT: Z25.9; also elsewhere on the board
/Cassette Interface/CASSIN: C24.1, C_R67.2, J3.4
/Cassette Interface/CASSOUT: J3.5, R53.2, R54.2, R55.1
/Cassette Interface/~INSIG: Z25.6, Z44.15
/D0: Z59.4 (D0); also elsewhere on the board
/D1: Z59.5 (D1); also elsewhere on the board
/D3: Z59.13 (D3); also elsewhere on the board
/D7: Z44.11; also elsewhere on the board
unnamed: C5.1, R24.1, R25.2, R26.1, R32.1
unnamed: C24.2, C25.1, R36.1
unnamed: C25.2, R33.1
unnamed: CR3.2 (A), K1.2, Z41.3 (1Y)
unnamed: CR4.2 (A), R34.2, Z4.4
unnamed: CR4.1 (K), CR5.1 (K), R41.1
unnamed: CR5.2 (A), R35.1, R36.2, R37.1, Z4.5
unnamed: CR6.2 (A), R38.1, R42.2, Z4.9
unnamed: CR6.1 (K), CR7.2 (A)
unnamed: C39.2, CR7.1 (K), R45.1
unnamed: CR9.2 (A), C_C58.2, J3.1, K1.4
unnamed: CR10.2 (A), C_C58.1, J3.3, K1.3
unnamed: CR9.1 (K), CR10.1 (K)
unnamed: R25.1, R33.2, Z4.1 (+)
unnamed: R37.2, Z4.6 (-)
unnamed: R24.2, Z4.2 (+)
unnamed: R34.1, R35.2, Z4.3 (-)
unnamed: R26.2, Z4.13 (+)
unnamed: R41.2, R42.1, Z4.8 (-)
unnamed: R38.2, Z4.12 (+)
unnamed: R45.2, Z4.11 (-)
unnamed: C6.2, R31.1, Z4.14 (V+)
unnamed: Z4.10, Z24.9
unnamed: Z24.10, Z24.11
unnamed: Z25.5, Z25.10, Z36.3
unnamed: Z36.1, Z52.6
unnamed: Z36.2, Z54.8
unnamed: Z41.1 (1A), Z41.2 (1B), Z59.10 (Q2)
unnamed: R54.1, Z59.2 (Q0)
unnamed: R59.2, Z59.1 (~Mr)
unnamed: R55.2, R56.1, Z59.6 (~Q1)

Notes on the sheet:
~{MODESEL}
0 = 32 characters/line 1 = 64 characters/line
Full-wave Rectifier
Level Detector
High-pass filter
Unconnected Capacitor
Reference Voltage
Any write to port will reset flip-flop
IO Address Decoder
CASSREMOTE
Remote Line Control
Port: 0xFF
~{Q}
CASSOUT1
Flyback Diode
Signal Leveling
0.5W
CASSOUT2
CASSIN
MODESEL
Cassette-In RS-Flip Flop
~{Q1}
Levels: - 0.85V - 0.46V - 0V - 0V
Inverter & 2x Amplifier
~{Reset}
~{Set}
D0=1,D1=0 D0=0,D1=0 D0=0,D1=1 D0=1,D1=1

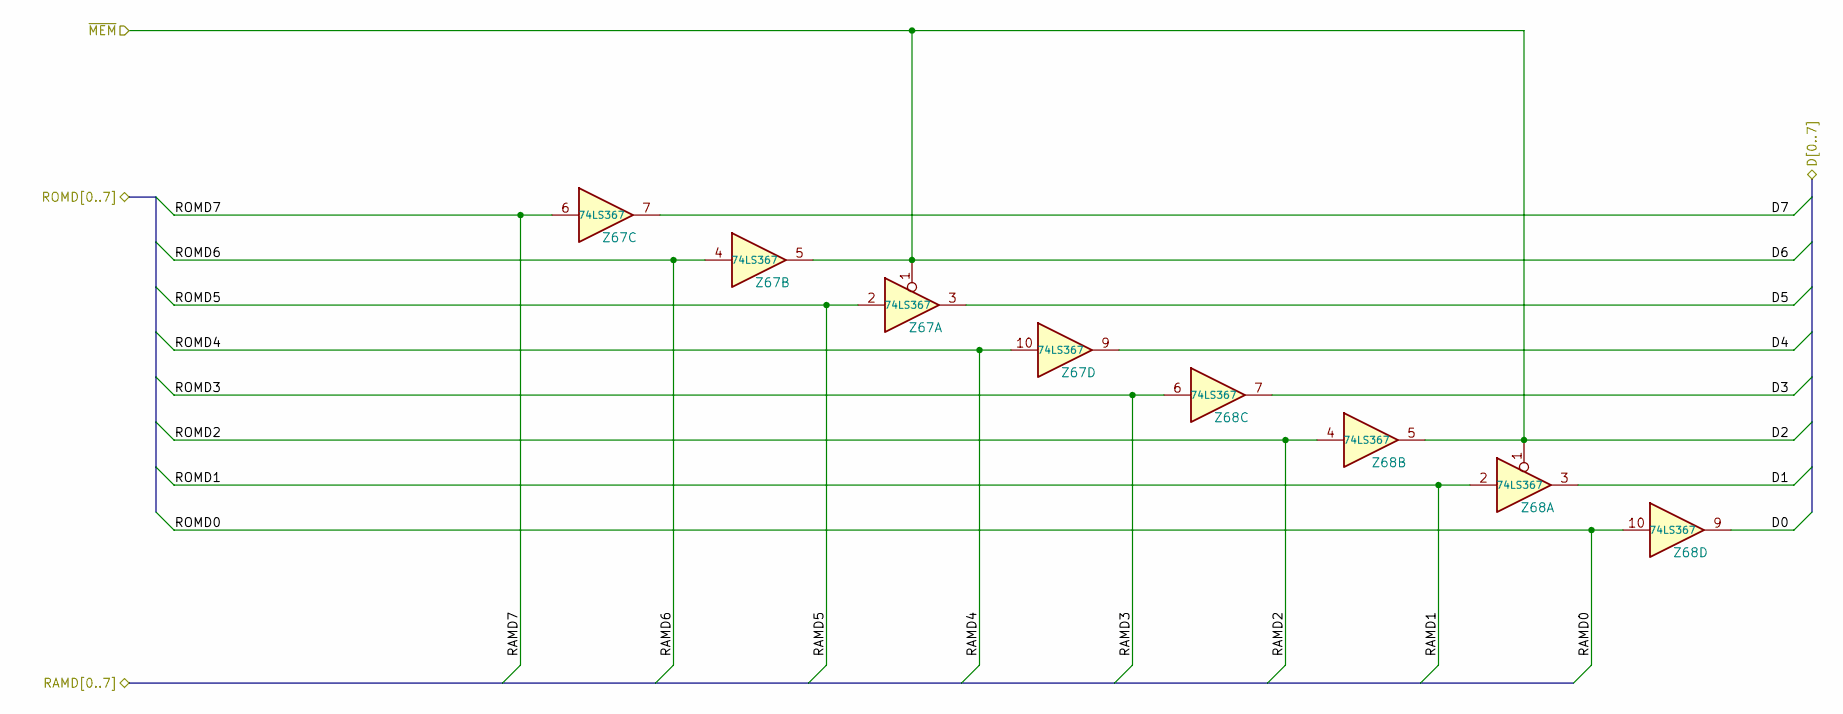
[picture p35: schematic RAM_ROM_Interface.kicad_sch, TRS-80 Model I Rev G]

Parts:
Z67, Z68: 74LS367; TRS80_Model_I_DIP16

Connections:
/D0: Z68.9; also elsewhere on the board
/D1: Z68.3; also elsewhere on the board
/D3: Z68.7; also elsewhere on the board
/D4: Z67.9; also elsewhere on the board
/D5: Z67.3; also elsewhere on the board
/D7: Z67.7; also elsewhere on the board
/RAM-ROM Interface/ROMD0: Z68.10; also elsewhere on the board
/RAM-ROM Interface/ROMD1: Z68.2; also elsewhere on the board
/RAM-ROM Interface/ROMD2: Z68.4; also elsewhere on the board
/RAM-ROM Interface/ROMD3: Z68.6; also elsewhere on the board
/RAM-ROM Interface/ROMD4: Z67.10; also elsewhere on the board
/RAM-ROM Interface/ROMD5: Z67.2; also elsewhere on the board
/RAM-ROM Interface/ROMD6: Z67.4; also elsewhere on the board
/RAM-ROM Interface/ROMD7: Z67.6; also elsewhere on the board

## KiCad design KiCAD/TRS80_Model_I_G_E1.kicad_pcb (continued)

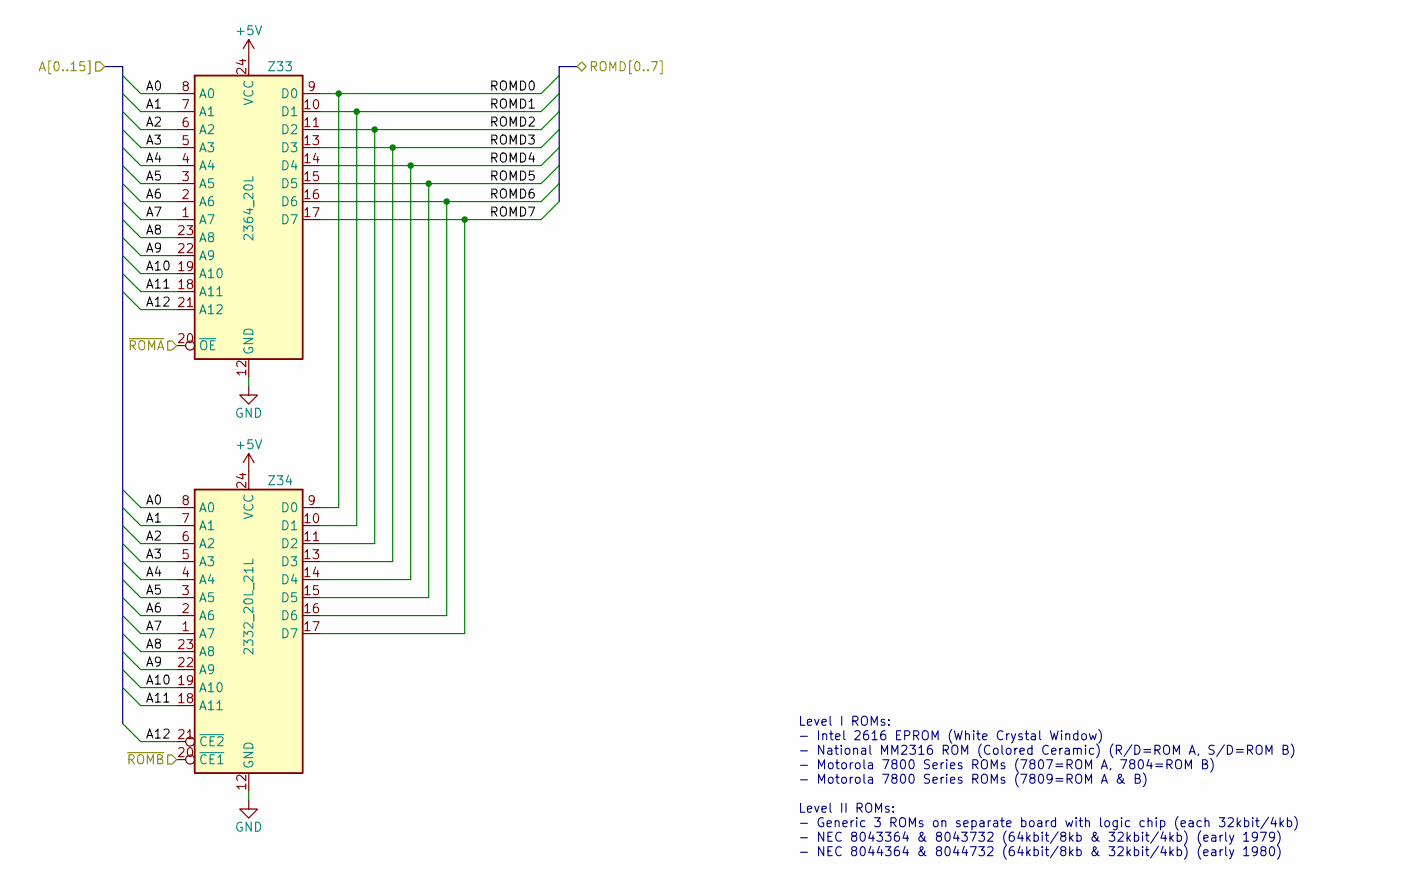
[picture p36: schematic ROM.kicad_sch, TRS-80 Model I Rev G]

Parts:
Z33: 2364_20L; DIP-24_W15.24mm
Z34: 2332_20L_21L; DIP-24_W15.24mm

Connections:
+5V: Z33.24 (VCC), Z34.24 (VCC); also elsewhere on the board
/A0: Z33.8 (A0), Z34.8 (A0); also elsewhere on the board
/A1: Z33.7 (A1), Z34.7 (A1); also elsewhere on the board
/A2: Z33.6 (A2), Z34.6 (A2); also elsewhere on the board
/A3: Z33.5 (A3), Z34.5 (A3); also elsewhere on the board
/A4: Z33.4 (A4), Z34.4 (A4); also elsewhere on the board
/A5: Z33.3 (A5), Z34.3 (A5); also elsewhere on the board
/A6: Z33.2 (A6), Z34.2 (A6); also elsewhere on the board
/A7: Z33.1 (A7), Z34.1 (A7); also elsewhere on the board
/A8: Z33.23 (A8), Z34.23 (A8); also elsewhere on the board
/A9: Z33.22 (A9), Z34.22 (A9); also elsewhere on the board
/A10: Z33.19 (A10), Z34.19 (A10); also elsewhere on the board
/A11: Z33.18 (A11), Z34.18 (A11); also elsewhere on the board
/A12: Z33.21 (A12), Z34.21 (~CE2); also elsewhere on the board
/Address Decoder/~ROMA: Z33.20 (~OE); also elsewhere on the board
/Address Decoder/~ROMB: Z34.20 (~CE1); also elsewhere on the board
/RAM-ROM Interface/ROMD0: Z33.9 (D0), Z34.9 (D0); also elsewhere on the board
/RAM-ROM Interface/ROMD1: Z33.10 (D1), Z34.10 (D1); also elsewhere on the board
/RAM-ROM Interface/ROMD2: Z33.11 (D2), Z34.11 (D2); also elsewhere on the board
/RAM-ROM Interface/ROMD3: Z33.13 (D3), Z34.13 (D3); also elsewhere on the board
/RAM-ROM Interface/ROMD4: Z33.14 (D4), Z34.14 (D4); also elsewhere on the board
/RAM-ROM Interface/ROMD5: Z33.15 (D5), Z34.15 (D5); also elsewhere on the board
/RAM-ROM Interface/ROMD6: Z33.16 (D6), Z34.16 (D6); also elsewhere on the board
/RAM-ROM Interface/ROMD7: Z33.17 (D7), Z34.17 (D7); also elsewhere on the board

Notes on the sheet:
Level I ROMs: - Intel 2616 EPROM (White Crystal Window) - National MM2316 ROM (Colored Ceramic) (R/D=ROM A, S/D=ROM B) - Motorola 7800 Series ROMs (7807=ROM A, 7804=ROM B) - Motorola 7800 Series ROMs (7809=ROM A & B) Level II ROMs: - Generic 3 ROMs on separate board with logic chip (each 32kbit/4kb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

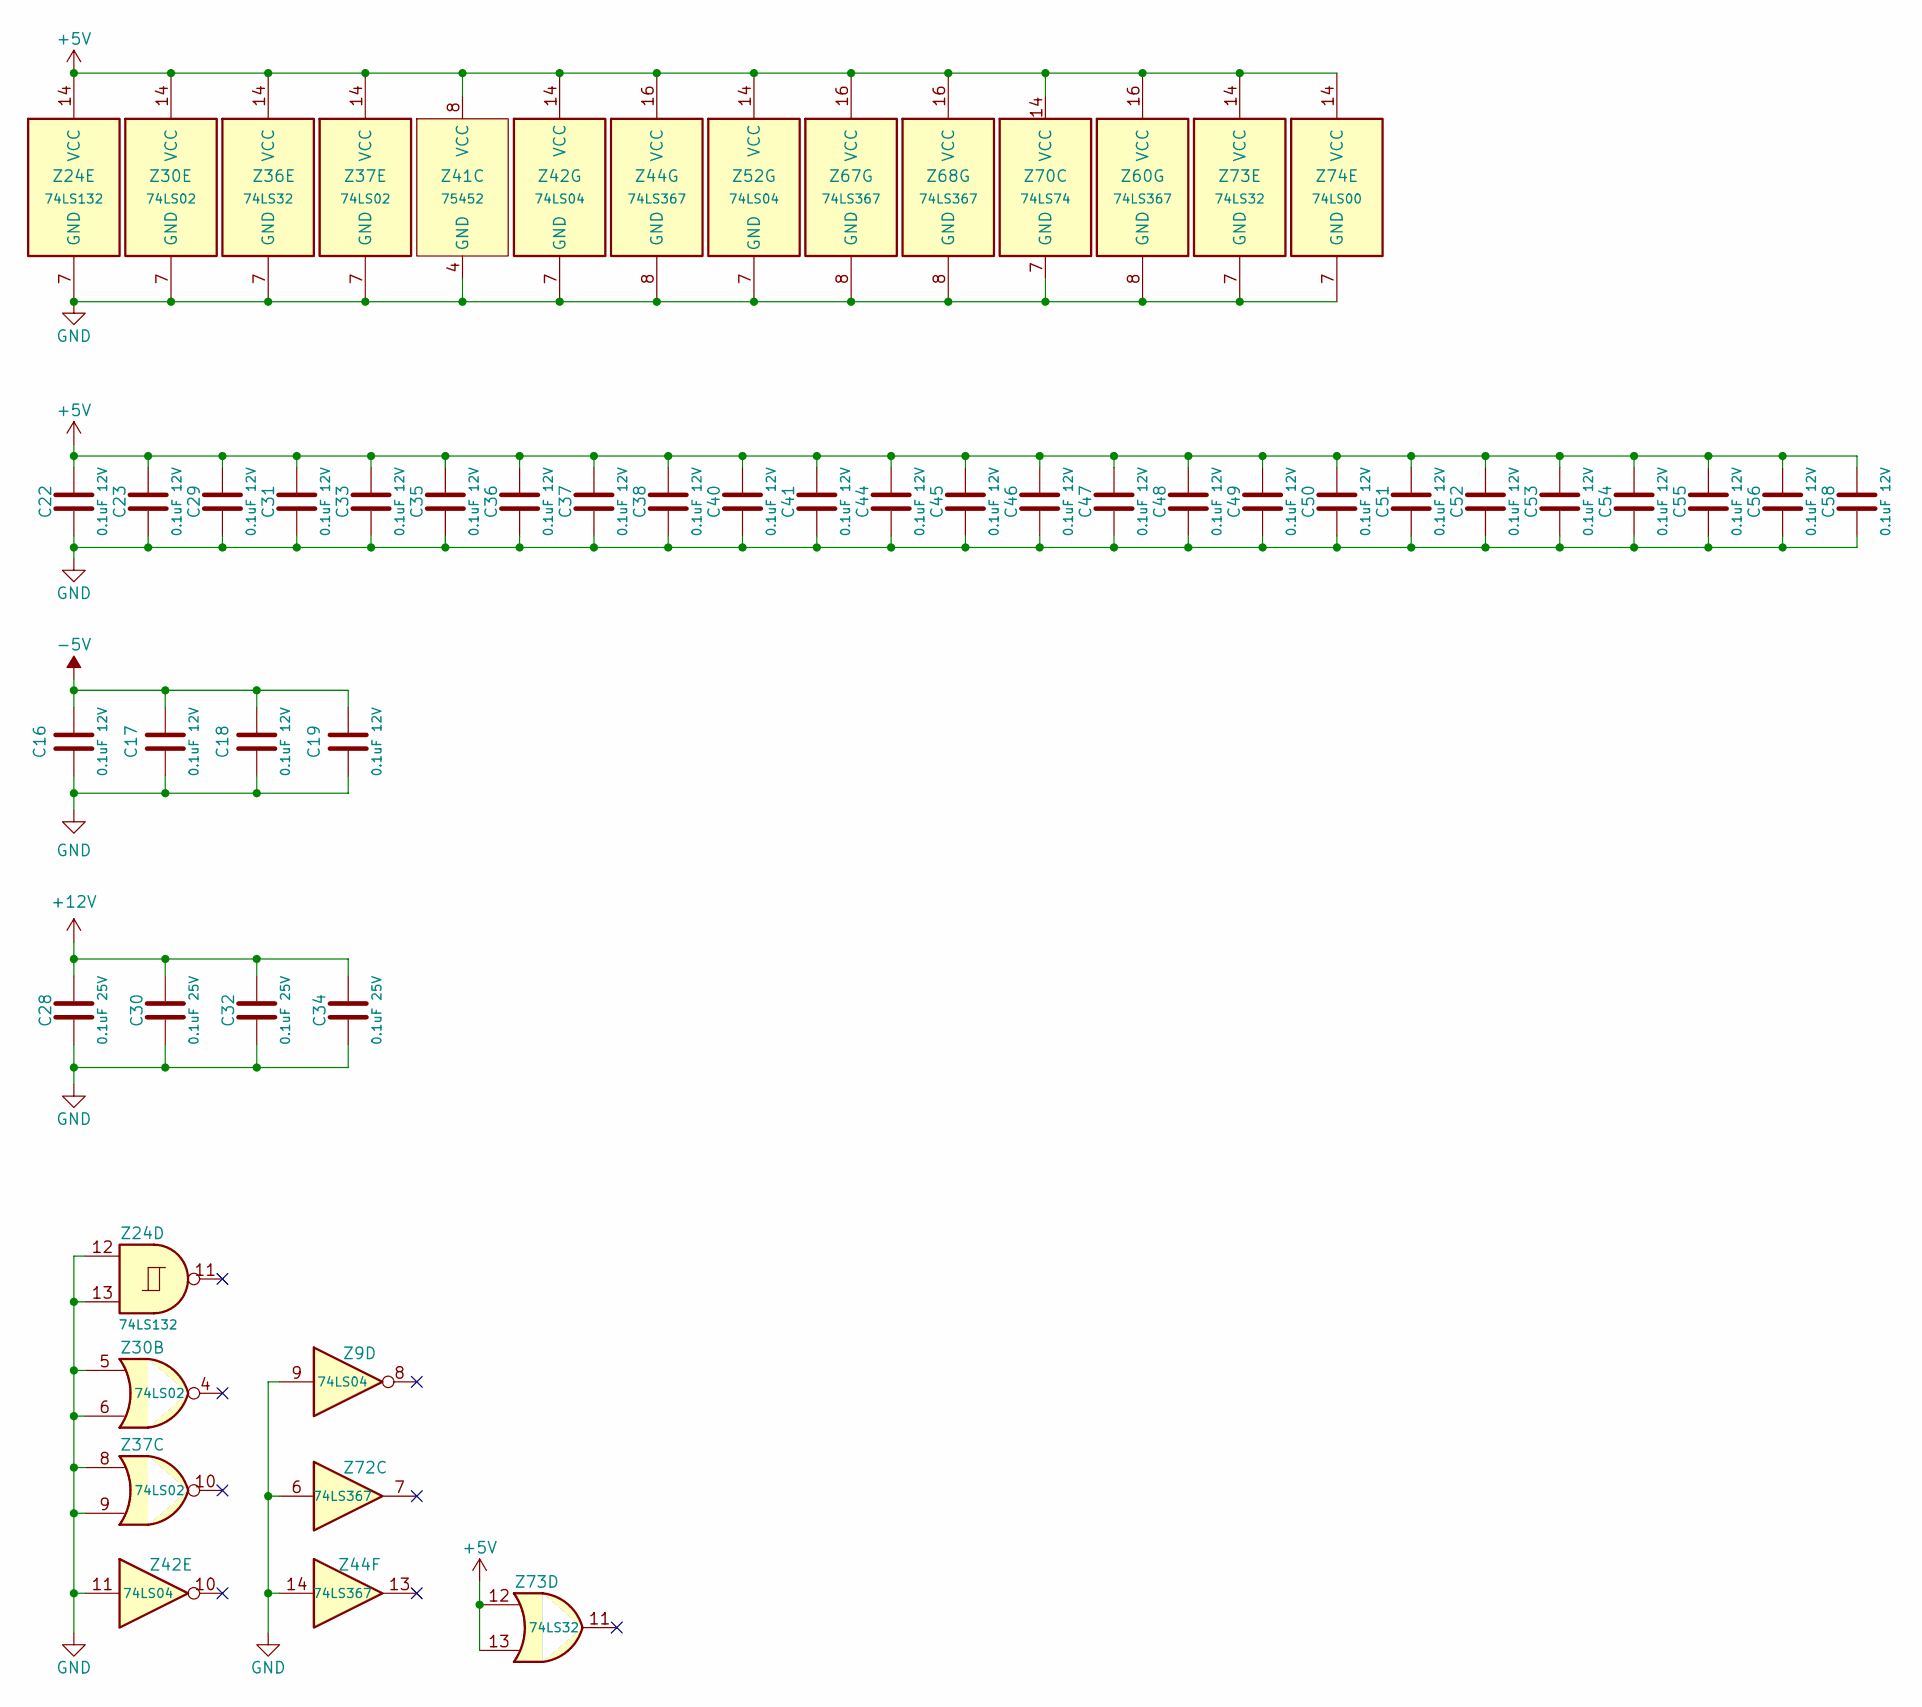
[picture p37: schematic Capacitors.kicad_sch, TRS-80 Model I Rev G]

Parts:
C16, C17, C18, C19, C22, C23, C29, C31, C33, C35, C36, C37, C38, C40, C41, C44, C45, C46, C47, C48, C49, C50, C51, C52, C53, C54, C55, C56, C58: 0.1uF 12V; TRS80_Model_I_C_Disc_9.5L_4W_6P_Small
C28, C30, C32, C34: 0.1uF 25V; TRS80_Model_I_C_Disc_18.5L_4W_8.5P_Large
Z9, Z42, Z52: 74LS04; TRS80_Model_I_DIP14
Z24: 74LS132; TRS80_Model_I_DIP14
Z30, Z37: 74LS02; TRS80_Model_I_DIP14
Z36, Z73: 74LS32; TRS80_Model_I_DIP14
Z41: 75452; TRS80_Model_I_DIP8
Z44, Z60, Z67, Z68, Z72: 74LS367; TRS80_Model_I_DIP16
Z70: 74LS74; TRS80_Model_I_DIP14
Z74: 74LS00; TRS80_Model_I_DIP14

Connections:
+5V: C22.1, C23.1, C29.1, C31.1, C33.1, C35.1, C36.1, C37.1, C38.1, C40.1, C41.1, C44.1, C45.1, C46.1, C47.1, C48.1, C49.1, C50.1, C51.1, C52.1, C53.1, C54.1, C55.1, C56.1, C58.1, Z24.14 (VCC), Z30.14 (VCC), Z36.14 (VCC), Z37.14 (VCC), Z41.8 (VCC), Z42.14 (VCC), Z44.16 (VCC), Z52.14 (VCC), Z60.16 (VCC), Z67.16 (VCC), Z68.16 (VCC), Z70.14 (VCC), Z72.16 (VCC), Z73.12, Z73.13, Z73.14 (VCC), Z74.14 (VCC); also elsewhere on the board
+12V: C28.1, C30.1, C32.1, C34.1; also elsewhere on the board
-5V: C16.1, C17.1, C18.1, C19.1; also elsewhere on the board
unnamed 255: Z24.11; also elsewhere on the board

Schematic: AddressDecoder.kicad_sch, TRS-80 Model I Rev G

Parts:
R48, R61, R62, R68: 4.7k; TRS80_Model_I_R_0.25W
Z3: DIP-16_W7.62mm
Z21: 74LS156; TRS80_Model_I_DIP16
Z36, Z73: 74LS32; TRS80_Model_I_DIP14
Z37: 74LS02; TRS80_Model_I_DIP14
Z52: 74LS04; TRS80_Model_I_DIP14
Z74: 74LS00; TRS80_Model_I_DIP14

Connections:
+5V: R48.2, R61.2, R62.2, R68.2, Z21.16 (VCC); also elsewhere on the board
/A10: Z36.13, Z52.1; also elsewhere on the board
/A11: Z37.5, Z37.6; also elsewhere on the board
/A12: Z21.13 (A0); also elsewhere on the board
/A13: Z21.3 (A1); also elsewhere on the board
/A14: Z21.1 (Ea1), Z21.15 (Eb2); also elsewhere on the board
/A15: Z73.4; also elsewhere on the board
/Address Decoder/~KYBD: Z36.11; also elsewhere on the board
/Address Decoder/~RAM: R62.1, Z3.12, Z3.13, Z3.14, Z3.15, Z74.10; also elsewhere on the board
/Address Decoder/~RAS: Z73.5; also elsewhere on the board
/Address Decoder/~RD: Z52.13; also elsewhere on the board
/Address Decoder/~ROMA: R61.1, Z3.7, Z3.8, Z74.9; also elsewhere on the board
/Address Decoder/~ROMB: R68.1, Z3.1, Z3.6, Z74.12, Z74.13; also elsewhere on the board
/Address Decoder/~VID: Z36.8; also elsewhere on the board
unnamed: Z21.2 (Ea2), Z21.14 (Eb1), Z73.6
unnamed: Z3.2, Z21.7 (Q0a)
unnamed: Z3.10, Z3.16, Z21.9 (Q0b)
unnamed: Z3.3, Z21.6 (Q1a)
unnamed: Z3.9, Z21.10 (Q1b)
unnamed: Z3.4, Z21.5 (Q2a)
unnamed: Z3.11, Z21.11 (Q2b)
unnamed: Z3.5, Z21.4 (Q3a)
unnamed: R48.1, Z21.12 (Q3b), Z36.4
unnamed: Z36.5, Z37.4
unnamed: Z36.9, Z52.2
unnamed: Z36.6, Z36.10, Z36.12
unnamed: Z52.12, Z74.4
unnamed: Z73.8, Z74.5
unnamed: Z73.9, Z74.8
unnamed: Z73.10, Z74.11

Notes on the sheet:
38xx..3Bxx
5xxx
4xxx
0001
0000
0111
RAS=0 && A15=0
7xxx
0xxx, 2xxx
2xxx
0100
0xxx, 1xxx
0011
4xxx..7xxx
0010
0101
3Cxx..3Fxx
0xxx
A14=0
A14=1
0110
6xxx
1xxx
3xxx

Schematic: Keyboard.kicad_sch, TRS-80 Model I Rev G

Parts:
J100: Connection Mainboard Side; TRS80_Model_I_Keyboard_Connector

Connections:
+5V: J100.1; also elsewhere on the board
/A0: J100.5; also elsewhere on the board
/A1: J100.4; also elsewhere on the board
/A2: J100.6; also elsewhere on the board
/A3: J100.9; also elsewhere on the board
/A4: J100.2; also elsewhere on the board
/A5: J100.3; also elsewhere on the board
/A6: J100.7; also elsewhere on the board
/A7: J100.8; also elsewhere on the board
/Address Decoder/~KYBD: J100.14; also elsewhere on the board
/D0: J100.11; also elsewhere on the board
/D1: J100.16; also elsewhere on the board
/D3: J100.13; also elsewhere on the board
/D4: J100.18; also elsewhere on the board
/D5: J100.12; also elsewhere on the board
/D7: J100.17; also elsewhere on the board

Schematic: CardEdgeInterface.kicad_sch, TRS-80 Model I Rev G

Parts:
J4: Edge Connector; TRS80_Model_I_Edge_Connector
R50, R51, R58: 4.7k; TRS80_Model_I_R_0.25W

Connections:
+5V: R50.1, R51.1, R58.1; also elsewhere on the board
/A0: J4.25; also elsewhere on the board
/A1: J4.27; also elsewhere on the board
/A2: J4.40; also elsewhere on the board
/A3: J4.34; also elsewhere on the board
/A4: J4.31; also elsewhere on the board
/A5: J4.35; also elsewhere on the board
/A6: J4.38; also elsewhere on the board
/A7: J4.36; also elsewhere on the board
/A8: J4.11; also elsewhere on the board
/A9: J4.17; also elsewhere on the board
/A10: J4.4; also elsewhere on the board
/A11: J4.9; also elsewhere on the board
/A12: J4.5; also elsewhere on the board
/A13: J4.6; also elsewhere on the board
/A14: J4.10; also elsewhere on the board
/A15: J4.7; also elsewhere on the board
/Address Decoder/~RAS: J4.1; also elsewhere on the board
/Address Decoder/~RD: J4.15; also elsewhere on the board
/CPU Gating/MUX: J4.16; also elsewhere on the board
/CPU Gating/~CAS: J4.3; also elsewhere on the board
/CPU Gating/~IN: J4.19; also elsewhere on the board
/CPU Gating/~OUT: J4.12; also elsewhere on the board
/CPU Gating/~TEST: J4.23, R58.2; also elsewhere on the board
/CPU Gating/~WR: J4.13; also elsewhere on the board
/CPU/~INTAK: J4.14; also elsewhere on the board
/CPU/~INT: J4.21, R50.2; also elsewhere on the board
/CPU/~SYSRES: J4.2; also elsewhere on the board
/CPU/~WAIT: J4.33, R51.2; also elsewhere on the board
/D0: J4.30; also elsewhere on the board
/D1: J4.22; also elsewhere on the board
/D3: J4.26; also elsewhere on the board
/D4: J4.18; also elsewhere on the board
/D5: J4.28; also elsewhere on the board
/D7: J4.20; also elsewhere on the board

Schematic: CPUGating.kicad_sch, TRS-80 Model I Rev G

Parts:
Z22, Z38, Z39, Z55, Z72, Z75, Z76: 74LS367; TRS80_Model_I_DIP16
Z52: 74LS04; TRS80_Model_I_DIP14

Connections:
+5V: Z22.16 (VCC), Z38.16 (VCC), Z39.16 (VCC), Z55.16 (VCC), Z75.16 (VCC), Z76.16 (VCC); also elsewhere on the board
/A0: Z55.11; also elsewhere on the board
/A1: Z55.13; also elsewhere on the board
/A2: Z22.11; also elsewhere on the board
/A3: Z22.13; also elsewhere on the board
/A4: Z39.7; also elsewhere on the board
/A5: Z39.9; also elsewhere on the board
/A6: Z39.5; also elsewhere on the board
/A7: Z39.11; also elsewhere on the board
/A8: Z39.3; also elsewhere on the board
/A9: Z39.13; also elsewhere on the board
/A10: Z38.3; also elsewhere on the board
/A11: Z38.13; also elsewhere on the board
/A12: Z38.5; also elsewhere on the board
/A13: Z38.7; also elsewhere on the board
/A14: Z38.11; also elsewhere on the board
/A15: Z38.9; also elsewhere on the board
/Address Decoder/~RAS: Z72.5; also elsewhere on the board
/Address Decoder/~RD: Z22.7; also elsewhere on the board
/CPU Gating/MUX: Z72.3; also elsewhere on the board
/CPU Gating/ZA0: Z55.12; also elsewhere on the board
/CPU Gating/ZA1: Z55.14; also elsewhere on the board
/CPU Gating/ZA2: Z22.12; also elsewhere on the board
/CPU Gating/ZA3: Z22.14; also elsewhere on the board
/CPU Gating/ZA4: Z39.6; also elsewhere on the board
/CPU Gating/ZA5: Z39.10; also elsewhere on the board
/CPU Gating/ZA6: Z39.4; also elsewhere on the board
/CPU Gating/ZA7: Z39.12; also elsewhere on the board
/CPU Gating/ZA8: Z39.2; also elsewhere on the board
/CPU Gating/ZA9: Z39.14; also elsewhere on the board
/CPU Gating/ZA10: Z38.2; also elsewhere on the board
/CPU Gating/ZA11: Z38.14; also elsewhere on the board
/CPU Gating/ZA12: Z38.4; also elsewhere on the board
/CPU Gating/ZA13: Z38.6; also elsewhere on the board
/CPU Gating/ZA14: Z38.12; also elsewhere on the board
/CPU Gating/ZA15: Z38.10; also elsewhere on the board
/CPU Gating/ZD0: Z76.9, Z76.12; also elsewhere on the board
/CPU Gating/ZD1: Z76.3, Z76.14; also elsewhere on the board
/CPU Gating/ZD2: Z75.14, Z76.5; also elsewhere on the board
/CPU Gating/ZD3: Z55.5, Z75.4; also elsewhere on the board
/CPU Gating/ZD4: Z55.3, Z75.6; also elsewhere on the board
/CPU Gating/ZD5: Z55.7, Z75.2; also elsewhere on the board
/CPU Gating/ZD6: Z55.9, Z75.10; also elsewhere on the board
/CPU Gating/ZD7: Z75.12, Z76.7; also elsewhere on the board
/CPU Gating/ZMUX: Z72.2; also elsewhere on the board
/CPU Gating/~CAS: Z72.9; also elsewhere on the board
/CPU Gating/~DBIN: Z55.1, Z76.1; also elsewhere on the board
/CPU Gating/~DBOUT: Z75.1, Z75.15, Z76.15; also elsewhere on the board
/CPU Gating/~IN: Z22.9; also elsewhere on the board
/CPU Gating/~OUT: Z22.3; also elsewhere on the board
/CPU Gating/~TEST: Z52.3; also elsewhere on the board
/CPU Gating/~WR: Z22.5; also elsewhere on the board
/CPU Gating/~ZCAS: Z72.10; also elsewhere on the board
/CPU Gating/~ZIN: Z22.10; also elsewhere on the board
/CPU Gating/~ZOUT: Z22.2; also elsewhere on the board
/CPU Gating/~ZRAS: Z72.4; also elsewhere on the board
/CPU Gating/~ZRD: Z22.6; also elsewhere on the board
/CPU Gating/~ZWR: Z22.4; also elsewhere on the board
/D0: Z76.10, Z76.11; also elsewhere on the board
/D1: Z76.2, Z76.13; also elsewhere on the board
/D3: Z55.4, Z75.5; also elsewhere on the board
/D4: Z55.2, Z75.7; also elsewhere on the board
/D5: Z55.6, Z75.3; also elsewhere on the board
/D7: Z75.11, Z76.6; also elsewhere on the board
unnamed: Z22.1, Z22.15, Z38.1, Z38.15, Z39.1, Z39.15, Z52.4, Z55.15, Z72.1

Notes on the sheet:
Bi-directional Data Bus
Address Bus
Control Signals

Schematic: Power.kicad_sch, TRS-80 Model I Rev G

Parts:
C1: 220uF 16V; TRS80_Model_I_C_Pol_Axial_21L_9W_29P
C3, C14, C15: 0.01uF 24V; TRS80_Model_I_C_Disc_9.5L_4W_6P_Small
C4, C10, C11: 10uF 16V; TRS80_Model_I_C_Pol_Radial_5D_2.5P
C8: 2200uF 35V; TRS80_Model_I_C_Pol_Axial_41L_19W_48P
C9: 10000uF 16V; TRS80_Model_I_C_Pol_Axial_63L_25W_71P
C12, C13: 470pF; TRS80_Model_I_C_Disc_9.5L_4W_6P_Small
CR1: 1N4735; TRS80_Model_I_D
CR2: 1N5231; TRS80_Model_I_D
CR8: MDA202; TRS80_Model_I_D_Bridge
J1: Front View; TRS80_Model_I_DIN5
Q3: TIP29A; TRS80_Model_I_Q_Box_BCE
Q4: 2N6594; TRS80_Model_I_Q_Heatsink_Large_BEC
Q5: 2N3906; TRS80_Model_I_Q_Circle_EBC
Q6: MJE34; TRS80_Model_I_Q_Heatsink_Small_BCE
R1: 68; TRS80_Model_I_R_0.25W
R2: 2.7k; TRS80_Model_I_R_0.25W
R3: 750; TRS80_Model_I_R_0.25W
R4: 0.33; TRS80_Model_I_R_2W
R5, R10: 1k; TRS80_Model_I_R_Pot
R6, R7, R16: 1.2k; TRS80_Model_I_R_0.25W
R8: 100k; TRS80_Model_I_R_0.25W
R9, R11, R12: 3.3k; TRS80_Model_I_R_0.25W
R13: 2.2k; TRS80_Model_I_R_0.25W
R14: 12k; TRS80_Model_I_R_0.25W
R15: 1.5k; TRS80_Model_I_R_0.25W
R17: 2k; TRS80_Model_I_R_0.25W
R18: 5.6; TRS80_Model_I_R_3W
R19: 220; TRS80_Model_I_R_0.5W
S1: TRS80_Model_I_Sw_Large
Z1, Z2: LM723C; TRS80_Model_I_DIP14

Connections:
+5V: C10.1, C14.1, CR1.1 (K), R4.2, R7.1, R8.2, Z1.3 (CSEN); also elsewhere on the board
+12V: C11.1, C15.1, R13.1, R18.1, Z1.11 (VC), Z1.12 (V+), Z2.3 (CSEN); also elsewhere on the board
-5V: C3.1, C4.2, CR2.2 (A), R19.1; also elsewhere on the board
unnamed: C1.2, R19.2, S1.10
unnamed: CR8.1 (+), S1.4, S1.5, S1.8, S1.9
unnamed: CR8.4 (-), S1.11, S1.12
unnamed: CR8.2, J1.1
unnamed: CR8.3, J1.3
unnamed: J1.2, S1.1, S1.2
unnamed: Q3.1 (B), R2.1, Z1.10 (Vout)
unnamed: Q3.2 (C), Q4.1 (B), R1.2
unnamed: Q3.3 (E), Q4.3 (C), R2.2, R3.1, R4.1
unnamed: C9.1, Q4.2 (E), R1.1, S1.6, S1.7
unnamed: Q5.2 (B), R8.1
unnamed: Q5.3 (C), R9.2
unnamed: Q5.1 (E), R5.2, Z1.5 (+)
unnamed: Q6.1 (B), R16.2, Z2.11 (VC)
unnamed: Q6.2 (C), R17.1, R18.2, Z2.10 (Vout)
unnamed: C8.1, Q6.3 (E), R16.1, S1.3, Z2.12 (V+)
unnamed: R5.1, R6.1
unnamed: R10.1, R12.1
unnamed: R10.3, R13.2
unnamed: R5.3, R11.1
unnamed: C12.1, R7.2, Z1.4 (-)
unnamed: C12.2, Z1.13 (FC)
unnamed: R3.2, R9.1, Z1.2 (ILIM)
unnamed: R6.2, Z1.6 (VREF)
unnamed: R15.2, Z2.5 (+)
unnamed: C13.2, R10.2, Z2.4 (-)
unnamed: C13.1, Z2.13 (FC)
unnamed: R14.1, R17.2, Z2.2 (ILIM)
unnamed: R15.1, Z2.6 (VREF)

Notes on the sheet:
12V-20V AC 1A
0.5W
14V-20V DC 350mA

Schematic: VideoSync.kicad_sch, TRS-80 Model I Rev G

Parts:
C20: 330pF; TRS80_Model_I_C_Disc_9.5L_4W_6P_Small
C21: 750pF; TRS80_Model_I_C_Disc_9.5L_4W_6P_Small
C26: 0.047uF; TRS80_Model_I_C_Box_11L_5W_6P_Large
C27: 0.022uF; TRS80_Model_I_C_Box_7.5L_5W_4.5P_Small
R20, R21: 100k; TRS80_Model_I_R_Pot
R43, R44: 10k; TRS80_Model_I_R_0.25W
Z5: 74C00; TRS80_Model_I_DIP14
Z6, Z57: 74C04; TRS80_Model_I_DIP14

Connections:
+5V: Z5.14 (VCC), Z6.14 (VCC), Z57.14 (VCC); also elsewhere on the board
/Video/Video Counter/HDRV: Z6.13; also elsewhere on the board
/Video/Video Counter/VDRV: Z57.1; also elsewhere on the board
/Video/Video Mixer/SYNC: Z5.8; also elsewhere on the board
unnamed: C20.1, R20.2, Z6.3
unnamed: C20.2, C21.1, Z6.6
unnamed: C21.2, R43.1, Z6.11
unnamed: C26.1, R21.2, Z57.13
unnamed: C26.2, C27.1, Z57.10
unnamed: C27.2, R44.2, Z57.5
unnamed: R20.1, Z6.2
unnamed: R21.1, Z57.4
unnamed: Z5.1, Z5.5, Z57.8
unnamed: Z5.6, Z5.9
unnamed: Z5.10, Z5.11
unnamed: Z5.3, Z5.4, Z5.12
unnamed: Z5.2, Z5.13, Z6.8
unnamed: Z6.1, Z6.12
unnamed: Z6.4, Z6.5
unnamed: Z6.9, Z6.10
unnamed: Z57.2, Z57.3
unnamed: Z57.6, Z57.9
unnamed: Z57.11, Z57.12

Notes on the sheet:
Amplifier
Sync Offset
H-Sync
V-Sync Offset Capacitor
V-Sync
Inv-Sync
H-Sync Offset Capacitor
Sync Pulse Length
V-Sync Length
V-Sync Offset Resistor
H-Sync Length
Combine Sync Signals
H-Sync Offset Resistor

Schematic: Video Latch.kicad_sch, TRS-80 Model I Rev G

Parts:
R39: 4.7k; TRS80_Model_I_R_0.25W
Z7: 74LS74; TRS80_Model_I_DIP14
Z27: 74LS175; TRS80_Model_I_DIP16
Z28: 74LS174; TRS80_Model_I_DIP16
Z30: 74LS02; TRS80_Model_I_DIP14
Z42: 74LS04; TRS80_Model_I_DIP14

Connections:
+5V: R39.2, Z7.14 (VCC), Z27.16 (VCC), Z28.16 (VCC); also elsewhere on the board
/Address Decoder/~VID: Z7.4 (~S); also elsewhere on the board
/Video/Video Counter/HDRV: Z30.8; also elsewhere on the board
/Video/Video Counter/L3: Z27.12 (D2); also elsewhere on the board
/Video/Video Counter/VDRV: Z30.9; also elsewhere on the board
/Video/Video Counter/~LATCH: Z7.3 (C), Z27.9 (Cp), Z28.9 (Cp); also elsewhere on the board
/Video/Video Generator/GRAPHICS: Z27.3 (~Q0); also elsewhere on the board
/Video/Video Generator/LB0: Z28.15 (Q5); also elsewhere on the board
/Video/Video Generator/LB1: Z28.12 (Q4); also elsewhere on the board
/Video/Video Generator/LB2: Z28.2 (Q0); also elsewhere on the board
/Video/Video Generator/LB3: Z28.7 (Q2); also elsewhere on the board
/Video/Video Generator/LB4: Z28.5 (Q1); also elsewhere on the board
/Video/Video Generator/LB5: Z28.10 (Q3); also elsewhere on the board
/Video/Video Generator/LB6: Z27.15 (Q3); also elsewhere on the board
/Video/Video Generator/~BLANK: Z27.7 (Q1); also elsewhere on the board
/Video/Video Generator/~CHARGAP: Z27.11 (~Q2); also elsewhere on the board
/Video/Video Generator/~GRAPHICS: Z27.2 (Q0); also elsewhere on the board
/Video/Video Latch/VD0: Z28.14 (D5); also elsewhere on the board
/Video/Video Latch/VD1: Z28.13 (D4); also elsewhere on the board
/Video/Video Latch/VD2: Z28.3 (D0); also elsewhere on the board
/Video/Video Latch/VD3: Z28.6 (D2); also elsewhere on the board
/Video/Video Latch/VD4: Z28.4 (D1); also elsewhere on the board
/Video/Video Latch/VD5: Z28.11 (D3); also elsewhere on the board
/Video/Video Latch/VD6: Z27.13 (D3); also elsewhere on the board
/Video/Video Latch/VD7: Z42.13; also elsewhere on the board
/Video/Video Latch/~VCLR: Z7.6 (~Q), Z27.1 (~Mr), Z28.1 (~Mr)
unnamed: R39.1, Z7.1 (~R)
unnamed: Z27.4 (D0), Z42.12
unnamed: Z27.5 (D1), Z30.10

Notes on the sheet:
CHARGAP
GRAPHICS
Clear when CPU drives
~{BLANK}
~{GRAPHICS}

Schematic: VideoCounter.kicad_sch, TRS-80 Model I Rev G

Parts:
R63: 4.7k; TRS80_Model_I_R_0.25W
Z12, Z32, Z50, Z65: 74LS93; TRS80_Model_I_DIP14
Z24: 74LS132; TRS80_Model_I_DIP14
Z43: 74LS157; TRS80_Model_I_DIP16
Z58: 74LS92; TRS80_Model_I_DIP14
Z66: 74LS11; TRS80_Model_I_DIP14
Z70: 74LS74; TRS80_Model_I_DIP14

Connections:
+5V: R63.1, Z12.5 (VCC), Z32.5 (VCC), Z43.16 (VCC), Z50.5 (VCC), Z58.5 (VCC), Z65.5 (VCC), Z66.14 (VCC); also elsewhere on the board
/CPU/CLK: Z43.3 (I1a), Z70.11 (C); also elsewhere on the board
/CPU/HI: Z70.10 (~S); also elsewhere on the board
/Video/Video Access Multiplexer/C0: Z43.7 (Zb); also elsewhere on the board
/Video/Video Access Multiplexer/C1: Z65.9 (Q1); also elsewhere on the board
/Video/Video Access Multiplexer/C2: Z50.14 (CP0), Z65.8 (Q2); also elsewhere on the board
/Video/Video Access Multiplexer/C3: Z50.1 (CP1..3), Z50.12 (Q0); also elsewhere on the board
/Video/Video Access Multiplexer/C4: Z50.9 (Q1), Z66.3; also elsewhere on the board
/Video/Video Access Multiplexer/C5: Z50.8 (Q2), Z66.5; also elsewhere on the board
/Video/Video Access Multiplexer/R0: Z32.14 (CP0), Z65.12 (Q0); also elsewhere on the board
/Video/Video Access Multiplexer/R1: Z32.1 (CP1..3), Z32.12 (Q0), Z66.13; also elsewhere on the board
/Video/Video Access Multiplexer/R2: Z32.9 (Q1), Z66.2; also elsewhere on the board
/Video/Video Access Multiplexer/R3: Z32.8 (Q2); also elsewhere on the board
/Video/Video Counter/HDRV: Z12.14 (CP0), Z50.11 (Q3), Z66.4; also elsewhere on the board
/Video/Video Counter/L0: Z12.1 (CP1..3), Z12.12 (Q0); also elsewhere on the board
/Video/Video Counter/L1: Z12.9 (Q1); also elsewhere on the board
/Video/Video Counter/L2: Z12.8 (Q2), Z66.9, Z66.10; also elsewhere on the board
/Video/Video Counter/L3: Z12.11 (Q3), Z65.14 (CP0), Z66.11; also elsewhere on the board
/Video/Video Counter/VDRV: Z32.11 (Q3), Z66.1; also elsewhere on the board
/Video/Video Counter/~LATCH: Z24.3; also elsewhere on the board
unnamed: Z12.2 (R0(1)), Z12.3 (R0(2)), Z66.8
unnamed: Z32.2 (R0(1)), Z32.3 (R0(2)), Z66.12
unnamed: Z43.2 (I0a), Z70.9 (Q)
unnamed: Z24.2, Z43.11 (I0c), Z58.9 (Q2)
unnamed: Z43.6 (I1b), Z43.10 (I1c), Z58.8 (Q3)
unnamed: Z43.9 (Zc), Z65.1 (CP1..3)
unnamed: Z50.2 (R0(1)), Z50.3 (R0(2)), Z66.6
unnamed: Z24.1, Z58.1 (CP1..3), Z58.12 (Q0)
unnamed: Z70.8 (~Q), Z70.12 (D)
unnamed: R63.2, Z70.13 (~R)

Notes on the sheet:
BIT 1
7.92 kHz
CLK/2
660 Hz
CP0/2
1.98 kHz
60 Hz
887.042 kHz
1.32 kHz
Character line counter
82.5 Hz
27.72 kHz
Mode Selector
CP0/11
3.96 kHz
110.88 kHz
CP1/4
221.76 kHz
55.44 kHz
15.84 kHz
CP0/6
CP0/12
BIT 3
330 Hz
Column counter
Row counter
10.6445 MHz
5.322 MHz
443.52 kHz
CP0/14
165 Hz
Every 6th count

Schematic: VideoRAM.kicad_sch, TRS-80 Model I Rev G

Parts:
Z30: 74LS02; TRS80_Model_I_DIP14
Z44, Z60: 74LS367; TRS80_Model_I_DIP16
Z45, Z46, Z47, Z48, Z61, Z62, Z63: 2102; DIP-16_W7.62mm

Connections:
+5V: Z45.10 (VCC), Z46.10 (VCC), Z47.10 (VCC), Z48.10 (VCC), Z60.16 (VCC), Z61.10 (VCC), Z62.10 (VCC), Z63.10 (VCC); also elsewhere on the board
/D0: Z44.7, Z48.11 (IN); also elsewhere on the board
/D1: Z44.5, Z47.11 (IN); also elsewhere on the board
/D3: Z44.9, Z45.11 (IN); also elsewhere on the board
/D4: Z60.9, Z61.11 (IN); also elsewhere on the board
/D5: Z60.7, Z62.11 (IN); also elsewhere on the board
/D7: Z60.3, Z63.11 (IN); also elsewhere on the board
/Video/Video Access Multiplexer/VA0: Z45.8 (A0), Z46.8 (A0), Z47.8 (A0), Z48.8 (A0), Z61.8 (A0), Z62.8 (A0), Z63.8 (A0); also elsewhere on the board
/Video/Video Access Multiplexer/VA1: Z45.4 (A1), Z46.4 (A1), Z47.4 (A1), Z48.4 (A1), Z61.4 (A1), Z62.4 (A1), Z63.4 (A1); also elsewhere on the board
/Video/Video Access Multiplexer/VA2: Z45.5 (A2), Z46.5 (A2), Z47.5 (A2), Z48.5 (A2), Z61.5 (A2), Z62.5 (A2), Z63.5 (A2); also elsewhere on the board
/Video/Video Access Multiplexer/VA3: Z45.6 (A3), Z46.6 (A3), Z47.6 (A3), Z48.6 (A3), Z61.6 (A3), Z62.6 (A3), Z63.6 (A3); also elsewhere on the board
/Video/Video Access Multiplexer/VA4: Z45.7 (A4), Z46.7 (A4), Z47.7 (A4), Z48.7 (A4), Z61.7 (A4), Z62.7 (A4), Z63.7 (A4); also elsewhere on the board
/Video/Video Access Multiplexer/VA5: Z45.2 (A5), Z46.2 (A5), Z47.2 (A5), Z48.2 (A5), Z61.2 (A5), Z62.2 (A5), Z63.2 (A5); also elsewhere on the board
/Video/Video Access Multiplexer/VA6: Z45.1 (A6), Z46.1 (A6), Z47.1 (A6), Z48.1 (A6), Z61.1 (A6), Z62.1 (A6), Z63.1 (A6); also elsewhere on the board
/Video/Video Access Multiplexer/VA7: Z45.16 (A7), Z46.16 (A7), Z47.16 (A7), Z48.16 (A7), Z61.16 (A7), Z62.16 (A7), Z63.16 (A7); also elsewhere on the board
/Video/Video Access Multiplexer/VA8: Z45.15 (A8), Z46.15 (A8), Z47.15 (A8), Z48.15 (A8), Z61.15 (A8), Z62.15 (A8), Z63.15 (A8); also elsewhere on the board
/Video/Video Access Multiplexer/VA9: Z45.14 (A9), Z46.14 (A9), Z47.14 (A9), Z48.14 (A9), Z61.14 (A9), Z62.14 (A9), Z63.14 (A9); also elsewhere on the board
/Video/Video Access Multiplexer/~VRD: Z44.1, Z60.1; also elsewhere on the board
/Video/Video Access Multiplexer/~VWR: Z45.3 (R/~W), Z46.3 (R/~W), Z47.3 (R/~W), Z48.3 (R/~W), Z61.3 (R/~W), Z62.3 (R/~W), Z63.3 (R/~W); also elsewhere on the board
/Video/Video Latch/VD0: Z44.6, Z48.12 (OUT); also elsewhere on the board
/Video/Video Latch/VD1: Z44.4, Z47.12 (OUT); also elsewhere on the board
/Video/Video Latch/VD2: Z44.2, Z46.12 (OUT); also elsewhere on the board
/Video/Video Latch/VD3: Z44.10, Z45.12 (OUT); also elsewhere on the board
/Video/Video Latch/VD4: Z60.10, Z61.12 (OUT); also elsewhere on the board
/Video/Video Latch/VD5: Z30.12, Z60.6, Z62.12 (OUT); also elsewhere on the board
/Video/Video Latch/VD6: Z30.13, Z60.4; also elsewhere on the board
/Video/Video Latch/VD7: Z30.11, Z60.2, Z63.12 (OUT); also elsewhere on the board

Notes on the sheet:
Derived BIT 6
BIT 5
BIT 7

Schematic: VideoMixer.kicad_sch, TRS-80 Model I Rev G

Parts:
C2: 10uF 16V; TRS80_Model_I_C_Pol_Radial_5D_2.5P
C7: 0.01uF 24V; TRS80_Model_I_C_Disc_9.5L_4W_6P_Small
J2: Front View; TRS80_Model_I_DIN5
Q1: 2N3904; TRS80_Model_I_Q_Circle_EBC
Q2: 2N3906; TRS80_Model_I_Q_Circle_EBC
R22: 75; TRS80_Model_I_R_0.25W
R23: 120; TRS80_Model_I_R_0.25W
R27: 330; TRS80_Model_I_R_0.25W
R28: 270; TRS80_Model_I_R_0.25W
R29: 1.8k; TRS80_Model_I_R_0.25W
R30: 47; TRS80_Model_I_R_0.25W
Z41: 75452; TRS80_Model_I_DIP8

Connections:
+5V: J2.1, Q2.1 (E), R30.1; also elsewhere on the board
/Video/Video Generator/PIXEL: Z41.6 (2A), Z41.7 (2B); also elsewhere on the board
/Video/Video Mixer/SYNC: R29.1; also elsewhere on the board
unnamed: Q1.2 (B), R23.1, R27.1, R28.2
unnamed: C2.1, C7.1, Q1.3 (C), R30.2
unnamed: J2.4, Q1.1 (E), R22.1
unnamed: Q2.2 (B), R29.2
unnamed: Q2.3 (C), R28.1
unnamed: R23.2, Z41.5 (2Y)

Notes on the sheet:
Q2 open, Z41 any => 0V (sync level) Q2 closed, Z41 closed => 1.23V (black level) - R28 with series resistors R23 & R27 Q2 closed, Z41 open => 2.75V (white level) - Only R27 & R28

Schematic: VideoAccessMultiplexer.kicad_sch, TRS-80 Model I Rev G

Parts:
R49: 4.7k; TRS80_Model_I_R_0.25W
Z31, Z49, Z64: 74LS157; TRS80_Model_I_DIP16

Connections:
+5V: R49.1, Z31.16 (VCC), Z49.16 (VCC), Z64.16 (VCC); also elsewhere on the board
/A0: Z64.11 (I0c); also elsewhere on the board
/A1: Z64.2 (I0a); also elsewhere on the board
/A2: Z64.14 (I0d); also elsewhere on the board
/A3: Z64.5 (I0b); also elsewhere on the board
/A4: Z49.11 (I0c); also elsewhere on the board
/A5: Z49.2 (I0a); also elsewhere on the board
/A6: Z31.11 (I0c); also elsewhere on the board
/A7: Z31.14 (I0d); also elsewhere on the board
/A8: Z31.2 (I0a); also elsewhere on the board
/A9: Z31.5 (I0b); also elsewhere on the board
/Address Decoder/~RD: Z49.5 (I0b); also elsewhere on the board
/Address Decoder/~VID: Z31.1 (S), Z49.1 (S), Z64.1 (S); also elsewhere on the board
/CPU Gating/~WR: Z49.14 (I0d); also elsewhere on the board
/Video/Video Access Multiplexer/C0: Z64.10 (I1c); also elsewhere on the board
/Video/Video Access Multiplexer/C1: Z64.3 (I1a); also elsewhere on the board
/Video/Video Access Multiplexer/C2: Z64.13 (I1d); also elsewhere on the board
/Video/Video Access Multiplexer/C3: Z64.6 (I1b); also elsewhere on the board
/Video/Video Access Multiplexer/C4: Z49.10 (I1c); also elsewhere on the board
/Video/Video Access Multiplexer/C5: Z49.3 (I1a); also elsewhere on the board
/Video/Video Access Multiplexer/R0: Z31.10 (I1c); also elsewhere on the board
/Video/Video Access Multiplexer/R1: Z31.13 (I1d); also elsewhere on the board
/Video/Video Access Multiplexer/R2: Z31.3 (I1a); also elsewhere on the board
/Video/Video Access Multiplexer/R3: Z31.6 (I1b); also elsewhere on the board
/Video/Video Access Multiplexer/VA0: Z64.9 (Zc); also elsewhere on the board
/Video/Video Access Multiplexer/VA1: Z64.4 (Za); also elsewhere on the board
/Video/Video Access Multiplexer/VA2: Z64.12 (Zd); also elsewhere on the board
/Video/Video Access Multiplexer/VA3: Z64.7 (Zb); also elsewhere on the board
/Video/Video Access Multiplexer/VA4: Z49.9 (Zc); also elsewhere on the board
/Video/Video Access Multiplexer/VA5: Z49.4 (Za); also elsewhere on the board
/Video/Video Access Multiplexer/VA6: Z31.9 (Zc); also elsewhere on the board
/Video/Video Access Multiplexer/VA7: Z31.12 (Zd); also elsewhere on the board
/Video/Video Access Multiplexer/VA8: Z31.4 (Za); also elsewhere on the board
/Video/Video Access Multiplexer/VA9: Z31.7 (Zb); also elsewhere on the board
/Video/Video Access Multiplexer/~VRD: Z49.7 (Zb); also elsewhere on the board
/Video/Video Access Multiplexer/~VWR: Z49.12 (Zd); also elsewhere on the board
unnamed: R49.2, Z49.6 (I1b), Z49.13 (I1d)

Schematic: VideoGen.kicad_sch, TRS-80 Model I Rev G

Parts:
R40: 4.7k; TRS80_Model_I_R_0.25W
Z8: 74LS153; TRS80_Model_I_DIP16
Z9, Z42: 74LS04; TRS80_Model_I_DIP14
Z10, Z11: 74LS166; TRS80_Model_I_DIP16
Z26: 74LS20; TRS80_Model_I_DIP14
Z29: MCM6670; DIP-18_W7.62mm
Z30: 74LS02; TRS80_Model_I_DIP14

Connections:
+5V: R40.2, Z8.16 (VCC), Z9.14 (VCC), Z10.16 (VCC), Z11.16 (VCC), Z26.14 (VCC), Z29.18 (VCC); also elsewhere on the board
/Video/Video Counter/L0: Z29.11 (R0); also elsewhere on the board
/Video/Video Counter/L1: Z29.10 (R1); also elsewhere on the board
/Video/Video Counter/L2: Z8.14 (S0), Z29.8 (R2); also elsewhere on the board
/Video/Video Counter/L3: Z8.2 (S1); also elsewhere on the board
/Video/Video Counter/~LATCH: Z9.3; also elsewhere on the board
/Video/Video Generator/GRAPHICS: Z26.4; also elsewhere on the board
/Video/Video Generator/LB0: Z8.6 (I0a), Z29.7 (A0); also elsewhere on the board
/Video/Video Generator/LB1: Z8.10 (I0b), Z29.6 (A1); also elsewhere on the board
/Video/Video Generator/LB2: Z8.5 (I1a), Z29.5 (A2); also elsewhere on the board
/Video/Video Generator/LB3: Z8.11 (I1b), Z29.4 (A3); also elsewhere on the board
/Video/Video Generator/LB4: Z8.4 (I2a), Z29.3 (A4); also elsewhere on the board
/Video/Video Generator/LB5: Z8.12 (I2b), Z29.2 (A5); also elsewhere on the board
/Video/Video Generator/LB6: Z29.1 (A6); also elsewhere on the board
/Video/Video Generator/PIXEL: Z30.1; also elsewhere on the board
/Video/Video Generator/~BLANK: Z26.1, Z26.2, Z26.9; also elsewhere on the board
/Video/Video Generator/~CHARGAP: Z26.12; also elsewhere on the board
/Video/Video Generator/~GRAPHICS: Z26.10; also elsewhere on the board
unnamed 194: Z42.9; also elsewhere on the board
unnamed: Z10.4 (C), Z29.12 (D0)
unnamed: R40.1, Z10.9 (Clr), Z11.9 (Clr)
unnamed: Z10.5 (D), Z29.13 (D1)
unnamed: Z10.10 (E), Z29.14 (D2)
unnamed: Z10.11 (F), Z29.15 (D3)
unnamed: Z10.12 (G), Z29.16 (D4)
unnamed: Z10.15 (PE), Z26.8
unnamed: Z10.13 (Qh), Z30.3
unnamed: Z8.9 (Zb), Z11.4 (C), Z11.5 (D), Z11.10 (E)
unnamed: Z8.7 (Za), Z11.11 (F), Z11.12 (G), Z11.14 (H)
unnamed: Z11.15 (PE), Z26.6
unnamed: Z11.13 (Qh), Z30.2
unnamed: Z9.4, Z26.5, Z26.13

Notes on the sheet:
ASCII
Character Generators: - Motorola 3108001 (floating "a") - Motorola MCM6670 (fixed floating "a") - Motorola 8046673 SCM37530 (latest)
SHIFT/~{LOAD}
LATCH
Right
GRAPHICS PIXEL
Left
Character Generator
GRAPHICS
~{SHIFT}
ASCII PIXEL
Inversed Clock (delays clock)

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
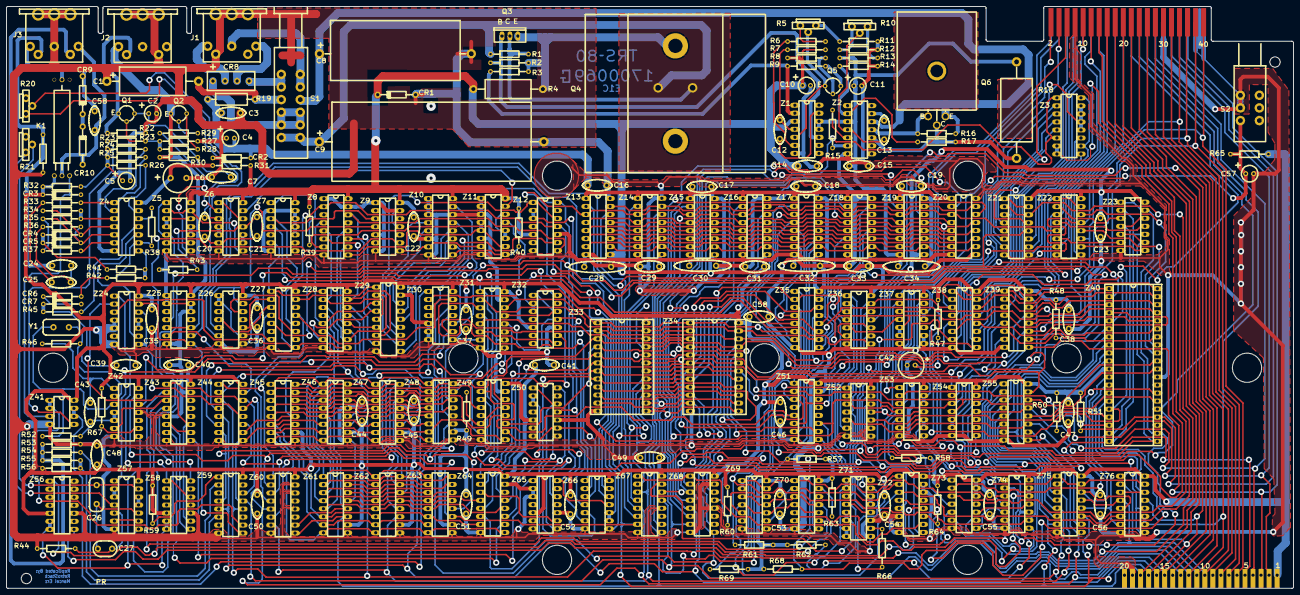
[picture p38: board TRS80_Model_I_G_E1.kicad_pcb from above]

Board: 2 copper layers, 407.0 x 184.0 mm, 230 parts (0 on the bottom side), 311 nets.

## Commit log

2023-12-30 Initial Commit with version E1B
    [AddressDecoder.kicad_sch, CPU.kicad_sch, CPUGating.kicad_sch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]
2024-01-05 Fix CASSIN Flip-Flop description
    [Cassette.kicad_sch]
2024-01-14 Cleanup, Changelog added & Curiosities photos
    [AddressDecoder.kicad_sch, CPU.kicad_sch, CPUGating.kicad_sch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]
2024-01-23 Update BOM
    [TRS80_Model_I_G_E1_BOM.csv]
2024-01-24 Optimizations to BOM
2024-02-21 New labels file and updated BOM
    [Power.kicad_sch, TRS80_Model_I_G_E1.kicad_pcb, TRS80_Model_I_G_E1_BOM.csv]
2024-02-21 Cleanup BOM, add locations and Resistor colors
    [TRS80_Model_I_G_E1_BOM.csv]
2024-03-04 Add assembly guide
2024-03-15 Removal of 2N6287 from BOM
    [TRS80_Model_I_G_E1_BOM.csv]
2024-03-30 Update schematics (correct page flow) and add alternative to Q4 in BOM
    [AddressDecoder.kicad_sch, CPU.kicad_sch, Capacitors.kicad_sch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]
2024-11-30 Updated revision to Rev C
    [AddressDecoder.kicad_sch, CPU.kicad_sch, CPUGating.kicad_sch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]
2024-12-02 Update for revisions
    [TRS80_Model_I_G_E1.kicad_pcb]
2024-12-08 Update Gerber files for latest revision
    [TRS80_Model_I_G_E1.kicad_pcb]
